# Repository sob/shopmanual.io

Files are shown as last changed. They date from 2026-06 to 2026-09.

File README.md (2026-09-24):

# Technical Documentation

This repository contains comprehensive technical documentation for various in-depth projects, built using [MkDocs](https://www.mkdocs.org/) with the [Material theme](https://squidfunk.github.io/mkdocs-material/).

## Projects

- **Jeep LJ Cummins R2.8 Build** - Complete electrical system documentation for engine swap with dual battery system
- **Nissan NV 3500 Van Build** - 12V accessory electrical system: dual AGM batteries, four switch panels, and Starlink on a DC-fed Advanced Power Supply
- **Jeep Wrangler JKU** - Early documentation: Genesis Offroad dual battery system and a SwitchPros SP-9100 switch panel

## Setup

### Prerequisites

- Python 3.9+
- pip

### Installation

```bash
# Install MkDocs and Material theme
pip3 install mkdocs mkdocs-material
```

### Local Development

```bash
# Serve the documentation locally with live reload
mkdocs serve

# Or use the full path if mkdocs is not in PATH
/Users/seobrien/Library/Python/3.9/bin/mkdocs serve
```

The documentation will be available at [http://127.0.0.1:8000](http://127.0.0.1:8000)

### Building

```bash
# Build static site to site/ directory
mkdocs build

# Or use the full path
/Users/seobrien/Library/Python/3.9/bin/mkdocs build
```

## Project Structure

```
.
├── mkdocs.yml              # MkDocs configuration
├── docs/                   # Documentation source files
│   ├── index.md           # Home page
│   └── jeep_lj/           # Jeep LJ project documentation
│       ├── index.md       # Project overview
│       ├── 01-power-generation.md
│       ├── 02-front-battery-distribution.md
│       ├── 03-rear-battery-distribution.md
│       ├── 04-engine-systems.md
│       ├── 05-auxiliary-systems.md
│       ├── 06-cabin-body-control.md
│       ├── 07-cabin-lighting-accessories.md
│       ├── 08-communication-audio.md
│       ├── 09-cargo-exterior.md
│       ├── 10-wire-routing.md
│       └── 11-project-management.md
└── site/                   # Generated static site (not in git)
```

## Adding New Projects

1. Create a new directory under `docs/` (e.g., `docs/new_project/`)
2. Add an `index.md` overview page
3. Create section files as needed
4. Update `mkdocs.yml` navigation to include the new project
5. Run `mkdocs serve` to preview

## Features

- **Material Design** - Clean, responsive design
- **Dark/Light Mode** - Automatic theme switching
- **Search** - Full-text search across all documentation
- **Navigation** - Hierarchical navigation with sections and tabs
- **Code Highlighting** - Syntax highlighting for code blocks
- **Tables** - Full markdown table support
- **Admonitions** - Info, warning, and note callout boxes

## Documentation Best Practices

- Use clear, descriptive headings (H1-H4)
- Include tables of contents for long pages
- Use admonitions for important notes:
  ```markdown
  !!! info "Title"
      Content here

  !!! warning "Title"
      Warning content
  ```
- Cross-reference between pages using relative links:
  ```markdown
  [Link text](../other-section/page.md)
  ```

## Contributing

When adding or updating documentation:

1. Edit the markdown files in `docs/`
2. Test locally with `mkdocs serve`
3. Verify all links work
4. Check formatting and readability
5. Commit changes to git

## License

Documentation for personal projects.

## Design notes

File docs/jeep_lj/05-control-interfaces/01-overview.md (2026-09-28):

---
hide:
  - toc
---

# Control Interfaces - Overview {#control-interfaces-overview}

This section documents all control interfaces in the Jeep LJ build - the switches, controllers, and input devices that allow the driver to control various vehicle systems.

## System Controllers

- **[SwitchPros SP-1200][switchpros-sp-1200-rcr-force-12]** - Main lighting and accessory controller
  - 12-button control panel with Bluetooth app
  - 17 total outputs (12 main + 5 low-side drivers)
  - 150A capacity, fed by Firewall CONSTANT Bus (via 150A CB)
  - Controls all auxiliary lighting and accessories

- **[Command Touch CT4][command-touch-ct4]** - Steering column turn signal and headlight controller
  - 4 programmable outputs for turn signals and headlights
  - GPS module for intelligent turn signal auto-cancel
  - Replaces factory multifunction stalk
  - Controls turn signals, headlights, and high beams

## Physical Switches

- **[Dashboard Controls][dashboard-physical-controls]** - Physical dash-mounted switches
  - Winch control switch
  - Other dash-mounted controls

- **[Keyless Ignition][keyless-ignition]** - RFID + push-button start/stop replacing the factory keyswitch
  - Digital Guard Dawg PBS-I self-contained module with RFID iTag fobs
  - Single dash push-button included with kit
  - Cold-start grid heater preheat: driver waits for the WAIT-to-Start lamp before cranking
  - Emergency Bypass Card with 4-digit PIN (no hidden toggle)

## System Integration

All control interfaces integrate with the dual-battery electrical system:

- **SwitchPros SP-1200:** Powered by Firewall CONSTANT Bus (sourced from AUX battery via 250A master CB + 2/0 AWG forward feed)
- **Command Touch CT4:** Powered by PMU OUT 13 (15A CONSTANT, sourced from START battery), integrates with PMU
- **Dashboard switches:** Various power sources depending on function

## Related Documentation

- **[Vehicle Lighting][vehicle-lighting-overview]** - Complete vehicle lighting circuits controlled by these interfaces
- **[Offroad Lighting][offroad-auxiliary-lighting]** - Auxiliary and offroad lighting controlled by SwitchPros
- **[Engine Systems][pmu-power-distribution]** - PMU power distribution and engine bay subsystems
- **[Horn][horn]** - CT4 kit horn on PMU Out 18 (engine bay component)
- **[Wipers][windshield-wiper-control-system]** - Ron Francis WS-51C wiper controller (engine bay component)

[switchpros-sp-1200-rcr-force-12]: 02-switchpros-sp1200.md
[command-touch-ct4]: 03-command-touch-ct4.md
[dashboard-physical-controls]: 05-dashboard-controls.md
[keyless-ignition]: 06-keyless-ignition.md
[vehicle-lighting-overview]: ../03-lighting-systems/01-lighting-overview.md
[offroad-auxiliary-lighting]: ../04-offroad-lighting/index.md
[pmu-power-distribution]: ../01-power-systems/04-pmu/index.md
[horn]: ../02-engine-systems/05-horn.md
[windshield-wiper-control-system]: ../02-engine-systems/04-wipers.md

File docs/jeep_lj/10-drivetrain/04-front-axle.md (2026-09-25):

---
tags:
  - product-details
  - drivetrain
  - axle
---

# 10.4 - Front Axle {#front-axle}

/// html | div.product-info

**Type:** Dana 60, high pinion (reverse rotation)

**Source:** 2005-2010 Ford F-350 Super Duty, SRW

**Locker:** ARB RD166 Air Locker

**Axle Shafts:** Factory Dana/Spicer 35 spline

///

## Specifications

| Specification | Value |
| :--- | :---- |
| Type | Dana 60, high pinion reverse rotation |
| Source | 2005-2010 Ford F-350 Super Duty (SRW)[^owner-notes] |
| Differential Drop | **Driver's side** (Ford convention)[^axle-drop] |
| Width (WMS) | 69.25"[^owner-notes] |
| Bolt Pattern | 8x170[^owner-notes] |
| Spline Count | 35 inner, 35 outer[^owner-notes] |
| Tube | 3.5" x 0.500" wall[^owner-notes] |
| Knuckles | Factory cast steel |
| Locker | ARB RD166[^rd166] |

## Ring & Pinion

| Specification | Value |
| :--- | :---- |
| Ratio | 5.13 |
| Manufacturer | Revolution Gear |
| Part | D60 reverse, **standard thickness** |
| Install Kit | D60 reverse master install kit |

!!! warning "Gear Thickness"
    ARB RD166 is the 4.56-and-up carrier. Gear must be standard thickness.
    Do **not** order D60-513RT (thick) or the REV-F350-513-K package.

## Differential

| Specification | Value |
| :--- | :---- |
| Locker | ARB RD166 Air Locker[^rd166] |
| Spline | 35 |
| Carrier Series | 4-series (4.56 & up)[^rd166] |
| Control | Front locker dash switch (fed from the rear switch) |

See [Air Lockers][air-lockers] for wiring, air line routing, and operation.

## Axle Shafts

| Specification | Value |
| :--- | :---- |
| Manufacturer | Dana/Spicer (factory) |
| Spline Count | 35 |
| U-Joint | Spicer SPL55-3X[^owner-notes] |
| Quantity | 4 (2 installed, 2 spare) |

Stock shafts retained. Chromoly and 1550-series joints deferred: the 8" ram
caps steering at 40 degrees, which is where factory 1480-series joints bind,
so larger joints buy no usable angle. Bolt-in upgrade if shafts prove
marginal.[^shafts]

## Hubs

| Specification | Value |
| :--- | :---- |
| Type | Yukon Hardcore manual locking |
| Part | YHC70011[^owner-notes] |
| Spline | 35 |
| Engagement | 1/3 turn |

Factory wheel end retained. Yukon hubs replace factory lockouts. No free-spin
conversion required.

## Ball Joints

| Specification | Value |
| :--- | :---- |
| Type | American Iron ball joint delete |
| Style | Press-fit, welded per AI instructions |
| Bushing Offset | {{ tbd(298) }} (0, 1.5, or 3 degree) |
| Hardware | AI-1900 trail hardware kit |

Upper and lower both required. Lower addresses shaft push-out on breakage.[^bje]

!!! info "Caster Adjustment"
    Bushing offset sets caster and camber together, summing to the bushing
    rating. Every 15 degrees of bushing rotation gives 0.5 degrees of change on
    a 3-degree set. Buying caster at the knuckle avoids rotating the inner Cs,
    which would also rotate the pinion.

## Inner Cs

Factory inner Cs retained, no gussets. Accepted deviation from the
weld-once-for-future-power principle. Revisit only with an engine change.[^bje]

## Housing Preparation

| Item | Part |
| :--- | :--- |
| Truss | Motobilt |
| Differential Cover | Motobilt |
| Pinion Yoke | 1350, 29 spline, strap style[^owner-notes] |
| Breather | Relocated; braided line routed high into the engine bay |

All welding completed before internals installed.

!!! info "ABS and Tone Ring"
    No ABS on this build; speed is GPS-sourced via the Dakota Digital
    [GPS-50-2][bim-gps]. Tone rings omitted. The wheel-end sensor openings take
    Riffraff Diesel **RDPABS** grease-able block-off fittings, **two required**
    — one per knuckle, sold individually.[^abs-plug] These open into the wheel
    end rather than the gear oil, so they keep water and grit out instead of
    sealing a leak path, and the zerk doubles as a grease port for the unit
    bearing. Each is held by the factory ABS sensor bolt, so keep both bolts
    from the donor. The rear housing is a different fitting entirely — see
    [Rear Axle][rear-axle] and {{ tbd(310) }}.

## Steering

| Specification | Value |
| :--- | :---- |
| High Steer Arms | Offroad Anonymous 05-16 SD60 full hydro weld-on[^ora] |
| Ram | PSC 8" double ended (see [Steering][steering]) |
| Ram Mount | Barnes 4WD universal DIY |
| Target Angle | 40 degrees[^ora] |

ORA published travel-to-angle: 8" travel gives 40 degrees, 9" gives 45, 10"
gives 50, measured at the innermost mounting hole. Multiple mounting holes
allow trading angle for mechanical advantage.[^ora]

!!! warning "Steering Stops"
    Stops must satisfy both the u-joint bind angle and ram stroke. Set with
    paint inside the joints, run stops in until paint rubs off, back out one
    turn. Leave 1/8" at each end of ram travel so the cylinder never bottoms
    internally. Verify under load, not by hand.

Ball joint delete clearance against the high steer arms: {{ tbd(299) }}.

## Brakes

Factory Super Duty calipers and rotors. See [Brakes][brakes].

## Outstanding Items

{{ tbds() }}

## Build Tasks

- [ ] Confirm factory hub type before ordering (auto vs manual lockout)
- [ ] Confirm the RDPABS bore matches the 05-10 knuckles in hand, and that both factory ABS sensor bolts came with the donor
- [ ] Set and verify steering stops under load
- [ ] Preheat knuckles before welding high steer arms
- [ ] Cite an OEM or vendor source for WMS width, tube size, and spline counts before bracket layout or wheel order
- [ ] Locate and plumb the axle breather before the truss is welded
- [ ] Confirm the Motobilt cover fill plug clears the truss, and whether it includes a drain plug
- [ ] Lay out link brackets and the ram mount before the truss is welded
- [ ] Verify beadlock clearance to the ram and links at full lock and full droop

## Related Documentation

- [Air Lockers][air-lockers] - Front locker control and air system
- [Driveshafts][driveshafts] - Front shaft yoke and CV
- [Steering][steering] - PSC full hydro system
- [Rear Axle][rear-axle]
- [Brakes][brakes]

[air-lockers]: ../08-exterior-systems/03-air-lockers.md
[driveshafts]: 03-driveshafts.md
[steering]: 07-steering.md
[rear-axle]: 05-rear-axle.md
[brakes]: 08-brakes.md
[bim-gps]: ../02-engine-systems/09-gauge-cluster/04-bim-gps.md
[transfer-case]: 02-transfer-case.md

[^owner-notes]: Owner build notes, 2026-09-16 — donor range, WMS width, bolt pattern, spline counts, tube size, u-joint series, hub part number, and pinion yoke spline. Not yet backed by an OEM or vendor citation; see Build Tasks.
[^axle-drop]: Ford front Dana 60 axles are **driver's-side differential drop** with reverse-cut (high pinion) gears: "Ford versions are driver's side differential drop, reverse-cut gears" (Wikipedia, Dana 60 — Dodge and GM front 60s are passenger-side drop); "All these Ford front axles were drivers side differential, reverse-cut (high pinion) gears, and kingpin knuckles to 1991.5 and balljoints thereafter" (Blue Oval Trucks, "Ford Super Duty Dana 50 vs Dana 60"). Both accessed 2026-09-18. This matches the NP241OR transfer case's driver's-side front output — see [Transfer Case][transfer-case].
[^rd166]: ARB **RD166** — Air Locker, Dana 60HD, 35 spline, 4.56 & up (4-series carrier); $1,399.95 list. [Revolution Gear listing](https://revolutiongear.com/arb-air-locker-rd166-for-dana-60hd-with-35-spline-axles-4-56-and-up/), accessed 2026-09-16. Supersedes the RD116 (30-spline Dana 44) previously specified for the front.
[^ora]: Offroad Anonymous **05-16 Super Duty Dana 60 Weld-On High Steer Kit** (full hydro option) — ORA publishes "8″ steering travel provides 40° steering angle" for the 05-10 knuckle version. [offroadanonymous.com](https://offroadanonymous.com/product/05-16-super-duty-dana-60-weld-on-high-steer-kit/), accessed 2026-09-16. The 9"/45° and 10"/50° figures are owner notes from the same listing.
[^shafts]: Owner decision, 2026-09-16 — factory Dana/Spicer 35-spline shafts retained; chromoly shafts and 1550-series joints deferred because the 40° steering cap set by the 8" ram is where the factory joints bind.
[^bje]: Owner decision, 2026-09-16 — American Iron ball joint delete (upper and lower, welded per AI instructions); factory inner Cs retained without gussets.
[^abs-plug]: Riffraff Diesel **RDPABS**, "Front ABS Grease-able Block Off Fitting 99-16" — "This ABS grease tool will allow you to maintenance your front wheel bearing on the 1999-2016 Dana 50/60 axles. It can be permanently installed for those with only rear ABS or can be used just for greasing then removed." 6061 billet, hard anodized, grease zerk and USA-made Viton o-ring included, "Sold Individually"; $24.82 on sale, $28.33 list. [riffraffdiesel.com](https://www.riffraffdiesel.com/front-abs-grease-able-block-off-fitting-99-16/), accessed 2026-09-21. Riffraff disclaims fit across Dana applications, so confirm the bore against the knuckles in hand. Grease spec per the vendor: lithium-based, non-moly, NLGI #2, GC-LB.

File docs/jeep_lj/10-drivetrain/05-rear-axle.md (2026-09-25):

---
tags:
  - product-details
  - drivetrain
  - axle
---

# 10.5 - Rear Axle {#rear-axle}

/// html | div.product-info

**Type:** Sterling 10.5, full float

**Source:** 2005-2010 Ford F-350 Super Duty, SRW

**Locker:** ARB RD140 Air Locker

**Axle Shafts:** Factory 35 spline

///

## Specifications

| Specification | Value |
| :--- | :---- |
| Type | Sterling 10.5, full float |
| Source | 2005-2010 Ford F-350 Super Duty (SRW)[^owner-notes] |
| Width (WMS) | 68.87"[^owner-notes] |
| Bolt Pattern | 8x170[^owner-notes] |
| Spline Count | 35 (shafts), 31 (pinion)[^owner-notes] |
| Locker | ARB RD140[^rd140] |

!!! info "Housing Identification"
    Corporate Sterling is identified by the absence of a filler hole in the OE
    inspection cover. Housing must be 2010 or earlier; 2011+ went to a
    different pinion spline and 5.13 gears do not exist for it. A 2008-2010
    housing also needs an extra pinion spacer with the gear install kit (see
    Ring & Pinion).

## Ring & Pinion

| Specification | Value |
| :--- | :---- |
| Ratio | 5.13 |
| Manufacturer | Revolution Gear |
| Part | F10.25-513L (long spline)[^gearset] — sourcing {{ tbd(297) }} |
| Install Kit | Revolution 35-2046[^install-kit] |
| 2008-2010 Housing | Add Revolution SK F10.5-Conv pinion spacer (sold separately)[^install-kit] |

!!! warning "Gear and Housing Mismatch"
    There is no 10.5-native 5.13. This is a 10.25" ring gear run in the 10.5
    housing. Revolution supports the combination: the F10.25 long-pinion set
    fits both housings, and 35-2046 is the kit for a 10.5 housing running it
    (not 35-2046A, which is for a factory 10.5 gear).[^gearset] Add
    approximately 0.120" to the pinion depth stack as a starting point, then
    adjust. A solid crush sleeve spacer works without modification despite not
    being listed for the 10.5.[^owner-notes] RD140 fitment with this gear:
    {{ tbd(300) }}.

## Differential

| Specification | Value |
| :--- | :---- |
| Locker | ARB RD140 Air Locker[^rd140] |
| Spline | 35 |
| Ratio Coverage | All ratios (no carrier break)[^rd140] |
| Solenoid Draw | ~2A |
| Control | Rear locker dash switch (BODY PDU CB44 via K27) |
| Air Source | [ARB Twin Compressor][air-compressor] via manifold |

Air locker selected over the Ford factory electric locker (BC3Z-4026-B). The
air system already exists for the front locker, so the marginal cost is one
solenoid and a 6 ft line. The e-locker has no published current draw, requires
a housing pass-through and bulkhead connector, and its 12V-engage / 5V-hold
profile is not reproducible on a SwitchPros output.[^locker-choice]

See [Air Lockers][air-lockers] for wiring, air line routing, and operation.

## Axle Shafts

| Specification | Value |
| :--- | :---- |
| Manufacturer | Factory |
| Type | Full float |
| Spline Count | 35 |

## Brakes

| Specification | Value |
| :--- | :---- |
| Type | Factory Super Duty disc |
| Pads and Rotors | PowerStop Z36 Truck & Tow |
| Park Brake | 8.1" drum-in-hat, mechanical[^owner-notes] |

Factory disc with integrated park brake. No conversion required. Master
cylinder sizing, flex hoses, proportioning, and bias are on the
[Brakes][brakes] page.

## Housing Preparation

| Item | Part |
| :--- | :--- |
| Truss | Motobilt |
| Differential Cover | Motobilt |
| Pinion Yoke | 1350, 31 spline, strap style |
| Brackets | TJ/LJ suspension brackets |
| Breather | Relocated; braided line routed high into the engine bay |

Pumpkin is offset to the passenger side with a longer driver-side tube. Lay
out ORI lower mounts and link brackets before the truss goes on. Pinion
pointed at the transfer case for the CV driveshaft (see
[Driveshafts][driveshafts]).

All welding completed before internals installed.

!!! info "ABS and Tone Ring"
    No ABS on this build; speed is GPS-sourced via the Dakota Digital
    [GPS-50-2][bim-gps]. Tone ring omitted and the sensor opening plugged; an
    unplugged housing opening leaks gear oil. Which opening exists depends on
    the donor year, the same 2008 boundary as the gear install kit[^abs-year]
    — a through-2007 housing has one window to plug, a 2008-2010 housing has
    wheel-end openings instead. Confirm the year on the housing in hand, then
    size the plug: {{ tbd(310) }}. The front wheel ends are settled separately
    (Riffraff RDPABS, see [Front Axle][front-axle]); that fitting does not
    serve the rear.

## Outstanding Items

{{ tbds() }}

## Build Tasks

- [ ] Verify no filler hole in OE inspection cover
- [ ] Confirm donor housing year; it decides both the Revolution SK F10.5-Conv spacer (2008-2010, in addition to kit 35-2046) and which ABS opening needs plugging
- [ ] Confirm park brake hardware complete
- [ ] Cite an OEM or vendor source for WMS width, 8x170 bolt pattern, and spline counts before bracket layout or wheel order
- [ ] Locate and plumb the axle breather before the truss is welded
- [ ] Confirm the Motobilt cover fill plug clears the truss, and whether it includes a drain plug
- [ ] Adjust and verify park brake shoes before the axle goes under the vehicle

## Related Documentation

- [Front Axle][front-axle]
- [Air Lockers][air-lockers] - Locker control, air lines, operation
- [Air Compressor][air-compressor] - ARB Twin Compressor and tank
- [Driveshafts][driveshafts] - Rear shaft yoke and CV
- [Brakes][brakes] - Master cylinder sizing, flex hoses, proportioning valve, park brake
- [Suspension][suspension] - ORI strut and link bracket layout
- [Purchase Tracker][purchase-tracker] - Axle swap parts

[front-axle]: 04-front-axle.md
[air-lockers]: ../08-exterior-systems/03-air-lockers.md
[air-compressor]: ../08-exterior-systems/02-air-compressor.md
[driveshafts]: 03-driveshafts.md
[brakes]: 08-brakes.md
[bim-gps]: ../02-engine-systems/09-gauge-cluster/04-bim-gps.md
[suspension]: 06-suspension.md
[purchase-tracker]: ../09-installation/03-purchase-tracker.md

[^abs-year]: Sterling 10.25/10.5 rear ABS: through 2007 the tone ring mounts to the differential carrier against the ring gear and the sensor reads it through a window in the axle housing; 2008 and later moved to a sensor at each hub with smaller rings. Vendor and service references via [Torque King](https://torqueking.com/products/560954-a560954-abs-tone-ring-for-1985-up-ford-sterling-10-25-or-10-5-rear-axles) and [DieselHub](https://www.dieselhub.com/maintenance/sterling-10.50-differential.html), accessed 2026-09-17. Confirm against the donor housing.
[^owner-notes]: Owner build notes, 2026-09-16 — donor range, housing identification, WMS width, bolt pattern, spline counts, park brake size, pinion depth offset, and the solid spacer note. Not yet backed by an OEM or vendor citation; see Build Tasks.
[^rd140]: ARB **RD140** — Air Locker, "Ford 10.25/10.5 Inch", 35 spline, all gear ratios; $1,399.95. [Revolution Gear listing](https://revolutiongear.com/arb-air-locker-rd140-for-ford-10-25-10-5-with-35-spline-axles-all-gear-ratios/), accessed 2026-09-16. Supersedes the RD116 (30-spline Dana 44) previously specified for the rear.
[^gearset]: Revolution Gear **F10.25-513L** — Ford 10.25" long-pinion 5.13 ring & pinion. Revolution: "Ford 10.25 Inch (Long Pinion) Gear sets can be used in 10.25 Inch and 10.5 Inch Ford Differentials. Master Overhaul Kit P/N 35-2046 is required to use gears in a 10.5 Inch Differential." Revolution Gear dealer listings, accessed 2026-09-16.
[^install-kit]: Revolution **35-2046** — "Fits 1993-99 Ford 10.25 Inch and 1999-2007 10.5 Inch housing with Revolution Gear F10.25 ring and pinion. 2008-10 10.5 Inch housings require spacer for install, sold separately, part number SK F10.5-Conv." [revolutiongear.com](https://revolutiongear.com/revolution-gear-ford-10-25-master-install-kit-use-in-10-5-w-aftmkt-10-25-gear/), accessed 2026-09-16. Do not order **35-2046A**, which is the kit for a factory 10.5" gear.
[^locker-choice]: Owner decision, 2026-09-16 — ARB RD140 over the Ford factory e-locker (BC3Z-4026-B): the air infrastructure already exists for the front locker, and the e-locker's 12V-engage / 5V-hold drive is not reproducible on a SwitchPros output.

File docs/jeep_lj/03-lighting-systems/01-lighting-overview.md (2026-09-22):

---
hide:
  - toc
---

# Vehicle Lighting Overview {#vehicle-lighting-overview}

This section covers all street-legal DOT-required lighting circuits controlled by the Command Touch CT4 and PMU.

## System Components

**Controller:** [Command Touch CT4][command-touch-ct4] - Steering column-mounted multifunction controller

- Turn signal control (left/right) with GPS auto-cancel
- Headlight control (low/high beam)
- Powered by PMU Out 13 (15A CONSTANT) + ignition signal (cabin bus bar Terminal 1)

**Power Distribution:** [PMU][pmu-power-distribution] - Programmable power management

- DRL (Out 23)
- Parking/tail markers (Out 12) — work with ignition off
- Brake lights (Out 21)
- Reverse lights (Out 22)

## Lighting Systems

### Headlights {#headlights-overview}

- **Type:** Baja Designs LP6 DOT LED (complete replacement)
- **Low Beam:** CT4 SW3 (3.6A total) - latching on/off
- **High Beam:** CT4 SW4 (5.6A total) - momentary or latching
- **DRL:** PMU Out 23 (0.8A total) - automatic with ignition, auto-off when headlights on (dedicated output; tail markers are on Out 12)
- **See:** [Headlights][headlights] for complete specifications

### Turn Signals {#turn-signals-overview}

- **Front:** Dedicated amber LED turn signals (CT4 SW1/SW2)
- **Rear:** Integrated into Maxbilt Round Trail Tail lights (YELLOW wire)
- **Features:** GPS auto-cancel, lane change mode, hazard function
- **See:** [Turn Signals][turn-signals] for complete specifications

### Tail, Brake & Reverse Lights {#tail-brake-reverse-overview}

- **Type:** Maxbilt Round Trail Tail LED (4-function)
- **Brake:** PMU Out 21 (3A) - trigger via brake pedal switch
- **Reverse:** PMU Out 22 (5A) - trigger via transmission switch, also activates WolfBox camera
- **Turn:** CT4 SW1/SW2 (internal diode isolation in Maxbilt)
- **Marker/Parking:** PMU Out 12 (parking circuit — follows the headlights, works with ignition off)
- **See:** [Tail, Brake & Reverse][tail-brake-reverse-lights] for complete specifications

### DRL & Parking Lights {#drl-parking-overview}

- **DRL circuit:** PMU Out 23 (7A capacity, 0.8A load) — LP6 DRL only; on with ignition, off when headlights on
- **Parking/tail circuit:** PMU Out 12 (15A capacity, ~2A load) — Maxbilt tail markers + RTL-S running; on whenever the headlights are on (low or high beam), **ignition-independent** — pull the headlights on while parked and the vehicle is lit, like a production car
- **No external relay, no extra switch** - both handled by PMU programming (CT4 SW3/SW4 status on PMU In 7 / In 5)
- **See:** [DRL & Parking Lights][drl-parking-lights] for complete specifications

## Power Sources

| Circuit | Power Source | Capacity | Load |
| :--- | :--- | :--- | :--- |
| CT4 Controller | PMU Out 13 (CONSTANT)  | 15A | ~9A |
| Headlights Low/High | CT4 SW3/SW4 | 10A each | 3.6/5.6A|
| DRL | PMU Out 23 | 7A | 0.8A |
| Parking/Tail Markers| PMU Out 12 | 15A | ~2A |
| Brake Lights | PMU Out 21 | 7A | ~3A |
| Reverse Lights | PMU Out 22 | 7A | ~5A |

## Related Documentation

- [Command Touch CT4][command-touch-ct4] - Controller specifications and programming
- [PMU Power Distribution][pmu-power-distribution] - Power management and programming
- [Offroad Lighting][offroad-auxiliary-lighting] - Auxiliary and offroad lighting circuits
- [Control Interfaces Overview][control-interfaces-overview] - All control interfaces

[command-touch-ct4]: ../05-control-interfaces/03-command-touch-ct4.md
[pmu-power-distribution]: ../01-power-systems/04-pmu/index.md
[headlights]: 02-headlights.md
[turn-signals]: 03-turn-signals.md
[tail-brake-reverse-lights]: 04-tail-brake-reverse.md
[drl-parking-lights]: 05-drl-parking.md
[offroad-auxiliary-lighting]: ../04-offroad-lighting/index.md
[control-interfaces-overview]: ../05-control-interfaces/index.md

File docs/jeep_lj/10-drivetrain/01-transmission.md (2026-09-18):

---
hide:
  - toc
tags:
  - product-details
  - drivetrain
  - transmission
  - 8hp70
---

# 10.1 Transmission - ZF 8HP70 (845RE) {#transmission}

/// html | div.product-info

**Type:** 8-speed automatic transmission

**Model:** ZF 8HP70 (Chrysler 845RE)

**Donor Vehicle:** 2015-2019 RAM 1500 EcoDiesel 4x4

**Torque Capacity:** 520 lb-ft (factory), 700+ lb-ft (built)

**Controller:** Turbolamik TCU 2.0 with basic wiring harness

**Adapter Kit:** Custom (in progress)

///

## Specifications

| Specification | Value |
| :--- | :--- |
| Manufacturer | ZF Friedrichshafen |
| Model | 8HP70 (Chrysler 845RE) |
| Donor | 2015-2019 RAM 1500 EcoDiesel 4x4 |
| Type | 8-speed automatic, 4WD |
| Torque Capacity  | 520 lb-ft (stock) |
| Weight | ~225 lbs (dry) |
| Length | ~27.5" |
| Fluid Capacity | ~9 quarts (pan drop service) |
| Fluid Type | ZF Lifeguard 8 (or equivalent) |

## Gear Ratios

| Gear | Ratio  |
| :--- | :----- |
| 1st | 4.714  |
| 2nd | 3.143  |
| 3rd | 2.106  |
| 4th | 1.667  |
| 5th | 1.285  |
| 6th | 1.000  |
| 7th | 0.839  |
| 8th | 0.667  |
| Reverse | 3.295  |

## Controller - Turbolamik TCU 2.0

/// html | div.product-info

**Model:** Turbolamik TCU 2.0

**Variant:** Basic Wiring Harness (CAN)

**Product Page:** [Turbolamik TCU 2.0][turbolamik]

**Manual:** [Turbolamik Manual][turbolamik-manual]

///

| Specification | Value |
| :--- | :--- |
| Supported Trans | 8HP45, 8HP50, 8HP55, 8HP70, 8HP75, 8HP90, 8HP95 (Gen1/Gen2/Gen3) |
| Shift Speed | 50-150ms |
| Drive Modes | 8 configurable (Street, Race, Offroad, etc.) |
| CAN Protocols | ECUMaster, Haltech, AEM, Motec, MaxxECU, etc. |
| Transbrake | Yes |
| Virtual Clutch | Yes |
| Price | ~€1,880 (~$2,000) with basic harness |

**Why Turbolamik over MaxxECU:**

- Supports all 8HP generations (MaxxECU is Gen1 only)
- Works standalone with Cummins ECM (no torque reduction dependency)
- Proven ECUMaster CAN integration (compatible with PMU24)
- 10+ years development, not beta

## Electrical Requirements

### Power

| Circuit | Wire Gauge | Source | Destination | Notes |
| :--- | :--- | :--- | :--- | :--- |
| TCU Power | 12 AWG | [START+ Forward Dist Bus][start-fwd-bus] (25A CB) | Turbolamik harness (1.8m) | 15A, CONSTANT (must stay on); relocated off PMU OUT16 |
| TCU Ignition | 18 AWG | Ignition bus | Turbolamik harness | Wake-up signal |
| TCU Ground | 14 AWG | Engine bay ground bus | Turbolamik harness | 700mm lead from harness |

**Note:** TCU power must remain active at all times - if power is cut before TCU goes to sleep, adaptations won't save.

### CAN Bus Integration

| Connection | Wire Gauge | Source | Destination | Notes |
| :--- | :--- | :--- | :--- | :--- |
| CAN H | 20 AWG | Turbolamik harness  | Cummins J1939 tap | Twisted pair with CAN L  |
| CAN L | 20 AWG | Turbolamik harness  | Cummins J1939 tap | Twisted pair with CAN H  |

The Turbolamik communicates with the Cummins R2.8 ECM via J1939 CAN for:

- Engine RPM
- Throttle position
- Vehicle speed

**CAN Tap Location:** Same tap point as PMU24 and Dakota Digital (Cummins body harness)

### Sensors & Inputs

| Sensor/Input | Type | Notes |
| :--- | :--- | :--- |
| Input Speed Sensor | Internal to trans | Hall effect |
| Output Speed Sensor | Internal to trans | Hall effect |
| Transmission Temp | Internal to trans | NTC thermistor |
| Range Sensor (BTSI) | Internal to trans | Gear position |
| Shifter Input | Electronic shifter | Kilduff (factory 8HP70 connector) |
| Brake Switch | Digital input | Unlock from Park |

### Aux Outputs (TCU → Vehicle)

| Output | Function | Destination | Notes |
| :--- | :--- | :--- | :--- |
| Aux Out (Reverse) | 12V when shifter in R | [PMU In 3][pmu-inputs] | Drives PMU OUT22 (Reverse Lights) |
| Aux Out (P/N) | 12V when shifter in P or N | **\[Reserve\]** | Not currently consumed; PBS-I handles brake interlock for cranking. Available for future P/N gating if needed. |
| J1939 broadcast | Gear position, trans temp, mode | [BIM-01-2 J1939][bim-j1939] → HDX GEAR | Shares Cummins J1939 bus |

### Shifter

/// html | div.product-info

**Model:** Kilduff 8HP70 / 8 Speed ZF Shifter for Swaps

**Finish:** Red with Skulls

**Product Page:** [Kilduff 8HP70 Shifter][kilduff-shifter]

///

| Specification | Value |
| :--- | :--- |
| Dimensions | 10" L × 4.5" W × 5" H |
| Handle Height | 11" (tallest) |
| Type | Electronic (no cables) |
| Positions | P-R-N-D, +/- manual |
| Connection | Factory 8HP70 connector |
| Mounting | Center console |

**Manual Mode (+/-):** Allows manual gear selection for rock crawling, engine braking on descents, and technical terrain.

**Wiring:** Electronic shifter connects directly to transmission controller. No shift cables required.

### Drive Mode Switch

| Specification | Value |
| :--- | :--- |
| Type | Rocker switch (SPDT or 3-position) |
| Location | Dash rocker switch panel |
| Connection | Transmission controller mode input |

| Position | Mode | Use Case |
| :--- | :--- | :--- |
| Up | Sport | Higher shift points, firmer shifts |
| Center | Normal | Daily driving, highway |
| Down | Tow/Haul | Engine braking, grades, towing |

**Wiring:** Low-current signal wires from rocker switch to transmission controller mode input pins. Exact pinout depends on controller selection (Compushift vs US Shift).

## Cooling

| Component | Notes |
| :--- | :--- |
| Trans Cooler | External cooler recommended |
| Cooler Lines | -6 AN or factory hard lines |
| Thermostat | 180°F bypass thermostat recommended |

## Adapter & Bellhousing

| Component | Source/Part Number | Notes |
| :--- | :--- | :--- |
| Adapter Kit | Custom | R2.8 to 8HP70 (in progress) |
| Flexplate | Adapted from AX15 kit | R2.8 to 8HP70 (custom adapter) |
| Pilot Bearing | {{ tbd(91) }} | If required |

## Outstanding Items

{{ tbds() }}

## Build Tasks

- [ ] Order Turbolamik TCU 2.0 with basic wiring harness
- [ ] Install Turbolamik TCU on 8HP70 mechatronic (soldering required)
- [ ] Route TCU power from START+ Forward Distribution Bus (12 AWG, 25A CB, CONSTANT)
- [ ] Connect TCU CAN to J1939 bus (same tap as PMU/Dakota Digital)
- [ ] Install Kilduff shifter in center console
- [ ] Wire drive mode rocker switch (dash panel) to TCU mode inputs
- [ ] Complete custom adapter kit for R2.8 to 8HP70
- [ ] Complete flexplate adaptation from AX15 kit
- [ ] Determine transmission cooler size and routing

## Related Documentation

- [Transfer Case][transfer-case] - NP241OR connection (adapter re-spec pending)
- [PMU Inputs][pmu-inputs] - J1939 CAN bus tap
- [Cummins R2.8][engine] - Engine CAN integration

[transfer-case]: 02-transfer-case.md
[start-fwd-bus]: ../01-power-systems/02-starter-battery-distribution/index.md#start-forward-bus
[pmu-inputs]: ../01-power-systems/04-pmu/02-pmu-inputs.md
[engine]: ../02-engine-systems/index.md
[starter]: ../02-engine-systems/01-starter.md
[bim-j1939]: ../02-engine-systems/09-gauge-cluster/03-bim-j1939.md
[kilduff-shifter]: https://www.kilduffmachine.com/store/p168/Kilduff_8PH70_%2F_8_speed_ZF_Shifter_for_swaps_%23KIL8HP70.html
[turbolamik]: https://www.turbolamik.us/tcu-2-0-turbolamik/
[turbolamik-manual]: https://manual.turbolamik.eu/

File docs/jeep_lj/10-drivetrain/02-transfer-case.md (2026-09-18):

---
tags:
  - product-details
  - drivetrain
  - transfer-case
---

# 10.2 - Transfer Case {#transfer-case}

/// html | div.product-info

**Model:** NP241OR (Rock-Trac)

**Source:** 2003-2006 Jeep Wrangler TJ/LJ Rubicon

**Type:** Part-time 4WD with 4.0:1 low range

///

## Specifications

| Specification | Value |
| :--- | :---- |
| Model | NP241OR "Rock-Trac"[^model] |
| Source | 2003-2006 TJ/LJ Rubicon (Jeep-only application) |
| Type | Part-time 4WD, two-speed |
| Low Range Ratio | 4.0:1[^lowrange] |
| High Range Ratio | 1.0:1 |
| Modes | 2H, 4H, N, 4L[^model] |
| Rear Output | Centerline, fixed yoke[^output] |
| Front Output | Driver's side[^output] |
| Input | 23-spline short, 1-1/8" stickout (most common variant)[^input] |
| Weight | ≈90 lb[^model] |

## Gear Ratios

| Mode | Ratio |
| :--- | :---- |
| 2WD High | 1.00:1 |
| 4WD High | 1.00:1 |
| Neutral | N/A |
| 4WD Low | 4.0:1 |

## Crawl Ratio

| Component | Ratio |
| :--- | :---- |
| 8HP70 1st gear | 4.714[^trans] |
| Transfer case low | 4.0 |
| Axle (Revolution) | 5.13 |
| **Crawl ratio** | **≈ 96.7:1** (geared) |

Behind an automatic the torque converter multiplies torque further at low speed, so effective crawl is deeper still than the geared figure suggests. That is the accepted tradeoff for the 4:1 — see Selection Notes.

## Selection Notes

The 4:1 Rock-Trac was chosen over the 2.72:1 JK Sport Command-Trac for the deeper low range (owner decision, 2026-09-18).

- **Ratio (primary reason):** 4:1 gives ≈96.7:1 geared versus ≈65.8:1 for the 2.72:1 case. The deeper range is the point — it trades the ability to hold momentum on fast terrain for genuine low-speed control on technical terrain.
- **Converter multiplication — accepted:** paired with the 8HP70 automatic, the converter multiplies torque below stall, pushing effective crawl deeper than 96.7:1. An automatic needs less geared reduction than a manual because the converter handles creep, so this setup will be very slow in 4L-1st. Accepted deliberately.
- **Native to the chassis:** the NP241OR is the factory TJ/LJ Rubicon case, so crossmember mounting and the floor shifter/linkage arrangement are the factory ones for this vehicle rather than adapted from a JK case. Note this does **not** extend to the driveshafts — both are custom Tom Woods units measured at the stretched 110.5" wheelbase regardless of which case is fitted (see [Driveshafts][driveshafts]).
- **Front output side matches the axle:** the NP241OR's front output is on the **driver's side**,[^output] and the Super Duty Dana 60 front axle is a **driver's-side differential drop**.[^axle-drop] The front driveshaft therefore runs down the driver's side without crossing the vehicle — no clearance conflict with the R2.8's oil pan to design around.
- **Strength:** the Rock-Trac's reinforced 4:1 planetary is the heavier-duty variant of the NP241 family. The R2.8's torque is well within either case.

## Adapter (8HP70 → NP241OR)

**An adapter is required — there is no native bolt-up.** The 8HP70 is not the case's factory transmission, so it mates through a transmission-to-transfer-case adapter.[^why-adapter]

**DomiWorks publishes both sides of this exact pairing:** the adapter's fitment list is "NP231, NP241, NP242, NP243, NP246, NP249" from an **8HP70/75 Dodge RAM EcoDiesel** — and the donor here is an 8HP70 EcoDiesel out of a RAM 1500.[^adapter] The NP241OR is an NP241; its 4:1 planetary is internal and does not change the input face the adapter bolts to, so fitment is expected. Confirm in one line with the vendor anyway, since the listing does not spell out the OR variant ({{ tbd(313) }}).

**Specifications:** 115 mm overall, anodized aluminum, case tilt adjustable in 5° increments through a full 360° rotation, with an integrated support bracket for the crossmember and cushions.[^adapter]

- **DomiWorks 24004001** — **$1,005.90** from DriftHQ (US stock), versus ≈8,495 SEK direct from DomiWorks plus import.[^adapter]
- **Alternative — Advance Adapters:** no off-the-shelf 8HP70 → stock NP241OR kit. Their 8HP70 tooling (output assembly 50-9905, housing 51-9905) is built to mate to an Atlas. Their previously noted NP241 input gears are **JK-specific and no longer relevant** to this case. Call to spec a 23-spline build, or go Atlas.

### Parts list (DomiWorks path)

| Part | Source | Notes |
| :--- | :----- | :---- |
| Adapter 24004001 | DriftHQ / DomiWorks | $1,005.90; adapter + integral crossmember bracket |
| 23-spline input gear (ZTNP22390 or equiv.) | Transmission parts supplier | **Required** — DomiWorks specifies a 23-spline input gear and names ZTNP22390. Whether the OR's factory 23-spline gear qualifies as "equivalent" is the open question ({{ tbd(313) }}) |
| NP241OR input bearing + front seal | Rebuild parts | Replace if the input gear is swapped |
| Grade-10.9 mounting hardware | — | Adapter-to-trans / adapter-to-case bolts; inclusion in the kit unconfirmed ({{ tbd(313) }}) |
| Spacer plate | DomiWorks | **Only if** output protrusion exceeds the standard 96 mm — see below |

!!! note "Input gear — the one item that can still force a teardown"
    Both sides being 23-spline is necessary but not sufficient: the gear also has to be dimensionally right for the adapter's 115 mm length and the 8HP70's output. The OR's factory gear was cut for the 42RLE/NSG370, not this adapter. Budget for the ZTNP22390 unless DomiWorks confirms the factory gear works — and note that swapping it means opening the case, which is also when the input bearing and front seal get replaced.

**On the 8HP70 (transmission) side**, the only DomiWorks part is the conditional spacer plate. The 8HP70's factory output shaft is used as-is — it is already a 4WD/transfer-case output (this is a 4x4 Ram donor); no coupler or output adapter is needed from DomiWorks.

**Critical measurement:** DomiWorks' standard fit is **96 mm** from the rear plane to the axle tip. The longer outputs that need the spacer plate are called out as *some Jeep Grand Cherokee EcoDiesel* units, so a RAM 1500 donor is expected to be standard — measure before ordering rather than assume.[^adapter]

## Fluid Specifications

| Specification | Value |
| :--- | :---- |
| Fluid Type | ATF+4 ({{ tbd(313) }} — confirm against the TJ FSM for the OR case) |
| Capacity | {{ tbd(313) }} — fill to the fill-plug overflow |

## 4WD Position Sensing {#position-sensing}

The dash 4WD and 4LO indicators are driven from the case's OEM position switch, translated by the PMU. The NP241OR is cable/lever-shifted and has no discrete position contact, so nothing on the case can ground the HDX 4x4 input directly.

**Sensor:** 5-position transfer case switch, OE **5083138AA** (Omix-Ada 18676.52) — a two-wire resistive plunger switch mounted **on top of the case**, riding the internal shift rail; each detent presents a different resistance.[^tc-switch] This switch is a **listed application for the 03-06 TJ NV241OR**, so the sensor should already be on the case — confirm on the actual unit and record its per-detent resistances ({{ tbd(145) }}).

### Signal chain

| Stage | Path | Active when |
| :---- | :--- | :--- |
| Sense | Position switch → 18 AWG pair → [PMU An 1][pmu-inputs] (divider to 0-5V) | always |
| 4x4 indicator | [PMU OUT19][pmu-outputs] → [firewall pin 19][firewall-ingress] → relay coil (cabin) → contacts ground [HDX 4x4 terminal][hdx-control] | 4H **or** 4L |
| 4LO indicator | [PMU OUT24][pmu-outputs] → [firewall pin 20][firewall-ingress] → [HDX EXTRA(+)][hdx-control], label "4LO" | 4L only |

The HDX 4x4 terminal is ground-activated and EXTRA(+) is 12V-activated, so the 4LO leg drives the HDX directly from a PMU high-side output while the 4x4 leg needs a relay to sink it — the PMU switches high-side only.[^hdx-inputs]

!!! warning "Why the resistive sensor is not wired straight to the HDX"
    2H is the **highest**-resistance detent, not an open circuit, so whether the HDX's fixed input threshold falls between 2H and 4H is unknown — a bare-wire connection could light "4x4" in two-wheel drive. The analog path applies measured thresholds instead, and is also what makes a separate 4LO indication possible. See {{ tbd(145) }}.

**If the switch is missing from the donor case,** it is an available service part (≈$50), or fall back to two discrete ground-closing switches on the shift linkage — 4H+4L → HDX 4x4 terminal, 4L only → HDX EXTRA(−) — which removes the PMU, relay, and both firewall pins from the design.

!!! note "The other connector on the case"
    2003-2006 NP241OR units also carry a **3-wire digital square-wave VSS** on the short tailhousing.[^model] It is unused in this build — the speedometer is driven by the [GPS-50-2 BIM module][bim-gps], not a transfer-case sensor. Cap and label it; do not confuse it with the position switch on top of the case.

## Outstanding Items

{{ tbds() }}

## Build Tasks

- [x] Acquire the NP241OR — **in hand**; the JK NV241 is also on hand and is kept as a spare/fallback[^both-cases]
- [ ] Verify the unit is an OR (4:1) and not a Command-Trac — red and silver tag on the rear identifies it[^model]
- [ ] Re-confirm the adapter path for the OR case with DomiWorks before ordering ({{ tbd(313) }})
- [ ] Measure 8HP70 output-shaft protrusion (≤~96 mm, else order DomiWorks spacer plate or shorten)
- [ ] Confirm the donor case's input spline and stickout against the DomiWorks requirement
- [ ] Confirm the 5-position switch is fitted; record its connector/pinout ({{ tbd(145) }})
- [ ] Measure switch resistance at each detent (2H / 4H / N / 4L) and record the table ({{ tbd(145) }}) — the switch is external, on top of the case, so this is done at its connector while moving the lever through the detents. **Not blocked:** the case is on hand, no teardown and no parts needed[^both-cases]
- [ ] Size the An 1 divider from the measured resistances; set PMU thresholds; verify 2H reads "no 4x4"
- [ ] Cap and label the unused tailhousing VSS connector

## Vendor Inquiry — DomiWorks (draft)

Draft email to confirm fitment and parts before ordering:

Your listing already answers fitment, price, tilt, the crossmember bracket, and the 96 mm protrusion standard. These are the four questions it does not:

```text
Subject: NP241OR (Rubicon 4:1) fitment — Ram 1500 EcoDiesel 8HP70 adapter

Hi DomiWorks,

I'm mating a Ram 1500 EcoDiesel 8HP70 (4x4) to a Jeep TJ Rubicon
NP241OR "Rock-Trac" transfer case (4.0:1 low range, 2003-2006). Your
adapter lists NP241 fitment from the 8HP70/75 EcoDiesel, which is
exactly my pairing, but I want to confirm four things before ordering.

1. The listing says NP241 — does that cover the Rubicon NP241OR
   specifically? I understand the 4:1 planetary is internal and the
   input face is common to the family, but I'd like that confirmed.

2. Input gear: you specify a 23-spline gear, ZTNP22390 or equivalent.
   The NP241OR's factory input is already 23-spline short (1-1/8"
   stickout). Does the factory gear work as-is, or does it have to be
   replaced with the ZTNP22390? This decides whether I need to open the
   case at all.

3. Bearing / seal / hardware: are the input bearing, front seal, and
   adapter mounting bolts included, or separate?

4. Clearance: does the adapter clear the OR case's 5-position position
   switch on top of the case, and the short tailhousing VSS boss?

Donor details:
- Transmission: ZF 8HP70 (Chrysler 845RE), Ram 1500 EcoDiesel, 4x4
- Transfer case: Jeep TJ Rubicon NP241OR Rock-Trac (4:1 low range)

Thanks,
[name]
```

## Related Documentation

- [Transmission][transmission]
- [Driveshafts][driveshafts]
- [HDX Control Module][hdx-control] - 4x4 and EXTRA(+) indicator inputs
- [PMU Inputs][pmu-inputs] - An 1 position sensing
- [PMU Outputs][pmu-outputs] - OUT19 (4x4 relay) and OUT24 (4LO)

[transmission]: 01-transmission.md
[driveshafts]: 03-driveshafts.md
[hdx-control]: ../02-engine-systems/09-gauge-cluster/01-hdx-control.md
[front-axle]: 04-front-axle.md
[bim-gps]: ../02-engine-systems/09-gauge-cluster/04-bim-gps.md
[pmu-inputs]: ../01-power-systems/04-pmu/02-pmu-inputs.md
[pmu-outputs]: ../01-power-systems/04-pmu/03-pmu-outputs.md
[firewall-ingress]: ../01-power-systems/07-wire-routing/02-firewall-ingress.md
[pmu-overview]: ../01-power-systems/04-pmu/01-pmu-overview.md

[^model]: NP241OR "Rock-Trac" — introduced 2003 in the TJ Wrangler Rubicon package, a Jeep-only application. Three shift modes plus low range (2H, 4H, N, 4L), ≈90 lb, identified by a red and silver tag on the rear. 2003-2006 units carry a three-wire digital square-wave VSS on the short tailhousing; 2007+ (JK) dropped it when speed sensing moved to the ABS module. Novak Conversions, "The Novak Guide to the New Process / NVG 241OR RockTrac Transfer Case," accessed 2026-09-18.
[^lowrange]: Low range **4.0:1** — the Rubicon-only Rock-Trac ratio (the non-Rubicon Command-Trac is 2.72:1). Novak Conversions NP241OR guide, accessed 2026-09-18.
[^output]: NP241OR: driver's-side front output, centerline rear output, fixed yoke output assembly. Novak Conversions NP241OR guide, accessed 2026-09-18. Confirm on the actual unit.
[^input]: NP241OR input shaft: most common variant is **23-spline, short (1-1/8" stickout)**; rarer variants are 23-spline flush, 21-spline short, and 26-spline male. The 8HP70 (Ram) output is 23-spline. Novak Conversions NP241OR guide, accessed 2026-09-18. **Confirm the actual donor unit's variant** — the adapter's input-gear requirement depends on it ({{ tbd(313) }}).
[^trans]: ZF 8HP70 (Chrysler 845RE) 1st-gear ratio 4.714 — see [Transmission][transmission].
[^adapter]: DomiWorks Engineering NP231/241/242/243/246/249 → Dodge 8HP70/75 EcoDiesel adapter. Published fitment: "NP231, NP241, NP242, NP243, NP246, NP249" from 8HP70/75 Dodge RAM EcoDiesel, RAM 1500, Jeep Grand Cherokee EcoDiesel, and JGC Hemi 5.7/6.0. Specs: 115 mm overall, anodized aluminum, tilt adjustable "in 5 degrees increment, 360 full rotation," "integrated support bracket for easy integration of crossmember and cushions." Requires a 23-spline transfer case input gear, "ZTNP22390 or equivalent." Standard output protrusion 96 mm from rear plane to axle tip; longer units (some Jeep Grand Cherokee EcoDiesel) need the spacer plate. **$1,005.90 USD** — [DriftHQ listing](https://drifthq.com/products/domiworks-engineering-np231-241-242-243-246-249-transfer-case-adapter-to-dodge-8hp70-75-ecodiesel-ram-1500), accessed 2026-09-18; ≈8,495 SEK direct from DomiWorks, accessed 2026-05-31. Prices subject to change. The listing does not name the NP241**OR** variant specifically — see {{ tbd(313) }}. Advance Adapters 8HP70 tooling (output assembly 50-9905 $642.51, housing 51-9905 $371.11), accessed 2026-05-31.
[^both-cases]: Owner confirmation, 2026-09-18 — both the NP241OR and the previously spec'd JK NV241 GenII are on hand. No transfer case needs sourcing, and the position-switch measurement for {{ tbd(145) }} can be done on the bench now.
[^axle-drop]: Ford front Dana 60 axles are **driver's-side differential drop** with reverse-cut (high pinion) gears: "Ford versions are driver's side differential drop, reverse-cut gears" (Wikipedia, Dana 60); "All these Ford front axles were drivers side differential, reverse-cut (high pinion) gears, and kingpin knuckles to 1991.5 and balljoints thereafter" (Blue Oval Trucks, "Ford Super Duty Dana 50 vs Dana 60"). Both accessed 2026-09-18. Matches the NP241OR's driver's-side front output — see [Front Axle][front-axle].
[^tc-switch]: 5-position transfer case switch, OE **5083138AA** (Omix-Ada 18676.52, Crown 5083138AA), mounted on top of the case. Listed applications include **2003-2006 Wrangler TJ with the NV241OR**, 2007-2018 JK, WJ Grand Cherokee with NV242/NV247, and KJ Liberty with NV231/NV242. Omix-Ada / Quadratec / Crown Automotive product listings, accessed 2026-09-18. **Per-detent resistance values are not published for this application — measure at teardown** ({{ tbd(145) }}). Values circulating on forums (2WD ≈1.1-1.2 kΩ … 4L ≈60 Ω) are for a Liberty/Selec-Trac application and are NOT applicable here.
[^hdx-inputs]: Dakota Digital HDX manual MAN 650542H, p.13: "**4x4 (−)** — The 4x4 input is activated by a ground signal from a switch on the transfer case… Whenever the 4x4 input is grounded a green 4x4 indicator will be shown on the Home Screen"; "**EXTRA (+)** — This is an extra indicator input that is activated by +12V. When activated, a custom label is displayed on the TFT" (8 characters max, p.31). PMU high-side-only switching per [PMU Overview][pmu-overview].
[^why-adapter]: The 8HP70 is not the NP241OR's factory transmission (the TJ Rubicon paired it with the 42RLE automatic or NV3550/NSG370 manual), so an adapter is required. The 8HP *family* does pair with an NV241 from the factory — the JL Wrangler automatic bolts an 850RE/8HP75 to one — but the Ram EcoDiesel 8HP70's bolt pattern only *resembles* the Jeep 850RE and is not interchangeable, and no direct Ram-8HP70-to-Jeep-case kit is on the market. The transmission is fixed (Turbolamik TCU + Kilduff shifter are spec'd to the 8HP70). jlwranglerforums.com 8-speed swap PSA / Advance Adapters 5054 (JL 850RE / Dodge 8HP70 → Atlas), accessed 2026-05-31.

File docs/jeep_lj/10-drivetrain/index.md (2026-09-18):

---
hide:
  - toc
---

# Section 10: Drivetrain {#drivetrain}

Complete drivetrain system documentation for the Jeep LJ build.

## Contents

| Section | Component | Description |
| :--- | :--- | :--- |
| [10.1][transmission] | Transmission | ZF 8HP70 (845RE), 8-speed automatic |
| [10.2][transfer-case] | Transfer Case | NP241OR Rock-Trac (TJ/LJ Rubicon), 4.0:1 low range |
| [10.3][driveshafts] | Driveshafts | Front and rear driveshafts |
| [10.4][front-axle] | Front Axle | Super Duty Dana 60 high pinion (2005-2010 F-350 SRW), 5.13 Revolution, ARB RD166 locker, factory 35-spline shafts |
| [10.5][rear-axle] | Rear Axle | Sterling 10.5 (2005-2010 F-350 SRW), 5.13 Revolution, ARB RD140 locker |
| [10.6][suspension] | Suspension | ORI struts - 14" front, 16" rear |
| [10.7][steering] | Steering | PSC full hydraulic steering |
| [10.8][brakes] | Brakes | Super Duty discs at four corners, PowerStop Z36, Wilwood 1-1/8" master |

## System Overview

**Axles:**

- Front: Ford Super Duty Dana 60 high pinion (2005-2010 F-350 SRW) with ARB RD166 air locker, factory 35-spline shafts, Yukon manual hubs
- Rear: Ford Sterling 10.5 (2005-2010 F-350 Super Duty SRW) with ARB RD140 air locker, factory 35-spline full-float shafts
- Gear ratio 5.13 both ends (Revolution Gear); bolt pattern 8x170

**Drivetrain:**

- Transmission: ZF 8HP70 (845RE) - 8-speed automatic from 2015-2019 RAM 1500 EcoDiesel 4x4
- Transfer Case: NP241OR Rock-Trac (2003-2006 TJ/LJ Rubicon) - 4.0:1 low range (≈96.7:1 geared crawl)
- Front Driveshaft: Custom (Tom Woods) - measure at final ride height
- Rear Driveshaft: Custom (Tom Woods) - measure at final ride height

**Suspension:**

- Wheelbase: 110.5" (stretched ~7" from stock 103.4")
- Front: ORI 14" bypass struts
- Rear: ORI 16" bypass struts

**Steering:**

- PSC Motorsports full hydraulic steering

**Brakes:**

- Factory Super Duty discs at four corners, Bosch iBooster, Wilwood 1-1/8" master; see [Brakes][brakes]

## Outstanding Items

{{ tbds() }}

## Build Tasks

- [ ] Document driveshaft specifications

## Related Documentation

- [Air Lockers][air-lockers] - ARB locker control and air system

[transmission]: 01-transmission.md
[transfer-case]: 02-transfer-case.md
[driveshafts]: 03-driveshafts.md
[front-axle]: 04-front-axle.md
[rear-axle]: 05-rear-axle.md
[suspension]: 06-suspension.md
[steering]: 07-steering.md
[brakes]: 08-brakes.md
[air-lockers]: ../08-exterior-systems/03-air-lockers.md

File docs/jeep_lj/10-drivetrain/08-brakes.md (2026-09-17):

---
tags:
  - product-details
  - drivetrain
  - brake-system
---

# 10.8 - Brakes {#brakes}

/// html | div.product-info

**Type:** Four-wheel disc, electro-hydraulic boost

**Calipers and Rotors:** Factory Ford Super Duty, four corners

**Pads and Rotors:** PowerStop Z36 Truck & Tow, front and rear

**Booster:** Bosch Gen 2 iBooster (see [Brake Booster][brake-booster])

**Master Cylinder:** Wilwood Tandem Compact, 1-1/8" bore

**Park Brake:** Factory drum-in-hat, mechanical lever

**ABS:** None. Tone rings and wheel speed sensors omitted at both axles.

///

Axle-side brake hardware and system sizing for the Super Duty axles. The
booster, master cylinder mounting, adapter, harness, firewall plate, and
plumbing are documented on the [Brake Booster][brake-booster] page.

## Calipers and Rotors

| Corner | Hardware |
| :----- | :--- |
| Front | Factory Super Duty caliper and rotor ([Front Axle][front-axle], Dana 60) |
| Rear | Factory Super Duty caliper and rotor with drum-in-hat park brake ([Rear Axle][rear-axle], Sterling 10.5) |
| Pads and Rotors | PowerStop Z36 Truck & Tow kit, front and rear, 2005-2007 F-250/F-350 SRW application[^owner-notes] |

!!! warning "Kit Year Range"
    The Z36 kit application is listed as 2005-2007. The donor axles can be
    2005-2010. Match the kit to the donor axle years before ordering.

## Booster and Master Cylinder

| Specification | Value |
| :--- | :---- |
| Booster | Bosch Gen 2 iBooster, direct mechanical pushrod, M8x1.25[^owner-notes] |
| Pedal Ratio | Approximately 4:1; verification {{ tbd(301) }} |
| Master Cylinder | Wilwood Tandem Compact, 1-1/8" bore[^mc-bore] |
| MC Adapter | Back Bay Customs (see [Brake Booster][brake-booster]) |
| Harness | {{ tbd(105) }} — Tulay's Gen 2 or EVcreate kit (see [Brake Booster][brake-booster]) |
| Firewall Plate | 60x80mm pattern (see [Brake Booster][brake-booster]) |

!!! info "Master Cylinder Sizing"
    The 1-1/8" bore is sized for knockback margin with the Super Duty calipers,
    not steady-state caliper volume. It supersedes the 1.00" bore chosen for the
    TJ Rubicon calipers.[^mc-bore]

## Park Brake

Factory drum-in-hat in the rear rotors, mechanical lever. Cables built at full
droop.[^owner-notes]

## Lines and Proportioning

- Braided flex hoses at each axle, measured at full droop ({{ tbd(86) }}); plumbing on the [Brake Booster][brake-booster] page
- Adjustable proportioning valve on the rear circuit ({{ tbd(60) }}). With no ABS this valve is the only rear lockup control, so set it on a low-grip surface rather than by the bias figure alone
- Front/rear bias starting point approximately 62/38[^owner-notes]

## Outstanding Items

{{ tbds() }}

## Build Tasks

- [ ] Confirm the Back Bay Customs adapter fits the 1-1/8" Tandem Compact (vendor confirmed it against the 1.00" 260-15542)
- [ ] Match the Z36 kit application to the donor axle years
- [ ] Measure flex hose and park brake cable lengths at full droop
- [ ] Cite OEM or vendor sources for the Z36 kit application, pushrod thread, and pedal ratio

## Related Documentation

- [Brake Booster][brake-booster] - iBooster, master cylinder, adapter, harness, firewall plate, plumbing
- [Front Axle][front-axle]
- [Rear Axle][rear-axle]
- [Suspension][suspension] - Droop for hose and cable lengths

[brake-booster]: ../02-engine-systems/02-brake-booster.md
[front-axle]: 04-front-axle.md
[rear-axle]: 05-rear-axle.md
[suspension]: 06-suspension.md

[^owner-notes]: Owner build notes, 2026-09-16 — Z36 kit application, pushrod thread, park brake cable and hose lengths at full droop, 62/38 bias starting point. Not yet backed by an OEM or vendor citation; see Build Tasks.
[^mc-bore]: Owner decision, 2026-09-16 — Wilwood Tandem Compact 1-1/8" bore, sized for knockback margin with the Super Duty calipers. Supersedes the 1.00" 260-15542 selected 2026-05-30 for the TJ Rubicon calipers. Wilwood lists the 1-1/8" Tandem Compact as 260-15541 (noted on the Brake Booster page, checked 2026-05-30); confirm the part number and the Back Bay adapter fitment before ordering.

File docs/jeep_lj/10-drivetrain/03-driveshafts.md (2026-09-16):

# 10.3 - Driveshafts

Both driveshafts are custom units built to measured length by Tom Woods Custom Drive Shafts after the drivetrain and suspension are mocked up at final ride height.[^driveshaft-vendor]

## Front Driveshaft

| Specification | Value |
| :--- | :---- |
| Type | Custom (Tom Woods Custom Drive Shafts) |
| Length | {{ tbd(93) }} — measure at final ride height |
| U-Joint | {{ tbd(93) }} — per Tom Woods build spec |
| Series | 1350 CV[^series] |
| Axle End | 1350 strap-style pinion yoke, 29 spline — see [Front Axle][front-axle] |

## Rear Driveshaft

| Specification | Value |
| :--- | :---- |
| Type | Custom (Tom Woods Custom Drive Shafts) |
| Length | {{ tbd(94) }} — measure at final ride height |
| U-Joint | {{ tbd(94) }} — per Tom Woods build spec |
| Series | 1350 CV[^series] |
| Axle End | 1350 strap-style pinion yoke, 31 spline — see [Rear Axle][rear-axle] |
| Transfer Case End | CV; rear pinion aimed at the transfer case output |

## Outstanding Items

{{ tbds() }}

## Build Tasks

- [ ] Measure front driveshaft length at final ride height and order from Tom Woods
- [ ] Measure rear driveshaft length at final ride height and order from Tom Woods

[^series]: Owner build notes, 2026-09-16 — both shafts 1350-series CV from Tom Woods, matched to the 1350 strap-style pinion yokes on the Super Duty axles.
[^driveshaft-vendor]: Owner decision, 2026-05-30 — custom shafts sourced from Tom Woods Custom Drive Shafts; length and U-joint series are determined by Tom Woods from the measured working length at final ride height.

## Related Documentation

- [Transfer Case][transfer-case]
- [Front Axle][front-axle]
- [Rear Axle][rear-axle]

[transfer-case]: 02-transfer-case.md
[front-axle]: 04-front-axle.md
[rear-axle]: 05-rear-axle.md

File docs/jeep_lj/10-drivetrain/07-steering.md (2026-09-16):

---
tags:
  - product-details
  - drivetrain
  - steering
---

# 10.7 - Steering {#steering}

/// html | div.product-info

**Type:** Full hydraulic steering

**Manufacturer:** PSC Motorsports

///

Full hydraulic steering with no mechanical linkage: a PSC pump feeds a PSC orbital steering control valve, which drives a double-ended ram. Ram stroke is limited by steering stops set to the u-joint bind angle and ram travel, and the ram mounts on a Barnes 4WD universal DIY ram mount to Offroad Anonymous weld-on high steer arms on the Super Duty Dana 60 (see [Front Axle][front-axle]). A Mishimoto fluid cooler with fan (gated by a 180 °F inline thermostat) cools the circuit.[^steering-config]

Component part numbers below come from the PSC **FHK400TJ** kit — the 1997-2006 TJ/LJ Extreme Series full hydraulic kit with a 2.75" double-ended cylinder (PSC's 40"+ tire kit).[^psc-kit] The orbital valve and cylinder carry over directly; the kit **pump is the exception** — its PK40JP2-FH bracket is Jeep 4.0L-specific and does not fit this build's Cummins R2.8.

## Specifications

| Component | Specification |
| :--- | :--- |
| Type | Full hydraulic (no mechanical linkage) |
| Kit | PSC FHK400TJ (TJ/LJ Extreme Series, 2.75" double-ended) |
| Steering Control Valve | PSC 160cc orbital (in FHA160-S accessory kit) |
| Ram | PSC SC2227K1 (2.75" × 8.0" double-ended) |
| Pump | Cummins-specific PSC pump — {{ tbd(99) }} (kit PK40JP2-FH is 4.0L-only) |
| Reservoir | Remote (included with pump kit) — model {{ tbd(103) }} |
| Cooler | Mishimoto fluid cooler + fan (180 °F inline thermostat) |
| Fluid | PSC 715 (SWEPCO 715) |

## System Components

### Hydraulic Pump

> **Pump is engine-specific — the kit pump does not fit.** The FHK400TJ kit ships a **PK40JP2-FH** pump kit built for the Jeep **4.0L** accessory drive. This build runs a **Cummins R2.8**, so the kit pump/bracket does not bolt up — a Cummins-compatible PSC pump must be sourced. The kit's orbital valve and cylinder are engine-agnostic and carry over unchanged.

| Specification | Value |
| :--- | :---- |
| Manufacturer | PSC Motorsports |
| Model | {{ tbd(99) }} — Cummins R2.8 pump + bracket (NOT the kit's PK40JP2-FH) |
| Flow Rate | {{ tbd(99) }} |
| Pressure | {{ tbd(99) }} |
| Drive | {{ tbd(99) }} (belt vs. Cummins gear-drive) |

### Steering Control Valve

| Specification | Value |
| :--- | :---- |
| Type | Orbital (PSC) |
| Model | 160cc — supplied in PSC FHA160-S accessory kit |

### Steering Ram

| Specification | Value |
| :--- | :---- |
| Type | Double-ended (PSC) |
| Model | SC2227K1 |
| Bore | 2.75" |
| Stroke | 8.0" native; effective stroke set by steering stops (40 degree target, see [Front Axle][front-axle]) |
| Mount | Barnes 4WD universal DIY ram mount; ORA 05-16 SD60 full hydro high steer arms (see [Front Axle][front-axle]) |

### Reservoir

| Specification | Value |
| :--- | :---- |
| Type | Remote (included with PSC pump kit) |
| Capacity | {{ tbd(103) }} |
| Location | {{ tbd(103) }} |

### Cooler

| Specification | Value |
| :--- | :---- |
| Unit | Mishimoto fluid cooler |
| Fan | Mishimoto (matched to cooler) |
| Control | 180 °F inline thermostat |
| Fan Current Draw | {{ tbd(101) }} (confirm fits PMU Out 8 ~15A budget) |
| Fan Power Source | PMU Out 8 (~15A, thermostat-switched) — see [PMU Outputs][pmu-outputs] |

## Fluid Specifications

| Specification | Value |
| :--- | :---- |
| Fluid Type | PSC 715 (SWEPCO 715) |
| Capacity | {{ tbd(103) }} (kit ships ~4 qt; confirm system fill) |

## Outstanding Items

{{ tbds() }}

## Build Tasks

- [ ] Source a Cummins R2.8-compatible PSC pump + bracket (kit PK40JP2-FH is 4.0L-only)
- [ ] Confirm pump drive type (belt vs Cummins gear-drive), flow rate, and pressure
- [ ] Confirm remote reservoir model and mounting location
- [ ] Confirm fluid system fill quantity
- [ ] Confirm Mishimoto cooler fan current draw fits the PMU Out 8 (~15A) budget
- [ ] Document hydraulic line routing

[^steering-config]: Owner decision, 2026-05-30 — full-hydro kit is PSC pump + PSC orbital valve + PSC double-ended ram; Busted Knuckle Off-Road steering stops limit ram stroke to Dana 44 spec; Artec Industries Dana 60 ram mount cut down to the Dana 44; Mishimoto fluid cooler + fan on a 180 °F inline thermostat. Model numbers, bore/stroke values, flow/pressure, and fluid specs remain pending. Updated 2026-09-16 with the Dana 60 front: the Busted Knuckle stops and the cut-down Artec mount are superseded by the Barnes 4WD universal mount and ORA high steer arms (see Front Axle).
[^psc-kit]: PSC Motorsports **FHK400TJ** — 1997-2006 Jeep TJ/LJ Extreme Series full hydraulic kit, 2.75" double-ended cylinder (PSC Motorsports / pscsteering.com, accessed 2026-05-31). Kit boxes: **FHA160-S** (160cc full-hydraulic accessory kit w/ orbital valve), **PK40JP2-FH** (high-flow pump kit — **Jeep 4.0L bracket**, not used here), **SC2227K1** (2.75" × 8.0" double-ended cylinder); fluid PSC/SWEPCO 715. Smaller-tire variant is **FHK100TJ** (2.5" bore / 125cc valve, 35-42"). Pump bracket is 4.0L-specific, so it does not fit this build's Cummins R2.8 — valve and cylinder carry over.

## Related Documentation

- [Front Axle][front-axle]
- [Suspension][suspension]

[front-axle]: 04-front-axle.md
[suspension]: 06-suspension.md
[pmu-outputs]: ../01-power-systems/04-pmu/03-pmu-outputs.md

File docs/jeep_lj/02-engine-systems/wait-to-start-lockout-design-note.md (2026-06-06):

---
hide:
  - toc
tags:
  - design-note
  - engine-systems
  - starter
  - keyless
search:
  exclude: false
---

# WAIT-to-Start Crank Lockout — Design Note (Deferred)

!!! warning "Status: NOT IMPLEMENTED — deferred by design"
    The build does **not** automatically lock out cranking during grid-heater
    preheat. The current design is **watch the lamp**: on a cold start the driver
    waits for the Cummins WAIT-to-Start lamp to extinguish before cranking — Digital
    Guard Dawg's own documented diesel start procedure. See [Starter System][starter]
    and [Keyless Ignition][keyless-ignition].

    This page preserves the full analysis so that, if an automatic lockout is ever
    revived, the design and the dead ends are already mapped out. It is intentionally
    **only linked from the [Starter System][starter] page** and is not in the main nav.

## Why it was deferred

An automatic lockout was evaluated in depth and set aside as **not worth the complexity** for this build:

- **Skipping the wait is harmless.** On a common-rail R2.8 the grid heater is an ECM-managed cold-start *aid*; cranking during preheat doesn't damage anything — worst case is a marginally harder fire. The WAIT lamp is advisory, not a protection interlock.
- **It's a 3–5 second wait, once per cold start** (per [Grid Heater][grid-heater]), and watching the lamp is the **manufacturer's documented diesel procedure**.
- **Every automatic option adds disproportionate cost** — parts, wiring, and/or coupling the start path to another module — to automate something a glance handles.
- **Direction of travel.** Critical systems (TCU, iBooster) are being moved *off* the PMU; adding the crank lockout *onto* the PMU runs against that.

## The requirement (if revived)

Block the crank signal while the WAIT lamp is on, ANDed with the PBS-I crank command, **without loading ECM Pin 35**:

- **WAIT signal:** ECM **Pin 35** (yellow), sink-circuit lamp topology — **active LOW** (~0 V when WAIT on, ~13 V off).[^wait-polarity]
- **Constraint:** the Pin 35 lamp-driver **sink-current rating is not published** in any public Cummins crate document, so a design must not lean on it. A relay coil on Pin 35 (~160 mA) was the original concern tracked as issue #117.[^pin35-rating]
- **AND logic:** crank only when the PBS-I is commanding START *and* WAIT is off.
- **Fail-safe:** any fault must default to **crank-enabled** (engine still starts).

## Options evaluated

| Approach | Auto? | Loads Pin 35? | Verdict |
| :--- | :---- | :--- | :--- |
| Original Bosch changeover relay, coil on Pin 35 | ✅ | ❌ ~160 mA | Rejected — this is #117 |
| Confirm the Cummins sink rating on paper | — | — | Dead end — not in public docs |
| Bench-measure lamp + coil draw | — | — | Measures draw, not the limit — insufficient |
| Opto / SSR high-impedance buffer | ✅ | ✅ ~µA | Works, but it's loose electronics (rejected: error-prone, hard to troubleshoot) |
| Low-coil-current **plug-in** relay (~30 mA) | ✅ | ⚠️ ~30 mA | **Does not exist off-the-shelf** — plug-in automotive relays are all ~150 mA; low-power coils are PCB-mount only |
| Enclosed automotive SSR (MRS 1.069) | ✅ | ✅ | Doesn't fit — high-side output fights the series AND; "don't energize I/O unpowered" caution; 6.3 mm body |
| ISO 280 **micro** SSR (to fit BODY PDU sockets) | ✅ | ✅ | Doesn't exist — micro footprint is electromechanical-only |
| PBS-I built-in crank delay (~7 s) | ⏱️ timer | ✅ none | Blind timer, not lamp-sensed; covers typical preheat only |
| iKey Premier sensed wait (Pink wire, 18 s) | ✅ | ✅ | **Remote-start only** — not active for driver-present push-button start |
| **PMU-sensed gate relay** (see below) | ✅ | ✅ ~µA | The clean implementation if revived |
| **Watch the lamp** | ❌ manual | ✅ none | **Chosen** — zero parts, mfr procedure |

## Recommended implementation, if revived

A relay-based gate where the **PMU is only the sensor**, never in the crank path. This was fully worked out and is the design to resurrect:

```text
PMU In 4  ← ECM Pin 35 (WAIT lamp)        high-Z digital input → ~µA on Pin 35
PMU Out 24 → gate-relay coil+             (from +12, NOT Pin 35); coil− to cabin ground
relay NC   in series:  PBS-I PURPLE START → relay COM → NC → firewall Pin 15 → Cole Hersee coil+
```

- **PMU logic:** `IF In4_WaitToStart == LOW THEN Out24 = ON (block) ELSE OFF (pass)`.
- **Behavior:** WAIT on → PMU energizes relay → NC opens → crank blocked. WAIT off → relay drops → NC closed → start passes.
- **Zero Pin 35 load:** the PMU senses with a high-impedance input; the relay coil is driven from the PMU output, so the coil current never touches Pin 35 — a standard ~150 mA relay is fine.
- **Block-only:** the PMU drives the *relay coil*, not the starter solenoid, so it can only interrupt an already-authorized PBS-I crank, never command one.
- **Fail-safe, no bypass needed:** dead/unpowered PMU, failed Out 24, or open coil → relay de-energized → NC closed → PBS-I cranks. A dead PMU also stops the cooling fan, so the start path is never the limiting failure.

**Proposed I/O (both currently spare):** PMU **In 4** (WAIT sense) and **Out 24** (gate-relay coil, ~0.16 A). See [PMU Inputs][pmu-inputs] / [PMU Outputs][pmu-outputs].

**Parts:**

- Gate relay: any standard 12 V SPDT (changeover) automotive relay wired SPST-NC; NC contact carries only the ~0.69 A Cole Hersee coil. Mount cabin, adjacent to the PBS-I.
- (Optional limp-home, not required) a manual bypass across the relay's COM↔NC — a latching illuminated push-button such as the **Blue Sea 4160** (build standard) glowing when engaged, or simply a spare relay / a COM-NC jumpered "bypass plug" in the glovebox. The NC topology already self-enables on the common faults, so this is belt-and-suspenders.

## Why not the simpler-looking alternatives

- **No off-the-shelf "WAIT-gate" module exists.** Plug-in SSRs don't come in a form that does a fail-safe series AND of two 12 V signals, and low-coil-current relays only exist as PCB parts. Anything that gets Pin 35 to ~zero load while staying a finished, plug-in product ends up being the PMU (sensor) + relay (gate) above.
- **It can't live in the BODY PDU.** The Bussmann LR-2 uses ISO 280 micro relays (~150 mA coils → re-creates #117), and it's a high-side power panel, not a series-signal-gate host.

## Sources

[^wait-polarity]: **Active-low confirmed.** Cummins Repower R2.8 CM2220 R101B Installation Guide, Bulletin 5504137 (Jan 2018), §2 *Wiring Harness* / *Engine Indicator Lamps*: "Lamp, Wait To Start — Yellow — ECM pin 35"; lamps are fed +12 V from the keyswitch with the ECM "providing a path to ground via a sink circuit." Full schematic = Wiring Diagram Bulletin 5467560 (QuickServe Online). Also documented on [HDX Control][hdx-control].

[^pin35-rating]: The CM2220 lamp-driver sink-current rating is **not published** in the public crate documents (Installation Guide 5504137, spec flyer 5410825, Wiring Diagram 5467560, Lamp ID card 4971518) — same gap the grid-heater current carries. It would require Cummins QuickServe / Care to obtain. This is why a design that *senses* Pin 35 (high-Z) is preferred over one that *loads* it.

## Related Documentation

- [Starter System][starter] - The crank circuit this would gate (sole inbound link to this note)
- [Keyless Ignition][keyless-ignition] - PBS-I architecture and the current watch-the-lamp cold-start sequence
- [Grid Heater System][grid-heater] - R2.8 preheat duty cycle (3–5 s typical)
- [HDX Control][hdx-control] - ECM Pin 35 WAIT signal and its active-low sourcing

[starter]: 01-starter.md
[keyless-ignition]: ../05-control-interfaces/06-keyless-ignition.md
[grid-heater]: 07-grid-heater.md
[hdx-control]: 09-gauge-cluster/01-hdx-control.md
[pmu-inputs]: ../01-power-systems/04-pmu/02-pmu-inputs.md
[pmu-outputs]: ../01-power-systems/04-pmu/03-pmu-outputs.md

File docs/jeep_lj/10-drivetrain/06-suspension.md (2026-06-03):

---
tags:
  - product-details
  - drivetrain
  - suspension
---

# 10.6 - Suspension {#suspension}

/// html | div.product-info

**Type:** Coilover bypass

**Front:** ORI Struts 14"

**Rear:** ORI Struts 16"

///

## Specifications

| Specification | Value |
| :--- | :---- |
| Wheelbase | 110.5" (stretched from 103.4" stock) |
| Approach Angle | 87.1° |
| Departure Angle | {{ tbd(102) }} |
| Breakover Angle | {{ tbd(102) }} |
| Type | Coilover bypass struts |
| Front Travel | 14" |
| Rear Travel | 16" |
| Manufacturer | ORI (Off Road International) |

## Front Suspension

| Component | Specification |
| :--- | :--- |
| Struts | ORI 14" |
| Coil Rate | {{ tbd(97) }} |
| Bypass Valving | {{ tbd(97) }} |
| Control Arms | {{ tbd(97) }} |
| Track Bar | {{ tbd(97) }} |
| Sway Bar | {{ tbd(97) }} |

## Rear Suspension

| Component | Specification |
| :--- | :--- |
| Struts | ORI 16" |
| Coil Rate | {{ tbd(98) }} |
| Bypass Valving | {{ tbd(98) }} |
| Control Arms | {{ tbd(98) }} |
| Track Bar | {{ tbd(98) }} |
| Sway Bar | {{ tbd(98) }} |

## Outstanding Items

{{ tbds() }}

## Build Tasks

- [ ] Document ORI strut part numbers
- [ ] Document coil rates
- [ ] Document bypass valving configuration
- [ ] Document control arm specifications
- [ ] Document track bar specifications

## Related Documentation

- [Front Axle][front-axle]
- [Rear Axle][rear-axle]
- [Steering][steering]

[front-axle]: 04-front-axle.md
[rear-axle]: 05-rear-axle.md
[steering]: 07-steering.md

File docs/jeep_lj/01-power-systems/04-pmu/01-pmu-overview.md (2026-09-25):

---
hide:
  - toc
tags:
  - product-details
  - power-distribution
  - pmu
  - controller
---

# 1.4.1 PMU Overview {#pmu-overview}

/// html | div.product-info
ECUMaster PMU24 DL

**Type:** Programmable Power Management Unit with Data Logging

**Model:** ECUMaster PMU24 DL

**Manufacturer:** ECUMaster

**Product Page:** [ECUMaster PMU24 DL][ecumaster-pmu24]

**Installation Manual:** [PMU User Manual v101.1.5 (PDF)][pmu-manual]

**Pinout Diagram:** [PMU-24 Pinout v1.1 (PDF)][pmu-pinout]

**Wiring Diagram:** See Installation Manual (pinout diagrams for PMU24)

///

## Specifications

**Outputs:**

- 24 programmable high-side outputs (10×25A, 6×15A, 8×7A)
- **Total capacity:** 170A continuous (power supply limited, not sum of outputs)
- **Constraint:** Only same-rated outputs can be combined (e.g., 25A + 25A ✓, 25A + 15A ✗)
- **Out 17-24:** Dual-purpose - configurable as 7A outputs OR 0-20V analog inputs

**Key Features:**

- Dedicated 12V switched input (Pin 7), up to 16 analog inputs, 9 digital inputs
- 256MB data logger (500 Hz), real-time clock, IMU, inertia switch
- 2× CAN 2.0 A/B (J1939 compatible), 24× tricolor LED indicators
- PC config via USB ([USB to CAN adapter][usb-to-can] required)

**Physical:** 131×112×33mm, 385g, -40°C to +125°C operating range

**Grounding Note:** PMU is **high-side switching only** - it switches the positive wire to loads. Each load must have its own ground path back to the battery/chassis. The PMU's ground connection (14 AWG) is only for internal electronics reference, not load current return. This is why PMU doesn't require a heavy ground wire matching the 2/0 AWG power feed.

**Configuration Software:** [PMU Setup v101.2.1][pmu-setup] | **Full Specs:** [PMU Manual][pmu-manual]

## Capacity Analysis

| Outputs |  Rating  | Total  |  Used  | Available |
| :--- | :---: | :----: | :----: | :---: |
| 1-10 | 25A each | 10 | 5 | 5 |
| 11-16 | 15A each | 6 | 4 | 2 |
| 17-24 | 7A each  | 8 | 8 | 0 |
| **Total** | - | **24** | **17** |  **7** |

**Utilization:** 17 of 24 outputs used (71%) — 7 freed by relocating the radiator fan, iBooster, and TCU; OUT15 freed when the winch trigger was reallocated to BODY PDU CB43 (2026-05-30); OUT19 and OUT24 taken by the 4x4/4LO indicators (2026-09-18); OUT12 taken by the parking/tail markers when they were split off the DRL circuit (2026-09-22); OUT14 taken by the Garmin GPS when it moved off the SwitchPros (2026-09-24). The 7A bank (OUT17-24) is full — future low-current loads go on the 15A bank.

**Primary loads:** HVAC (OUT5: ~20A load), GMRS radio (OUT6: ~15A load), aux cooling fans (OUT7+8: 2×15A), Dakota Digital (OUT9: ~25A), wipers (OUT11: 15A), parking/tail markers (OUT12: ~2A), CT4 (OUT13: ~9A), A/C clutch (OUT17: 7A), horn (OUT18: 7A), intercom (OUT20: 7A), brake lights (OUT21: 7A), reverse lights (OUT22: 7A), DRL/parking (OUT23: 7A), 4x4 indicator relay (OUT19: <0.2A), 4LO indicator (OUT24: <0.1A), Garmin GPS (OUT14: ~2A). _Radiator fan (was OUT2+3+4), iBooster main + enable (was OUT1+10, OUT19), and Turbolamik TCU (was OUT16) relocated to the [START+ Forward Distribution Bus][start-fwd-bus]; the winch contactor trigger (was OUT15) reallocated to BODY PDU CB43 — OUT1–4, 10, 15, 16 now free (OUT14 went to the GPS)._

**Load:** With the radiator fan, iBooster, and TCU relocated to the START+ Forward Bus, PMU peak drops to ~147A theoretical (all radios transmitting), ~87-117A typical continuous — comfortably within the 170A continuous PMU capacity. **7 outputs were freed by the fan/iBooster/TCU relocation** and OUT15 by the winch-trigger reallocation; after the 4x4/4LO indicators took OUT19 and OUT24 and the GPS took OUT14, **7 of 24 outputs are unassigned**. The two indicator outputs are signal-level (<0.3A combined) and do not move the load figures.

**Mounting:** Engine bay, accessible for LED diagnostics and USB configuration

## Related Documentation

- [PMU Inputs][pmu-inputs] - Input configuration and CAN bus integration
- [PMU Outputs][pmu-outputs] - 24-output configuration and load details
- [PMU Programming][pmu-programming] - Logic examples and configuration
- [START battery Distribution][starter-battery-distribution] - PMU power source (2/0 AWG, 7 ft) and circuit breaker (250A)
- [Wire Distance Reference][wire-distance] - PMU to battery routing distance

[pmu-inputs]: 02-pmu-inputs.md
[pmu-outputs]: 03-pmu-outputs.md
[pmu-programming]: 04-pmu-programming.md
[starter-battery-distribution]: ../02-starter-battery-distribution/index.md
[start-fwd-bus]: ../02-starter-battery-distribution/index.md#start-forward-bus
[wire-distance]: ../01-power-generation/05-wire-distance-reference.md
[ecumaster-pmu24]: https://www.ecumaster.com/products/pmu24/
[pmu-manual]: https://www.ecumaster.com/files/PMU/PMU_Manual.pdf
[pmu-pinout]: https://www.ecumaster.com/files/PMU/PMU-24_Pinout_v1.1.pdf
[usb-to-can]: https://www.ecumaster.com/products/usb-to-can/
[pmu-setup]: https://www.ecumaster.com/files/PMU/PMUSetup_101_2_1.exe

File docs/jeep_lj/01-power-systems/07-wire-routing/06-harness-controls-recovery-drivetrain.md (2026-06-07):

---
hide:
  - toc
tags:
  - wire-routing
  - harness
---

# 1.7.6 Controls, Recovery & Drivetrain {#harness-controls-recovery-drivetrain}

Workbench specs for the recovery and drivetrain harnesses: **H6** ARB Compressor, **H7** Winch Trigger, **H8** Kilduff Shifter → TCU, and **H9** TCU → Engine Bay.

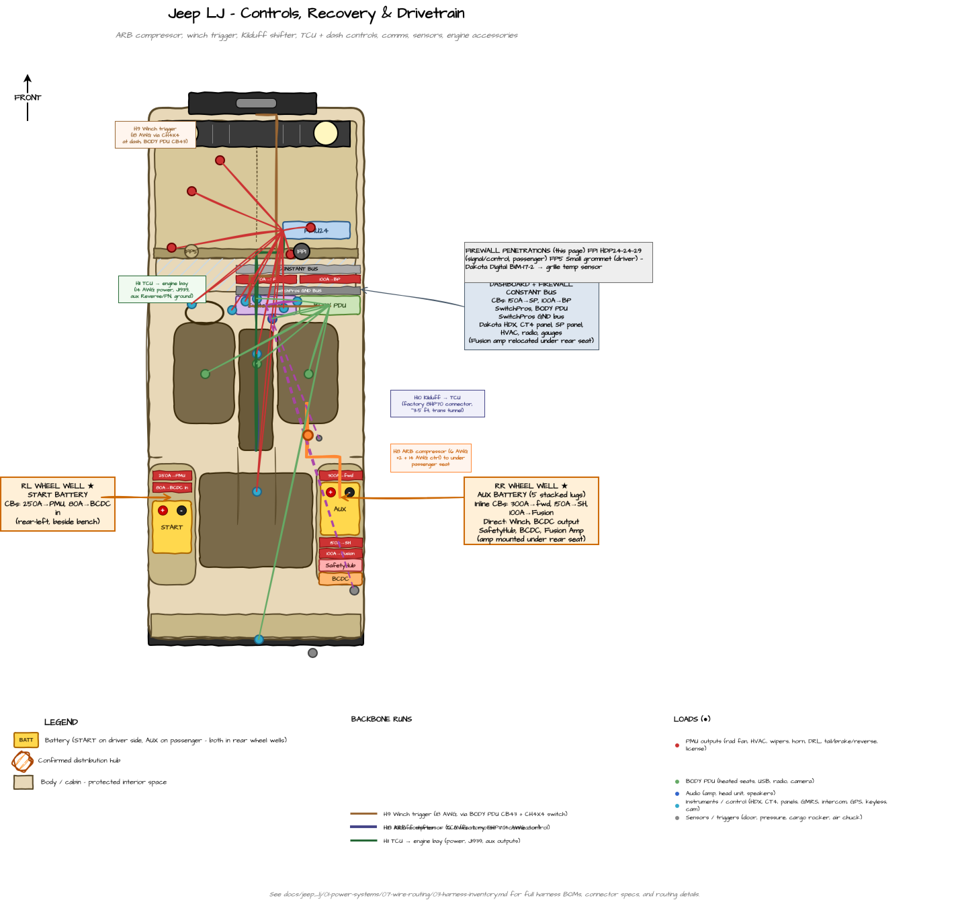
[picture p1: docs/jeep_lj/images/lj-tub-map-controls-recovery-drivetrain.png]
LJ Tub Map — Controls, Recovery & Drivetrain routing (top-down): ARB compressor, winch contactor trigger, shifter, and TCU runs (H6–H9)


*Top-down tub map of the controls/recovery/drivetrain harnesses. Diagram source: `Jeep LJ Tub Map.drawio` (page "Controls, Recovery & Drivetrain"); the image is regenerated from the draw.io file on each export.*

**Reading this sheet:** Power = red, ground = black; CAN runs as a twisted pair; vendor-supplied harnesses (ARB, CH4X4, Kilduff/ZF) keep their shipped colors. See the [Wire Color Convention][color-convention]. The H6 compressor motor pair is a power run and takes a black braided sleeve (blue tracer); the small-wire signal harnesses (H7, H9) use split loom — see [Protective Sleeve & Tracers][sleeve-convention]. Other protection standards by location are in [Wire Protection Standards][wire-routing]; system-wide context is in the [Harness Inventory][harness-inventory] overview.

---

## H6 — ARB Compressor Bundle {#h6}

*Previously numbered H8. Renumbered 2026-05-31.*

**Build:** 4 conductors (2× 6 AWG motor + 2 signal) · ~10 ft · lug at SafetyHub, ring/spade at compressor · motor pair in black braided sleeve (blue tracer) · the two signal wires originate at SwitchPros, not SafetyHub.

**Route:** SafetyHub (passenger rear wheel well) → under cargo / under rear bench → under passenger seat (compressor mount)

**Length:** ~10 ft

**Contains:**

| Wire | Gauge | Color | Function | Termination at SafetyHub | Termination at compressor |
|:-----|:-----:|:-----:|:---|:---|:---|
| Motor 1 power | 6 AWG | Red (per ARB) | SafetyHub MIDI-1 (60A) → compressor motor 1 | Lug to MIDI-1 output | Compressor motor terminal |
| Motor 2 power | 6 AWG | Red (per ARB) | SafetyHub MIDI-2 (60A) → compressor motor 2 | Lug to MIDI-2 output | Compressor motor terminal |
| Control signal | 14 AWG | Per SP pigtail | SwitchPros OUT-11 → compressor control terminal | (Comes from SwitchPros at firewall, not SafetyHub — runs separately or joins this bundle along common path) | Compressor control terminal |
| Pressure switch | 18 AWG | Per SP pigtail | ARB pressure switch (on manifold under passenger seat) → SwitchPros TRIGGER-3 | (At firewall, not SafetyHub) | Pressure switch normally-open contact |

**Connectors:** Lug at SafetyHub side, ring/spade at compressor. ARB compressor manifold typically has a pigtail with its own connector.

**Protection:** Black braided expandable sleeve (blue tracer) over the 2× 6 AWG motor pair along the under-floor / under-seat run. Split loom for the control + pressure signal wires. P-clamps every 12–18".

**Notes:**

- Motor 1 + motor 2 are 6 AWG (high current, brief peaks) — bundle as a pair
- Control + pressure switch wires originate at SwitchPros at firewall, NOT SafetyHub — they run from firewall through cabin to under passenger seat
- Could be merged into H6 if they share routing, or kept separate as "H6b ARB signal"

**Optimization opportunity:** Run the SwitchPros control + pressure switch wires through the cabin trunk to under passenger seat as part of [H5 SwitchPros rear bundle][lighting-build] (they're SP wires anyway), and split off at the compressor. Saves a separate harness — the only ARB-specific harness is the 2x 6 AWG motor cables from SafetyHub.

---

## H7 — Winch Trigger Control (small wire) {#h7}

*Previously numbered H9. Renumbered 2026-05-31.*

**Build:** 5 conductors (all 18 AWG) · ~3 ft (BODY PDU → dash) + ~13 ft (dash → contactor) · CH4X4 switch ships its own pigtail + cable kit · HDP24 at firewall.

**Route:** BODY PDU (firewall, cabin side) → dash switch ([CH4X4 dual-momentary push][ch4x4-winch]) → HDP24 firewall pins 16/17 → winch contactor at front bumper

**Length:** ~3 ft (BODY PDU → dash) + ~13 ft (dash → contactor via engine bay)

**Contains:**

| Wire | Gauge | Color | Function | Termination |
|:-----|:-----:|:-----:|:---|:---|
| Switch +12V supply | 18 AWG | Red | BODY PDU CB43 (10A) → CH4X4 switch common | Spade at BODY PDU, included pigtail at switch |
| IN trigger | 18 AWG | Per CH4X4 pigtail | CH4X4 IN button → HDP24 pin 16 → contactor IN trigger | Included pigtail at switch, HDP24 socket, ring/spade at contactor |
| OUT trigger | 18 AWG | Per CH4X4 pigtail | CH4X4 OUT button → HDP24 pin 17 → contactor OUT trigger | Included pigtail at switch, HDP24 socket, ring/spade at contactor |
| Illumination supply | 18 AWG | Per CH4X4 pigtail | Dash illumination circuit | Included pigtail at switch |
| Switch ground | 18 AWG | Black | Switch common ground | Chassis ground at dash |

**Connectors:** CH4X4 includes its own connector + cable kit. HDP24-24-29 at firewall penetration. Ring/spade terminals at contactor.

**Notes:**

- BODY PDU CB43 (10A, ~3 ft to dash) replaces the previously-planned SafetyHub ATC-1 (15A, ~13 ft from rear wheel well). The 18 AWG wire is properly sized for the ~3A trigger current; the prior 14 AWG / 15A spec was over-built and routed wastefully.
- Switch is dual-momentary push (not a polarity-reversing rocker) — the WARN ZEON 10-S contactor handles polarity internally
- Warn handheld remote wires in parallel at the contactor trigger terminals
- SafetyHub ATC-1 slot freed for future use (recovery accessories etc.)

---

## H8 — Kilduff Shifter to TCU {#h8}

*Previously numbered H10. Renumbered 2026-05-31.*

**Build:** 1 multi-conductor proprietary harness (supplied with the Kilduff shifter kit) · ~3–5 ft · factory 8HP70 connectors · no fabrication required.

**Route:** Kilduff shifter in **center console** → straight down through trans tunnel → Turbolamik TCU **mounted on 8HP70 mechatronic** (transmission valve body)

**Length:** ~3–5 ft

**Contains:**

| Wire | Gauge | Color | Function | Termination at shifter | Termination at TCU |
|:-----|:-----:|:-----:|:---|:---|:---|
| Shifter harness | Proprietary multi-conductor (factory 8HP70 connector) | Factory (Kilduff/ZF) | All shifter signals (P/R/N/D, manual +/−, button states, illumination) | Kilduff-supplied connector at shifter base | Factory 8HP70 connector at TCU |

**Connectors:**

- Kilduff supplies the shifter end of the harness with their shifter kit
- TCU end uses the factory 8HP70 mechatronic connector (Turbolamik TCU 2.0 mates to this)

**Protection:** Split loom through trans tunnel. The trans tunnel keeps the cable away from cabin contents and provides a clean straight run.

**Notes:**

- TCU is **mounted on the 8HP70 mechatronic** (the trans valve body), not in cabin or engine bay — so this is a very short pull
- No firewall penetration
- No other H-series harnesses share this path — it's a single-purpose, self-contained run
- Kilduff includes the wiring harness with the shifter kit — no separate fabrication required

See [Transmission][transmission] for shifter and TCU specs.

---

## H9 — TCU to Engine Bay {#h9}

*Previously numbered H11. Renumbered 2026-05-31.*

**Build:** 6 conductors (incl. one twisted CAN pair) · 3–4 ft · TCU connector at one end, individual terminations in engine bay · split loom + heat sleeve at engine-bay entry.

**Route:** Turbolamik TCU on 8HP70 mechatronic → up through trans tunnel forward → engine bay (PMU + J1939 tap + starter P/N relay)

**Length:** 3–4 ft

**Contains:**

| Wire | Gauge | Color | Function | Source | Destination |
|:-----|:-----:|:-----:|:---|:---|:---|
| TCU power feed | 12 AWG | Red | START+ Forward Dist Bus (25A CB, CONSTANT, 15A) → TCU power input | START+ Forward Dist Bus (engine bay) | TCU power terminal |
| J1939 CAN High | Twisted pair | Twisted pair (CAN) | Shared J1939 bus tap (same tap as PMU, Dakota Digital BIM-01-2) | CAN bus tap point | TCU CAN-H |
| J1939 CAN Low | Twisted pair (paired with CAN High) | Twisted pair (CAN) | Shared J1939 bus tap | CAN bus tap point | TCU CAN-L |
| Aux out (Reverse) | 18 AWG | Builder's choice | TCU aux output: 12V when shifter in R → PMU In 3 (drives PMU OUT22 reverse lights) | TCU aux Reverse pin | PMU In 3 |
| Aux out (P/N) | 18 AWG | Builder's choice | TCU aux output: 12V when shifter in P or N → starter P/N interlock relay coil | TCU aux P/N pin | Starter P/N interlock relay coil+ |
| Brake input | 18 AWG | Builder's choice | Dedicated brake-pedal signal for unlock-from-Park (separate from PMU In 2 tap) — crosses firewall via HDP24 | Cabin brake pedal switch | TCU brake input pin |
| TCU ground | 14 AWG | Black | TCU ground return | TCU ground terminal | Engine bay ground bus |

**Connectors:**

- TCU end: Turbolamik TCU's connector (depends on TCU model — 2.0 typically uses a small Deutsch DT or similar)
- Engine bay ends: Each wire terminates at its destination (PMU spade/screw terminal, J1939 splice, relay coil terminal, ground bus stud)

**Protection:** Split loom from TCU through trans tunnel up to engine bay. Heat sleeve where it enters engine bay zone (>12" from exhaust).

**Notes:**

- Engine-bay endpoints need no firewall penetration; the one exception is the brake-switch input below, which originates at the cabin brake pedal switch
- J1939 CAN tap is shared with PMU and Dakota Digital BIM-01-2 — the TCU is a third node on the same bus (just adds a splice at the existing tap point)
- **Brake switch input to TCU (for unlock-from-Park): dedicated wire** (decided 2026-06-03). A separate 18 AWG conductor runs from the cabin brake pedal switch through the firewall (HDP24, dedicated pin) to the TCU brake input — **not** a shared tap off the PMU In 2 feed. A dedicated wire keeps the TCU and PMU brake-sense paths electrically independent (a fault or load on one cannot disturb the other) at the cost of one added HDP24 contact
- TCU is one of three controllers tightly coupled to the engine bay: PMU24 (mounted on firewall), Dakota Digital BIM modules (on HDPE panel cabin side), and TCU (mounted on transmission). All share the J1939 CAN bus.

See [Transmission][transmission] and [PMU Outputs][pmu-outputs] for related details.

---

## Related Documentation

- [Harness Inventory][harness-inventory] - Overview, harness map, and bundle interference assessment
- [Power Distribution Build Sheet][power-build] - H1, H2, H3
- [Lighting & SwitchPros Build Sheet][lighting-build] - H4, H5
- [Wire Routing][wire-routing] - Zone-based routing and protection standards
- [Firewall Ingress][firewall-ingress] - HDP24 pinout (H7 trigger pins 16/17)
- [SafetyHub 150][safetyhub] - H6 source
- [SwitchPros SP-1200][switchpros] - H6 control source
- [Transmission][transmission] - H8 shifter and H9 TCU specs
- [PMU24 Outputs][pmu-outputs] - H9 source
- [Air Compressor][air-compressor] - H6 destination

[harness-inventory]: 03-harness-inventory.md
[color-convention]: 03-harness-inventory.md#wire-color-convention
[sleeve-convention]: 03-harness-inventory.md#sleeve-convention
[power-build]: 04-harness-power-distribution.md
[lighting-build]: 05-harness-lighting-switchpros.md
[wire-routing]: index.md
[firewall-ingress]: 02-firewall-ingress.md
[safetyhub]: ../03-aux-battery-distribution/04-safetyhub.md
[switchpros]: ../../05-control-interfaces/02-switchpros-sp1200.md
[transmission]: ../../10-drivetrain/01-transmission.md
[pmu-outputs]: ../04-pmu/03-pmu-outputs.md
[air-compressor]: ../../08-exterior-systems/02-air-compressor.md
[ch4x4-winch]: https://ch4x4.com/product/ch4x4-momentary-dual-push-switch-for-toyota-winch-in-out-symbol/

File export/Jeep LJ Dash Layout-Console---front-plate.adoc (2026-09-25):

= Jeep LJ Dash Layout Console - front plate

image::Jeep LJ Dash Layout-Console---front-plate.png[Console - front plate]

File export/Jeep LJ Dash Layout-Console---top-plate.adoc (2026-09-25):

= Jeep LJ Dash Layout Console - top plate

image::Jeep LJ Dash Layout-Console---top-plate.png[Console - top plate]

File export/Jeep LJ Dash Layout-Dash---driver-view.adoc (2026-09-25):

= Jeep LJ Dash Layout Dash - driver view

image::Jeep LJ Dash Layout-Dash---driver-view.png[Dash - driver view]

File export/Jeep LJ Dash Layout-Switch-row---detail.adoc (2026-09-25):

= Jeep LJ Dash Layout Switch row - detail

image::Jeep LJ Dash Layout-Switch-row---detail.png[Switch row - detail]

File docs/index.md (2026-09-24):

---
hide:
  - navigation
  - toc
---

<section class="sm-hero">
  <div class="sm-hero__inner">
    <p class="sm-hero__eyebrow">Project vehicle build manuals</p>
    <h1 class="sm-hero__title">Every wire and every part, written down.</h1>
    <p class="sm-hero__lede">shopmanual.io is a living build manual for my project vehicles — wiring diagrams, part numbers, and the reasoning behind every decision, kept in one searchable place.</p>
    <p class="sm-hero__actions">
      <a class="sm-btn sm-btn--primary" href="jeep_lj/">Explore the Jeep LJ build</a>
      <a class="sm-btn sm-btn--ghost" href="#projects">See all projects</a>
    </p>
  </div>
</section>

<section class="sm-mission">
  <p class="sm-mission__text">Build knowledge has a way of vanishing — buried in forum threads, scribbled on receipts, or living only in your head until the moment you need it. This site is the fix: document it properly, once, and keep it current.</p>
</section>

<section class="sm-section" id="projects">
  <h2 class="sm-section__title">In the garage</h2>
  <p class="sm-section__sub">Pick a build to dive in.</p>
  <div class="sm-cards sm-cards--projects">
    <a class="sm-card" href="jeep_lj/">
      <span class="sm-card__icon">🚙</span>
      <span class="sm-card__title">Jeep Wrangler LJ</span>
      <span class="sm-card__desc">A 2006 LJ with a Cummins R2.8 turbo-diesel swap and a ground-up electrical rebuild: dual isolated batteries, programmable power management, keyless start, and a full lighting, audio, and recovery package.</span>
      <span class="sm-card__cta">Explore the build →</span>
    </a>
    <a class="sm-card sm-card--soon" href="nissan_nv/">
      <span class="sm-card__icon">🚐</span>
      <span class="sm-card__title">Nissan NV 3500 <span class="sm-card__badge">Coming soon</span></span>
      <span class="sm-card__desc">A van platform build. Just getting started — check back as the documentation comes together.</span>
      <span class="sm-card__cta">Project home →</span>
    </a>
    <a class="sm-card sm-card--soon" href="jeep_jku/">
      <span class="sm-card__icon">🚙</span>
      <span class="sm-card__title">Jeep Wrangler JKU <span class="sm-card__badge">Coming soon</span></span>
      <span class="sm-card__desc">A JK Unlimited. Documentation is starting with the power system: a Genesis Offroad dual battery kit and a SwitchPros SP-9100 switch panel.</span>
      <span class="sm-card__cta">Project home →</span>
    </a>
  </div>
</section>

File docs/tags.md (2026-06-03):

# Product Tags

This page lists all products documented in this technical documentation.

<!-- material/tags -->

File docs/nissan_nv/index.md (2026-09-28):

---
hide:
  - toc
---

# Nissan NV 3500 - Van Build {#nissan-nv-3500-van-build}

## Project Overview

A 2018 Nissan NV 3500 (5.6 L V8, lifted, on 285/65R18 Mickey Thompson Baja
Boss tires) with an accessory electrical system built on top of the factory
wiring. The van runs a **12 V** system: an Odyssey AGM Group 34 START battery
and a second Odyssey AGM Group 34 as the AUX house battery, in a Genesis
Offroad dual battery tray with a Redarc BCDC Alpha 50 DC-DC charger between
them. The AUX battery feeds two switch panels, Rear Powerswitch (A) and (B),
through a 200 A SGP32 relay, and can run with the key off. An Engine Bay
Powerswitch for the KC exterior lighting is planned. A Viper alarm with
SmartStart remote start is tapped into the factory wiring through T-harnesses
behind the driver-side dash.

Documentation for this build started as draw.io drawings rather than written
pages. The *As Built* page of `Van Electrical.drawio` and the pages below are
now the reference for what is in the van; the older drawings are kept on the
[Diagrams](02-diagrams/index.md) page as design history.

<div class="mobile-nav-only" markdown="1">

## Sections

- **[Power Systems](01-power-systems/index.md)** - Batteries, distribution, and the switch panels
- **[Starlink Power](01-power-systems/01-starlink-power.md)** - Starlink Advanced Power Supply, 12 V DC direct
- **[Batteries & Charging](01-power-systems/02-batteries-charging.md)** - Genesis dual battery tray, BCDC Alpha 50, SGP32 rear feed
- **[Switch Panels](01-power-systems/03-switch-panels.md)** - Circuit assignments for Rear Powerswitch (A) and (B)
- **[Diagrams](02-diagrams/index.md)** - The full set of van drawings, rendered from `Van Electrical.drawio`
- **[Vehicle](03-vehicle/index.md)** - Base vehicle, tires, factory-side aftermarket equipment, and service parts

</div>

---

## Current Focus

| Area | State |
| :--- | :---- |
| **Starlink power** | Resolved - High Performance dish on a [Starlink Advanced Power Supply](01-power-systems/01-starlink-power.md), 12 V DC direct, replacing the 1000 W inverter ([#4][issue-4]) |
| **House battery** | Two Odyssey AGM Group 34 (START + AUX) in a Genesis Offroad dual tray, BCDC Alpha 50; [600 A AUX isolator planned](01-power-systems/02-batteries-charging.md#planned) |
| **Entertainment** | 3x Alpine PKG-RES3HDMI headrest screens on Rear Powerswitch (A) 1-3; power for the 3x Nvidia Shields is TBD now the inverter is out |
| **Network** | UniFi UXG Lite gateway in the rear driver's door below the Starlink supply, powered from a 12 V USB-C outlet on Rear Powerswitch (A) circuit 6; WAN from the supply's LAN port |
| **Lighting** | KC light bar, bumper, rock, reverse, and fog lights on a [planned Engine Bay Powerswitch](01-power-systems/03-switch-panels.md#engine-bay) |
| **GMRS radio** | [Midland MXT575][mxt575], 50 W, moving over from the Jeep LJ (owner, 2026-09-25). Where it mounts and what powers it are not decided; Rear Powerswitch (B) has five spare circuits |

[issue-4]: https://github.com/sob/shopmanual.io/issues/4
[mxt575]: https://midlandusa.com/products/mxt575-micromobile-gmrs-two-way-radio

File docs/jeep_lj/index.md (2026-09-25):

---
hide:
  - toc
---

# Jeep LJ Cummins R2.8 Build - Electrical Documentation {#jeep-lj-cummins-r28-build-electrical-documentation}

## Project Overview

This documentation covers the complete electrical system design for a 2006 Jeep LJ (Wrangler Unlimited) with a Cummins R2.8 Turbo Diesel engine swap. The factory wiring and TIPM are replaced with a modular architecture: dual isolated batteries, programmable power management (PMU24), a safety controller (SafetyHub), and split control surfaces for street lighting (Command Touch CT4) and offroad lighting (SwitchPros SP-1200). Brakes are converted to electro-hydraulic (Bosch iBooster + Wilwood master cylinder), and ignition is keyless via PBS-I.

<div class="mobile-nav-only" markdown="1">

## System Architecture

The electrical system is organized into zones for logical distribution and maintenance:

### Power Systems

- **[Power Generation][power-generation]** - Batteries, alternator, BCDC, solar, grounding
- **[START battery Distribution][start-battery]** - Driver rear wheel well primary power distribution
- **[AUX battery Distribution][aux-battery]** - Passenger rear wheel well accessory power distribution
- **[Power Management Unit][pmu]** - PMU24 programmable power management
- **[BODY PDU][body-pdu]** - Body relay/fuse panel
- **[SafetyHub][safetyhub]** - Safety control system

### Critical Systems

- **[Starter System][starter]** - Engine starting system
- **[Brake Booster][brake-booster]** - Bosch iBooster Gen 2 + Wilwood master cylinder
- **[HVAC System][hvac]** - Heating, ventilation, and air conditioning
- **[Wiper System][wipers]** - Windshield wipers
- **[Horn System][horn]** - Vehicle horn
- **[Radiator Fan][radiator-fan]** - Engine cooling fan
- **[Grid Heater][grid-heater]** - Diesel grid heater
- **[Fuel System][fuel-system]** - Fuel pump and delivery
- **[Gauge Cluster][gauge-cluster]** - Dakota Digital HDX cluster + BIMs
- **[Runaway Protection][runaway-protection]** - Diesel runaway shutoff

### Lighting Systems

- **[Lighting Overview][lighting-overview]** - Complete lighting system overview
- **[Headlights][headlights]** - Main headlights
- **[Turn Signals][turn-signals]** - Turn signal system
- **[Tail, Brake & Reverse][tail-brake-reverse]** - Rear lighting
- **[DRL & Parking Lights][drl-parking]** - Daytime running and parking lights
- **[Offroad & Aux Lighting][offroad-lighting]** - Auxiliary and offroad lighting

### Control Interfaces

- **[Overview][control-overview]** - Control systems overview
- **[SwitchPros SP-1200][switchpros]** - SwitchPros lighting controller
- **[Command Touch CT4][ct4]** - Command Touch control panel
- **[Dashboard Switches][dashboard-controls]** - Physical dashboard controls
- **[Keyless Ignition][keyless-ignition]** - PBS-I keyless start

### Stereo Systems

- **[Audio Systems][audio]** - Fusion head unit, JL Audio MV800/8i 8-channel amp, JL Audio speakers and subwoofers

### Communications

- **[Communication Systems][communications]** - GMRS radio, intercom, dash camera

### Auxiliary Systems

- **[Winch][winch]** - Warn Zeon 10-S winch (10,000 lb)
- **[Air Compressor][air-compressor]** - ARB Twin Compressor and tank
- **[Air Lockers][air-lockers]** - ARB RD166 front / RD140 rear lockers
- **[Rear Air Chuck][rear-air-chuck]** - External air access

### Drivetrain

- **[Drivetrain Overview][drivetrain]** - Transmission, transfer case, axles, suspension, steering

### Installation

- **[Installation Overview][installation]** - Build sequence, checklists, purchase tracker
- **[Wire Routing & Layout][wire-routing]** - Physical wire routing, grommets, grounds

</div>

## Key Features

### Dual Battery System

- **START battery:** Driver rear wheel well - powers critical engine systems via PMU and SafetyHub
- **AUX battery:** Passenger rear wheel well - powers accessories via inline CBs + Firewall CONSTANT bus (cabin distribution cluster)
- **Battery Isolation:** RedArc BCDC Alpha 50 DC-DC charger with automatic jump-start assist

See [Power Generation][power-generation] for complete battery and charging system details.

### Modular Power Distribution

The factory TIPM is replaced with discrete, serviceable modules:

- **[PMU24][pmu]:** Programmable 24-channel power management unit
- **[BODY PDU][body-pdu]:** Body relay/fuse panel for cabin accessories
- **[SafetyHub][safetyhub]:** 12-channel advanced safety controller
- **[Ron Francis WS-51C][wipers]:** Wiper control module

### Brake & Ignition

- **[Bosch iBooster Gen 2 + Wilwood MC][brake-booster]:** Electro-hydraulic brake booster (Honda Accord Hybrid Gen 2 iBooster, Wilwood Tandem Compact master cylinder, Back Bay Customs adapter)
- **[PBS-I Keyless Ignition][keyless-ignition]:** Pushbutton start, self-contained RFID immobilizer (no PMU dependency)

### Major Systems

- **[Lighting Control][switchpros]:** SwitchPros SP-1200 for offroad and auxiliary lighting
- **[Command Touch CT4][ct4]:** Street-legal lighting and turn signal control
- **[Audio System][audio]:** JL Audio MV800/8i 8-channel amp w/ DSP, JL Audio marine speakers and 2× 8" subs with RGB LED
- **[Communication][communications]:** Rugged Radio G1 GMRS (overhead on the roll cage), STX Remote Head intercom (knob on the dash), WolfBox dash camera
- **[Recovery & Air][recovery-air]:** Warn 10,000 lb winch, ARB air lockers, ARB Twin Air Compressor

**[TBD Tracker][tbd-tracker]** — Open items and unresolved specs.
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

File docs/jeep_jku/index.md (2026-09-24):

---
hide:
  - toc
---

# Jeep Wrangler JKU {#jeep-wrangler-jku}

## Project Overview

A 2012 Jeep Wrangler JK Unlimited (not a Rubicon) with the 3.6L. Its front and rear axles came from a donor Rubicon, bringing Rubicon electric lockers with them, which run from the SP-9100 because there is no factory locker switch. Documentation starts with
the power system:

- A **Genesis Offroad dual battery system**, an older-generation kit with Genesis's own smart isolator, holding two Odyssey AGM Group 34 batteries. There is no DC-DC charger.
- A **SwitchPros SP-9100** 8-switch panel for the accessories, wired directly to the AUX battery.

<div class="mobile-nav-only" markdown="1">
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

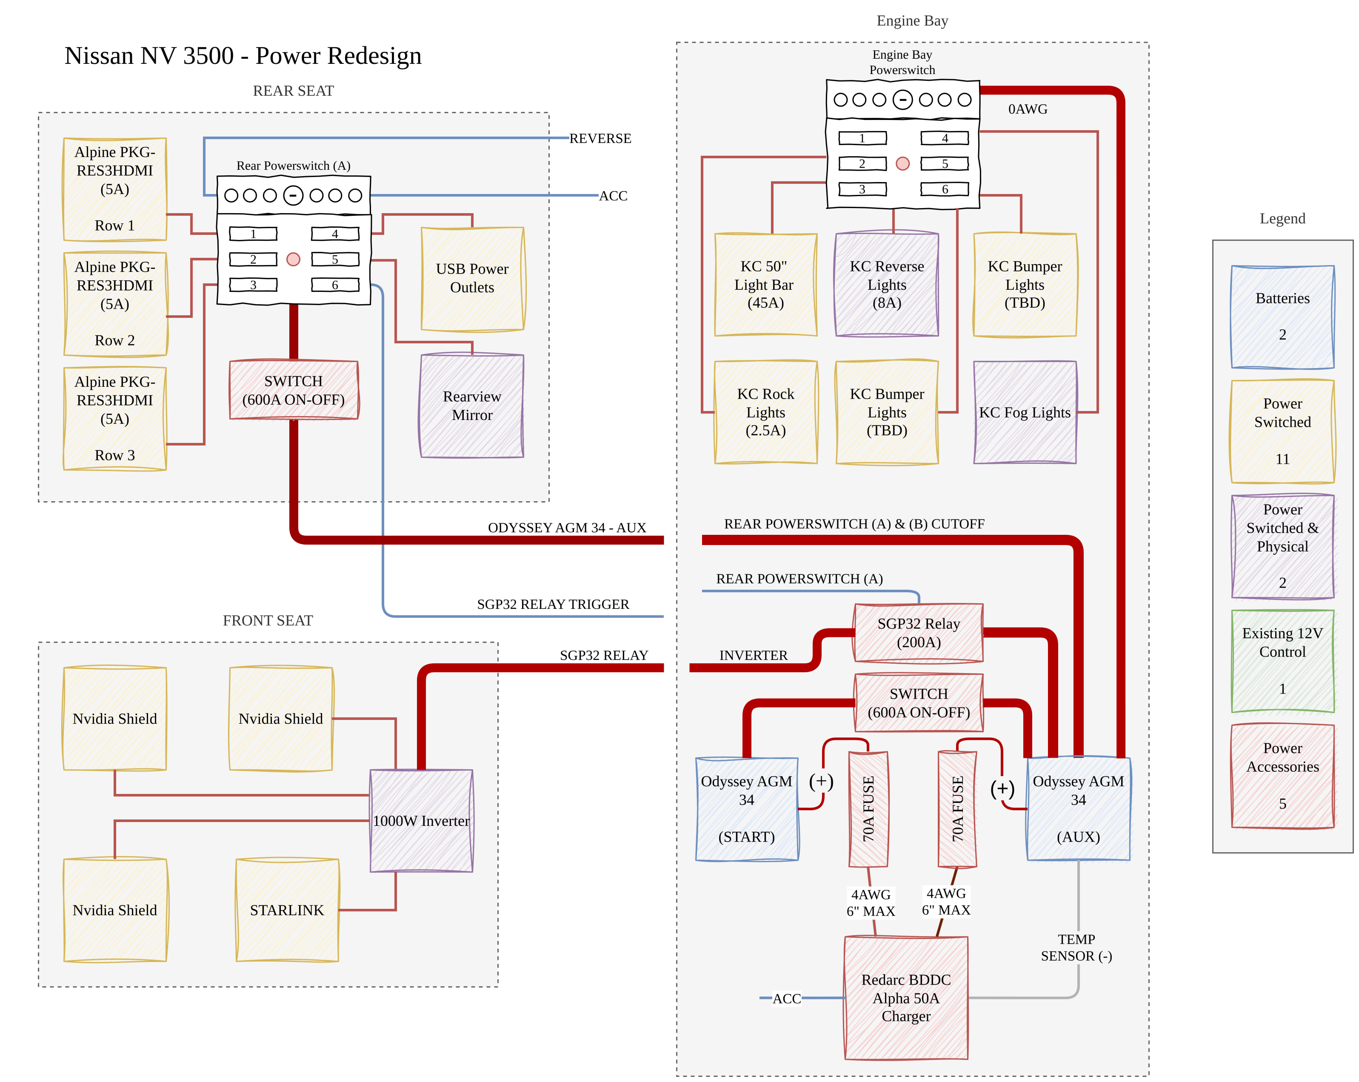
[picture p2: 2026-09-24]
docs/nissan_nv/images/van-current-state.png

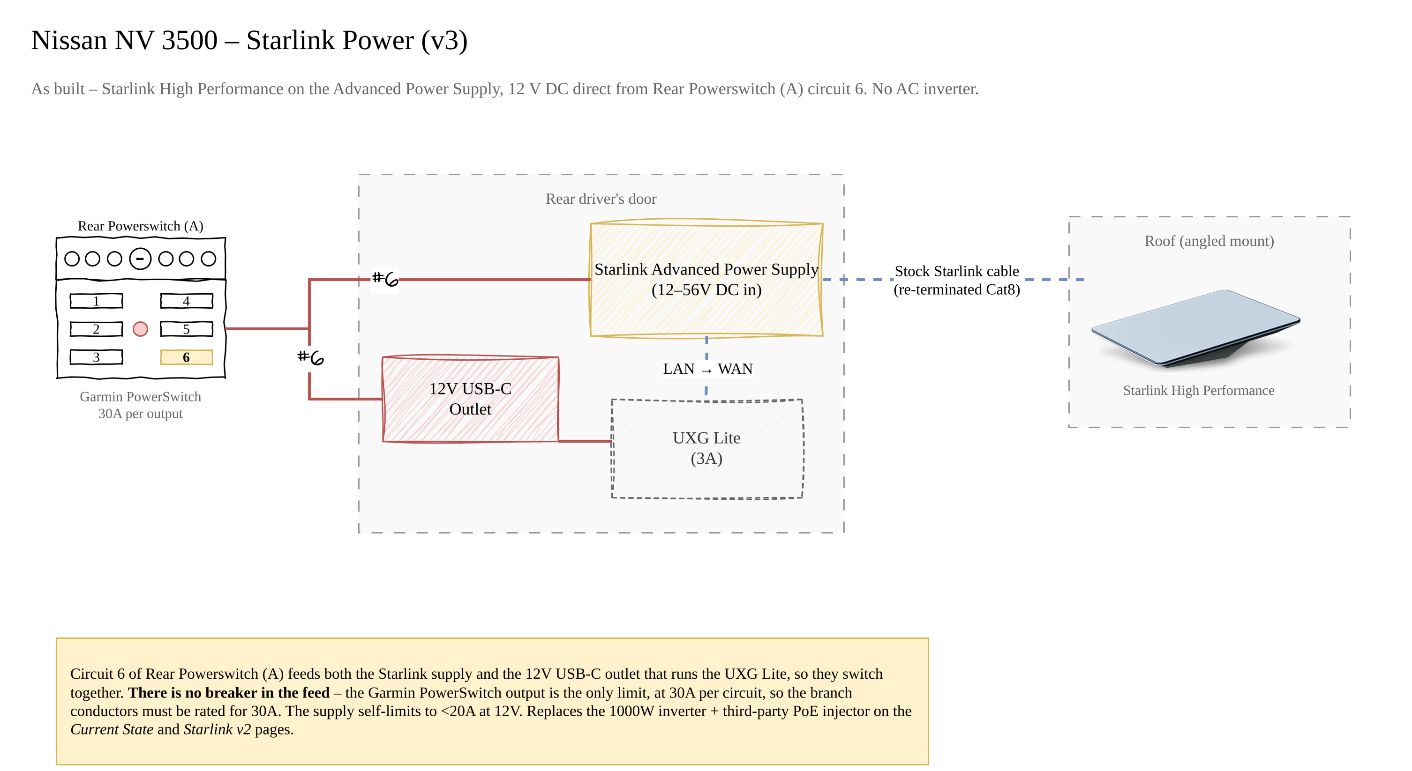
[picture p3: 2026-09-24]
docs/nissan_nv/images/van-starlink-power.png

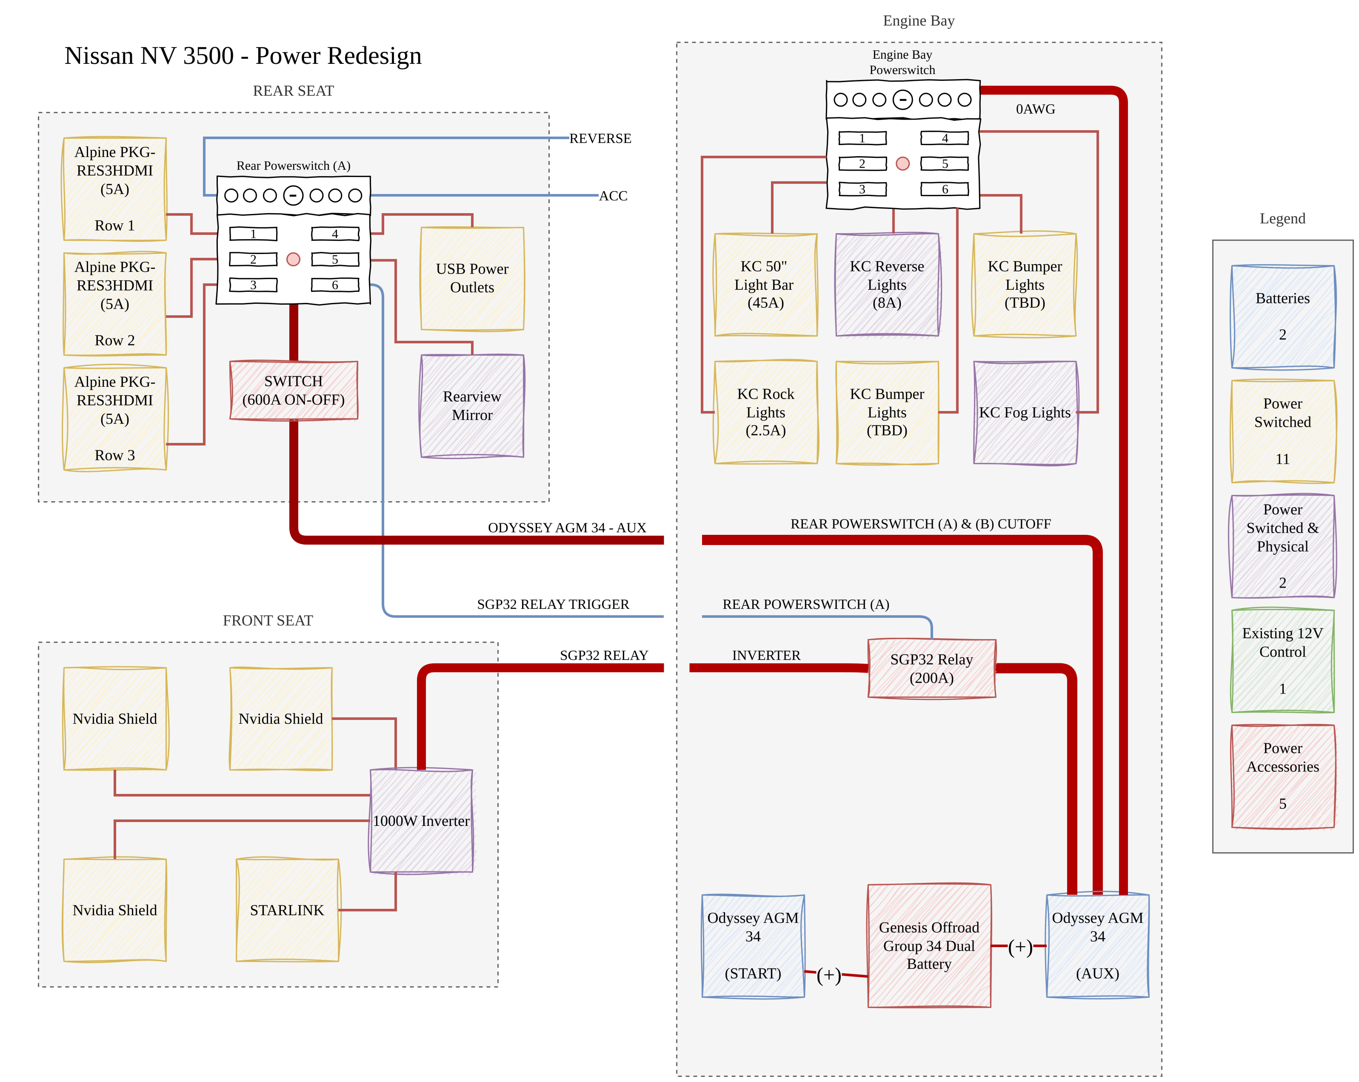
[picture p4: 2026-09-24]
docs/nissan_nv/images/van-genesis.png

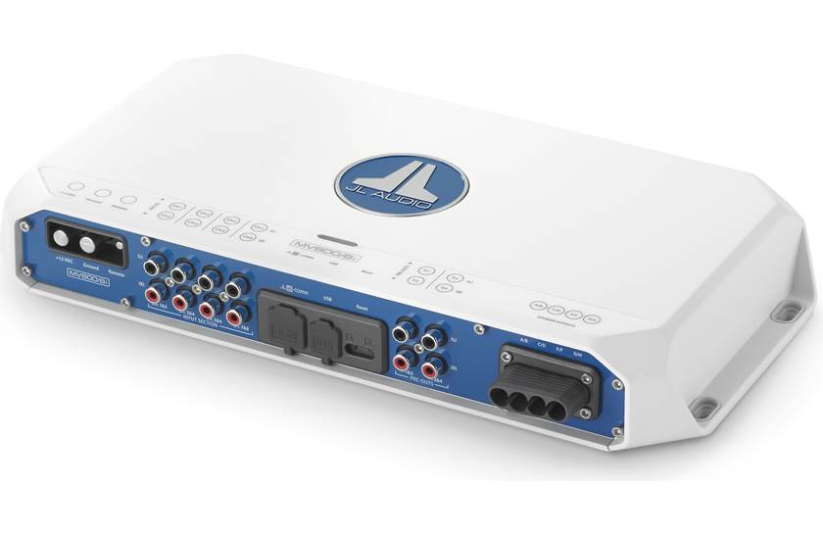
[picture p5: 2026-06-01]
docs/jeep_lj/images/jl-audio-mv800-8i.jpg

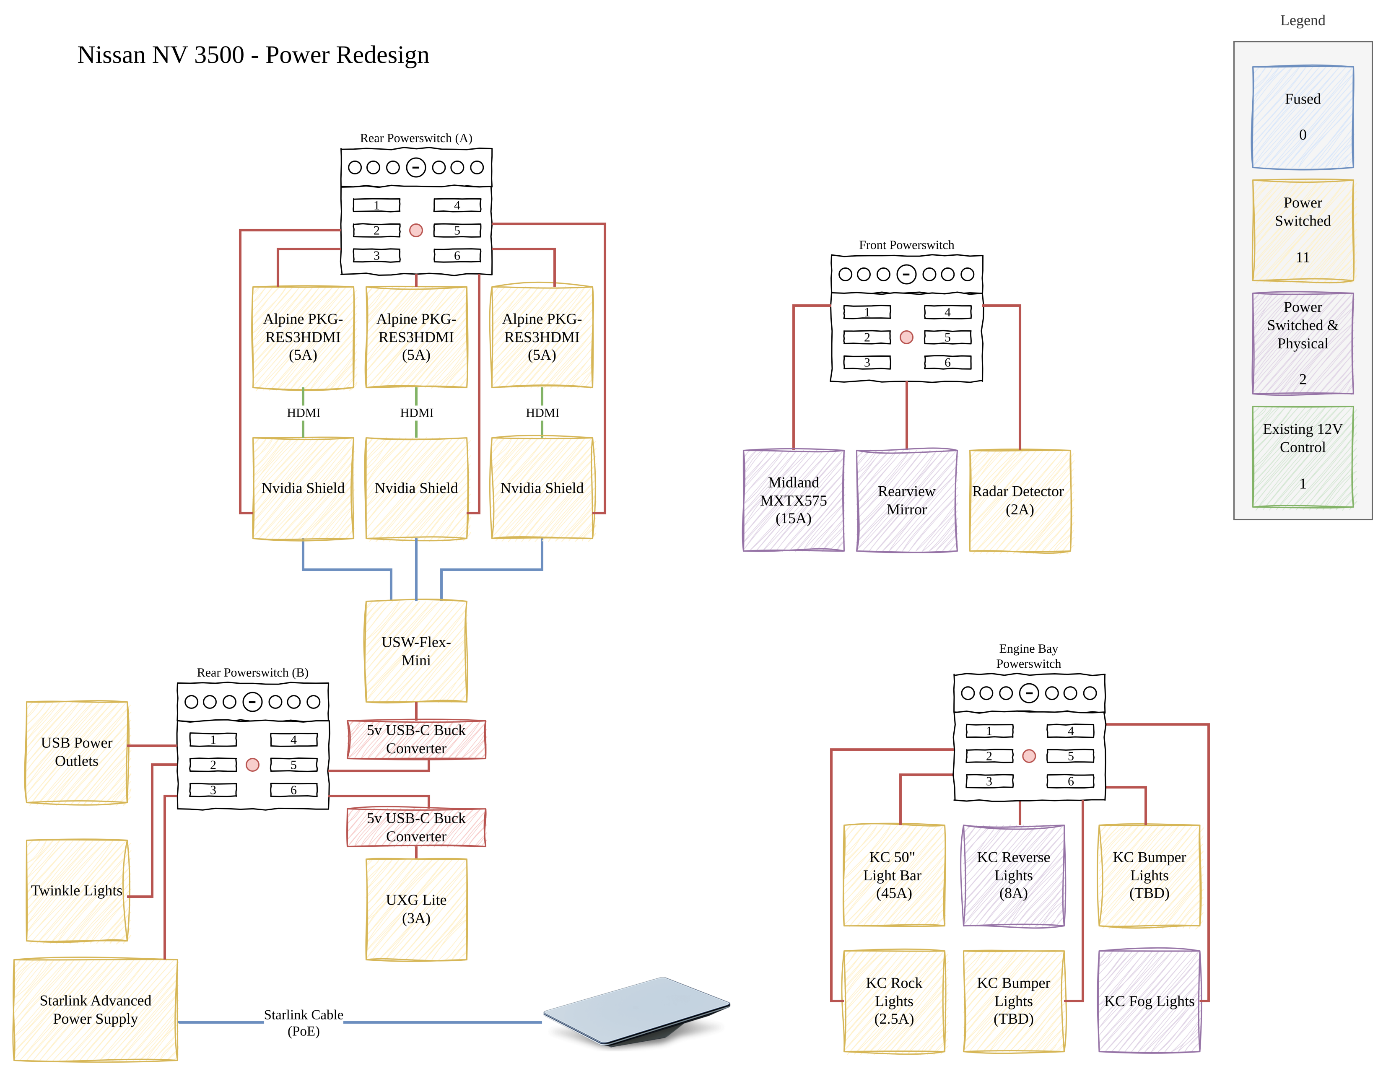
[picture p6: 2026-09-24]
docs/nissan_nv/images/van-devices.png

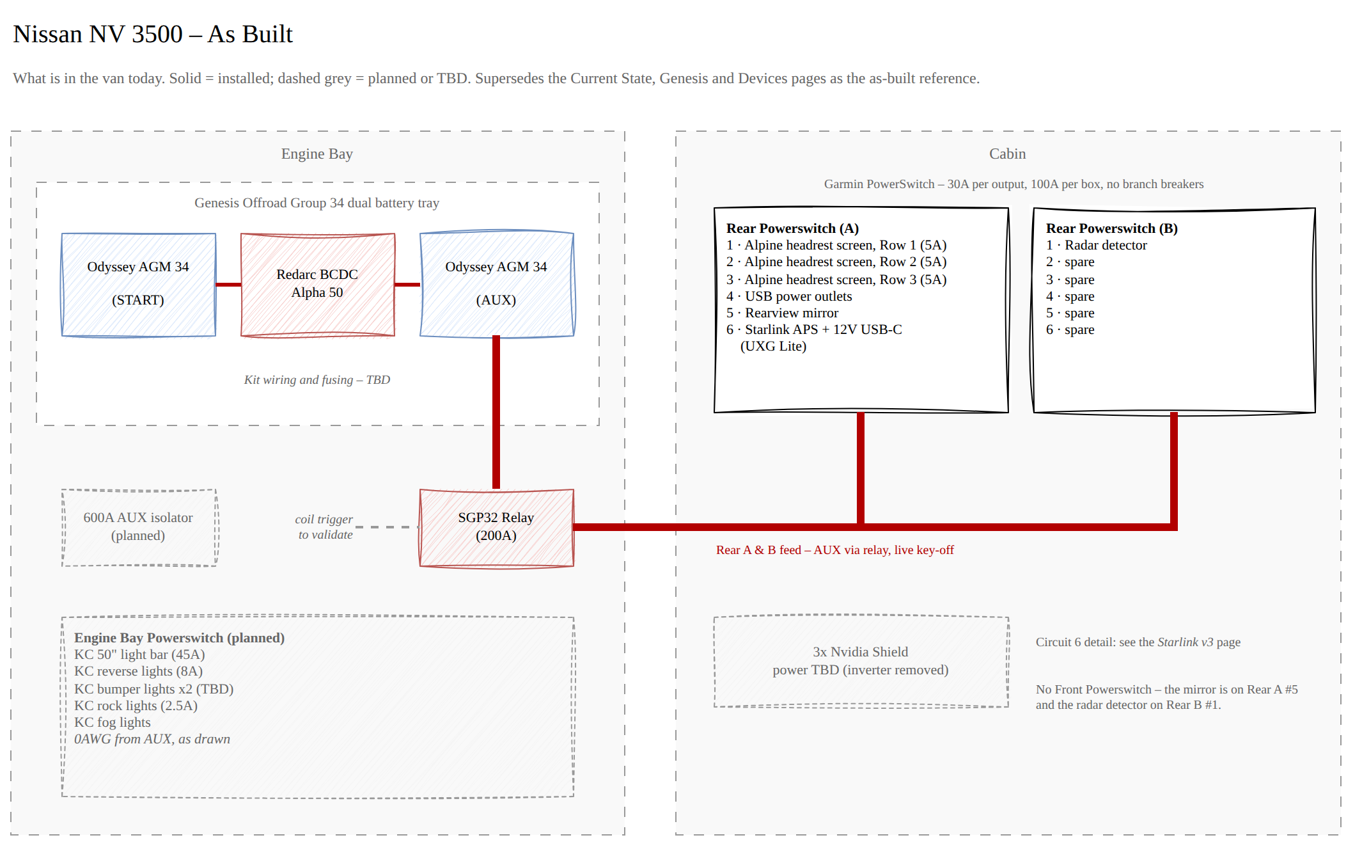
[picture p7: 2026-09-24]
docs/nissan_nv/images/van-as-built.png

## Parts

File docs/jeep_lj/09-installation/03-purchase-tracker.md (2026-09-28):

# 9.3 Purchase Tracker {#purchase-tracker}

Components organized by estimated cost for purchase planning (Black Friday, sales, etc.).

**Last Updated:** 2026-09-27

---

## Purchase Summary

| Status | Count | Est. Total |
|:---|---:|---:|
| Purchased | 30+ | ~$12,700+ |
| To Purchase | 40+ | ~$8,100–8,600 |

---

## Purchased Items

| Item | Manufacturer | Est. Price | Notes |
|:-----|:---|:---|:---|
| Dakota Lithium DL+ 135Ah Battery | Dakota Lithium | ~$999 | AUX battery |
| Odyssey PC1500 Battery | Odyssey | ~$350 | START battery |
| SwitchPros SP-1200 RCR-Force 12 | SwitchPros | ~$800 | |
| RedArc BCDC Alpha 50 | RedArc Electronics | ~$600 | |
| Warn Zeon 10-S Winch | Warn | ~$1,200 | |
| Fusion MS-RA670 Head Unit | Fusion (Garmin) | ~$400 | |
| Rugged Radios G1-GMRS (40W) | Rugged Radios | ~$350 | |
| Cascadia 4x4 80W Solar Panel | Cascadia 4x4 | ~$350 | |
| GM 84100128 Radiator Fan | General Motors | ~$200 | |
| Dakota Digital HDX-96J-TJ Gauge Cluster | Dakota Digital | ~$900 | |
| Dakota Digital HDX Control Module | Dakota Digital | ~$200 | |
| Dakota Digital BIM-01-2-J1939 | Dakota Digital | ~$100 | Engine data |
| Dakota Digital GPS-50-2 | Dakota Digital | ~$100 | GPS/Speed |
| Dakota Digital BIM-22-3 | Dakota Digital | ~$150 | TPMS |
| Dakota Digital BIM-17-2 | Dakota Digital | ~$100 | Compass/Temp |
| KC HiLiTES Cyclone V2 (Rock Lights) | KC HiLiTES | ~$360 | 6 units |
| Maxbilt Round Trail Tail Light | Maxbilt | ~$200 | |
| JL Audio M6-650VEX-Mb-S-GmTi-i (Rear) | JL Audio | ~$600 | Pair |
| Blue Sea / Electrical Distribution | Blue Sea Systems | ~$500 | Bus bars, CBs, etc. |
| Garmin Tread 2 - Overland Edition | Garmin | ~$899 | Amex points; [Navigation][navigation] |
| ECUMaster PMU24 DL | ECUMaster | ~$1,200 | [PMU Overview][pmu] |
| ARB CKBLTA12 Brushless Twin Compressor | ARB | ~$900 | [Air Compressor][air-compressor] |
| ARB Pressure Switch (180901) | ARB | ~$50 | [Air Compressor][air-compressor] |
| 4-6 Port Air Manifold | Generic | ~$30 | [Air Compressor][air-compressor] |
| Restomod Air Custom HVAC Kit | Restomod Air | — (confirm) | Ordered 2026-06; replaces factory TJ HVAC — model/config {{ tbd(146) }} - [HVAC][hvac] |
| Ford Super Duty Dana 60 front housing (2005-2010 F-350 SRW) | Ford | — | [Front Axle][front-axle] |
| Ford Sterling 10.5 rear housing (2005-2010 F-350 SRW) | Ford | — | [Rear Axle][rear-axle] |
| ARB RD166 Air Locker (Front) | ARB | — | 35 spline, 4.56 & up - [Front Axle][front-axle] |
| American Iron ball joint delete kit | American Iron | — | [Front Axle][front-axle] |
| Offroad Anonymous 05-16 SD60 full hydro high steer arms | Offroad Anonymous | — | Quantity per arm vs per pair {{ tbd(302) }} - [Front Axle][front-axle] |
| Raceline RT233 Monster beadlocks | Raceline | — | 17x9.5, 8x170, -32 offset |
| PSC 8" double-ended ram | PSC | — | Carried over from the Dana 44 build - [Steering][steering] |
| Barnes 4WD universal DIY ram mount | Barnes 4WD | — | Carried over - [Front Axle][front-axle] |
| Command Touch CT4 Turn Signal & Accessory Kit (GPS) | SwitchPros | ~$500 | Purchased 2026-09; kit includes horn, front/rear turn LEDs, lit plate frame, harnesses, mounts. Plus Axia Alloys 1.125" column clamp - [CT4][ct4] |
| Cummins R2.8 factory starter | Cummins | — | Shipped mounted on the crate engine; keeping it (2026-09-22) - [Starter][starter] |
| Bosch iBooster Gen 2 (with MC pull) | Bosch / Honda | $195 | Purchased 2026-05-30; Honda Accord Hybrid donor (listing #397546491129); OEM 46680-T3Z-A00 + 01469-TWA-A58 confirmed - [iBooster][ibooster] |

---

## High Value ($500+)

Major components - watch for sales, consider financing options.

| Item | Manufacturer | Est. Price | Priority | Notes |
| :--- | :--- | :--- | :--- | :--- |
| Premier Power Welder HO-C28 Alternator (270A) | Premier Power Welder | $899.95 | High | [Product Page][alternator] |
| Rugged Radios STX Remote Head intercom (STX-RS) | Rugged Radios | ~$744 ($875 list, 2026-09-25) | Medium | Knob on the dash; replaces the ~$400 standard STX - [Intercom][intercom] |

---

## Medium Value ($200-$499)

| Item | Manufacturer | Est. Price | Priority | Notes |
|:-----|:---|:---|:---|:---|
| 03-06 TJ/LJ Auto Brake Pedal Assembly | Mopar | ~$30-80 | **Ordered** | Auto-trans pedal w/ wider pad + stop-lamp switch - [iBooster][ibooster] |
| Back Bay Customs Wilwood MC Adapter | Back Bay Customs | ~$165 | High | Replaces factory MC w/ Wilwood - [iBooster][ibooster] |
| Wilwood Tandem Compact MC (1-1/8" bore; 260-15541, confirm) | Wilwood | ~$180-230 | High | Re-sized 2026-09-16 for Super Duty calipers - [Brakes][brakes] |
| Wilwood 260-16392 Remote Reservoir (×2) | Wilwood | ~$260-320 | High | 4oz anodized, -3 AN port - [iBooster][ibooster] |
| Wilwood 250-16393 Dual Reservoir Bracket | Wilwood | ~$45-65 | High | Anodized billet - [iBooster][ibooster] |
| Wilwood 220-12993 -3 AN Flexline (×2) | Wilwood | ~$50-70 | High | 8" w/ 11/16-20 adapter - [iBooster][ibooster] |
| iBooster Wiring Harness | Tulay's or EVcreate | ~$60-150 | High | {{ tbd(105) }}: Gen 2 universal vs EVcreate kit - [Harness][tulays] |
| Firewall backing plate (cabin side) | SendCutSend | ~$15-30 | High | Flat 3/16" steel sandwich plate, donor bracket pattern + 62mm center - [iBooster][ibooster] |
| JL Audio MV800/8i Amplifier (010-03339-00) | JL Audio (Garmin) | ~$900 | Medium | 8-ch w/ DSP, replaces Fusion AP61800 plan - [Amplifier][amplifier] |
| JL Audio M6-8IB-S-GmTi-i-4 Subwoofer (×2) | JL Audio | ~$700 (pair) | Low | Replaces single M7-12IB plan - [Subwoofer][subwoofer] |
| JL Audio VXi-BTC JLid Bluetooth Communicator (010-13543-00) | JL Audio (Garmin) | ~$100 | Low | Wireless TüN tuning of MV800/8i from phone/tablet - [Bluetooth Tuning][bt-tuning] |
| JL Audio MLC-RW LED Controller | JL Audio | ~$250 | Low | [LED Controller][led-controller] |
| Digital Guard Dawg PBS-I Keyless Ignition Kit | Digital Guard Dawg | ~$200 (est., confirm w/ vendor) | High | ICM + 2 iTag fobs + Start Button + Programming Button + Bypass Card - [Keyless Ignition][keyless] |
| ARB Aluminum Air Tank (171507, 1-gal 4-port) | ARB | ~$200 | Medium | [Air Compressor][air-compressor] |
| WolfBox G900 TriPro Dash Camera | WolfBox | ~$200 | Low | [Dash Camera][dash-camera] |
| AMOT 4261M02A027-AA Air Shutoff Valve | AMOT | ~$400-500 | High | 2.8" manual/pneumatic, NPT - [Runaway Protection][runaway-protection] |
| DomiWorks 24004001 Transfer Case Adapter | DomiWorks (DriftHQ, US stock) | $1,005.90 | High | 8HP70 EcoDiesel → NP241 family; OR-variant + input-gear confirm pending {{ tbd(313) }} - [Transfer Case][transfer-case] |
| 23-spline input gear (ZTNP22390 or equiv.) | Transmission parts supplier | — | High | Required by the adapter; may be satisfied by the OR's factory gear {{ tbd(313) }} - [Transfer Case][transfer-case] |

---

## Drivetrain - 1-Ton Axle Swap

Parts for the Super Duty Dana 60 front and Sterling 10.5 rear. Prices unconfirmed except where noted; see [Front Axle][front-axle] and [Rear Axle][rear-axle].

| Item | Manufacturer | Est. Price | Priority | Notes |
| :--- | :--- | :--- | :--- | :---- |
| ARB RD140 Air Locker (Rear) | ARB | ~$1,400 (vendor list) | High | 35 spline, all ratios - [Rear Axle][rear-axle] |
| Revolution D60 reverse 5.13 ring & pinion, standard thickness | Revolution Gear | — | High | Not D60-513RT (thick) or REV-F350-513-K - [Front Axle][front-axle] |
| Revolution D60 reverse master install kit | Revolution Gear | — | High | [Front Axle][front-axle] |
| Revolution F10.25-513L 5.13 ring & pinion (long pinion) | Revolution Gear | — | High | Sourcing {{ tbd(297) }}; 10.25" gear run in the 10.5 housing - [Rear Axle][rear-axle] |
| Revolution 35-2046 master install kit | Revolution Gear | — | High | 10.5 housing with F10.25 gear (not 35-2046A) - [Rear Axle][rear-axle] |
| Revolution SK F10.5-Conv pinion spacer | Revolution Gear | — | High | Only if the rear donor housing is 2008-2010 - [Rear Axle][rear-axle] |
| Yukon Hardcore YHC70011 locking hubs | Yukon | — | Medium | 35 spline - [Front Axle][front-axle] |
| Spicer SPL55-3X u-joints (x4) | Spicer | — | Medium | 2 installed, 2 spare - [Front Axle][front-axle] |
| American Iron AI-1900 trail hardware kit | American Iron | — | Medium | [Front Axle][front-axle] |
| Riffraff RDPABS ABS block-off fitting (x2) | Riffraff Diesel | ~$50 (~$24.82 ea) | Medium | Front wheel ends, one per knuckle; sold individually - [Front Axle][front-axle] |
| Rear ABS opening plug | — | — | Medium | Size depends on donor housing year {{ tbd(310) }} - [Rear Axle][rear-axle] |
| Motobilt truss, front and rear | Motobilt | — | Medium | Weld before internals - [Front Axle][front-axle], [Rear Axle][rear-axle] |
| Motobilt differential cover, front and rear | Motobilt | — | Medium | [Front Axle][front-axle], [Rear Axle][rear-axle] |
| PowerStop Z36 Truck & Tow kit, front and rear | PowerStop | — | Medium | Match to donor axle years - [Brakes][brakes] |
| 1350 pinion yokes, strap style (29 spline front, 31 spline rear) | — | — | Medium | Set the driveshaft axle-end series - [Front Axle][front-axle], [Rear Axle][rear-axle] |
| Tom Woods driveshafts, pair, 1350 CV | Tom Woods | — | Low | Measure at final ride height - [Driveshafts][driveshafts] |

---

## Lighting - Baja Designs ($100-$500+ each)

| Item | Quantity | Est. Unit Price | Est. Total | Priority | Notes |
|:-----|:---:|:---|:---|:---|:---|
| LP6 Pro DOT Headlights | 2 | ~$600 | ~$1,200 | High | Pair - [Headlights][headlights] |
| LP4 Pro Driving/Combo (Ditch) | 2 | ~$400 | ~$800 | Medium | [Ditch Lights][ditch-lights] |
| S8 10" Wide Cornering Amber (Fog) | 1 | ~$500 | ~$500 | Medium | [Fog Lights][fog-lights] |
| XL Sport Linkable (Roof) | 8 | ~$150 | ~$1,200 | Medium | [Roof Lights][roof-lights] |
| Squadron Sport Wide Cornering (Reverse) | 2 | ~$200 | ~$400 | Medium | [Reverse Lights][reverse-lights] |
| S1 Black LED (Rear Work) | 2 | ~$100 | ~$200 | Low | [Rear Work Lights][rear-lights] |
| S2 Sport Black Flush Mount (Cargo) | 2 | ~$150 | ~$300 | Low | [Cargo Lights][cargo-lights] |
| RTL-S 30" (Chase) | 1 | ~$400 | ~$400 | Low | [Chase Light][chase-light] |

**Baja Designs Total:** ~$5,000

---

## Lighting - Other

| Item | Quantity | Est. Unit Price | Est. Total | Priority | Notes |
|:-----|:---:|:---|:---|:---|:---|
| LED4Life RGBW Pods (Footwell) | 4 | ~$15 | ~$60 | Low | [Footwell Lights][footwell-lights] |
| KC HiLiTES Dual Cyclone Dome Light Mount #6337 | 1 | — | — | Medium | ADC12 aluminum, roll cage mount; required by [Dome Lights][dome-lights] |

---

## Audio - JL Audio Speakers

| Item | Quantity | Est. Unit Price | Est. Total | Priority | Notes |
|:-----|:---:|:---|:---|:---|:---|
| M6-650X-S-GmTi-i (Front) | 2 | ~$250 | ~$500 | Medium | [Speakers][speakers] |

---

## Distribution & Grounding

_(Most electrical distribution components already purchased - see Purchased Items)_

| Item | Quantity | Est. Price | Priority | Notes |
|:-----|:---:|:---|:---|:---|
| Bussmann LR-2 Body PDU | 1 | ~$50-100 | Medium | eBay surplus - [BODY PDU][body-pdu] |
| START+ Forward Distribution Busbar (Blue Sea 2105) | 1 | ~$40 | High | Engine-bay START+ fan-out for relocated fan/iBooster/TCU — {{ tbd(135) }} - [START Distribution][start-fwd-bus] |
| Circuit breakers — 100A master + 60A / 50A / 25A (Mechanical Products S17) | 4 | ~$120 | High | Forward-bus master (downsized from 150A, 2026-09-22) + fan/iBooster/TCU load CBs — {{ tbd(135) }} - [Circuit Breakers][start-cbs] |
| AUX forward-feed CB 250A (MP 174-S2-250-2) + amp CB 80A (Blue Sea 187-series) | 2 | ~$90 | High | Replace the 300A / 100A units in the plan (downsized 2026-09-22); skip if not yet bought - [AUX Circuit Breakers][aux-cbs] |
| Lingenfelter VSFM-002 fan controller + coolant temp sensor | 1 | ~$190 | High | PWM brushless controller w/ own sensor; sensor P/N + fail-to-full-speed confirm — {{ tbd(134) }} - [Radiator Fan][radiator-fan] |
| Fan power relay (continuous-duty) | 1 | ~$20 | High | Switches fan power at the forward bus - [Radiator Fan][radiator-fan] |

---

## Low Value (<$100)

| Item | Manufacturer | Est. Price | Priority | Notes |
|:-----|:---|:---|:---|:---|
| Barnes 4WD Battery Box (Group 24) | Barnes 4WD | ~$67 | High | Backorder - [Batteries][batteries] |
| Ron Francis WS-51C Wiper Controller | Ron Francis | ~$80 | Medium | [Wipers][wipers] |
| Overvoltage Protection Relay | Generic | ~$15-25 | Low | Solar protection - [Solar][solar] |
| Deutsch HDP24-24-29 Connector Kit | Deutsch | ~$80 | High | [Firewall Ingress][firewall-ingress] |
| SwitchPros 2-pin Delphi connector hardware (~12 harnesses: bodies, terminals, seals) | SwitchPros | — | High | P/N {{ tbd(156) }}; plug-and-play output harnesses - [SwitchPros][switchpros-sp1200] |
| ARB Air Line Installation Kit | ARB | ~$50 | Medium | [Air Lockers][air-lockers] |
| 0-200 PSI Pressure Gauge | Generic | ~$20 | Medium | [Air Compressor][air-compressor] |
| Air Chuck Plate and Fittings | Generic | ~$30 | Low | [Rear Air Chuck][rear-air-chuck] |
| Center-Off Momentary Rocker Switch | Generic | ~$15 | Medium | Winch control - [Dashboard][dashboard] |
| 4x4 indicator relay (SPST micro, 12V coil) | Generic | ~$10 | Medium | Sinks the HDX 4x4 input (PMU is high-side); mounts at the HDX - [Transfer Case][transfer-case] |
| Transfer case 5-position switch (5083138AA / Omix 18676.52) | Mopar / Omix-Ada | ~$50 | Low | **Only if** the donor NP241OR arrives without one ({{ tbd(145) }}) - [Transfer Case][transfer-case] |
| Mishimoto MMOCC-CBT Compact Baffled Catch Can | Mishimoto | ~$150 | High | 13 oz, petcock drain - [Runaway Protection][runaway-protection] |
| Mishimoto MMOCC-UB Universal Mounting Bracket | Mishimoto | ~$40 | High | [Runaway Protection][runaway-protection] |
| Midwest Control 30-144-TTL-BH-3 Push-Pull Cable | Midwest Control | ~$60-80 | High | 144" turn-to-lock T-handle, 3" travel - [Runaway Protection][runaway-protection] |
| 5/8" Oil-Resistant Hose (2 ft) + Worm Clamps | Generic | ~$15 | High | Catch can plumbing - [Runaway Protection][runaway-protection] |
| NPT-to-Hose Adapter Fittings (AMOT to intake) | Generic | ~$25 | High | Size per measured turbo inlet - [Runaway Protection][runaway-protection] |
| 3/16" Copper-Nickel Brake Hardline + Fittings + Armor | Generic / AGS | ~$60-90 | High | Caliper-side hybrid: armored hardline routed inside frame rail + 1/2-20 IF inverted-flare fittings at MC; axle-side flex length separate ({{ tbd(86) }}) - [iBooster][ibooster] |
| Heated Seat Switches (2× Toyota-style ON/OFF) | Generic | ~$20-30 | Medium | 1.54"×0.83" cutout; wire to BODY PDU CB45/CB42 via K21/K22 relays - [Dashboard][dashboard] |
| Air Locker Switches (2× Toyota-style latching ON/OFF, front + rear) | Generic | ~$20-30 | Medium | 1.54"×0.83" cutout (not ARB's 21×36.5 mm); BODY PDU CB44 via K27, front fed from rear per ARB - [Dashboard][dashboard] |
| Driver-side Firewall Grommet (heavy power) | Steele Rubber or equiv | ~$10-20 | High | ~1.5" OD bundle (3× 2/0 AWG H2 cables); new driver-side penetration - [Firewall Ingress][firewall-ingress] |
| Passenger-side Firewall Grommet (H1) | Steele Rubber or equiv | ~$15-25 | High | Sealed 2-piece, ~1.5" OD H1 bundle (~1.75" hole), continuous run - [Firewall Ingress][firewall-ingress] |
| Axle breather relocation kit + braided line (both axles) | Generic | — | High | Route high into the engine bay; locate before the truss weld - [Front Axle][front-axle], [Rear Axle][rear-axle] |

---

## Remaining Major Purchases Summary

| Category | Est. Total | Priority Items |
|:---|:---|:---|
| Alternator | ~$900 | Critical |
| Wilwood MC + adapter + plumbing (iBooster purchased) | ~$900-1,400 | Critical for brakes |
| ARB 1-Gallon Tank + Pressure Gauge | ~$220 | Medium |
| Baja Designs Lighting | ~$5,000 | Medium-Low |
| Audio (Amp, Sub, Front Speakers) | ~$1,350 | Low |
| Misc Small Parts | ~$450 | Various |
| 1-Ton Axle Swap (Dana 60 front, Sterling 10.5 rear) | — (unpriced) | High |
| **TOTAL REMAINING** | **~$8,050-8,550** (excl. axle swap) | |

---

## Vendor Notes

**Best Times to Buy:**

- **Black Friday/Cyber Monday:** Baja Designs, ARB, audio equipment
- **Amazon Prime Day:** Generic components, Blue Sea, wire/connectors
- **4WP/Quadratec Sales:** ARB, Warn, recovery equipment
- **Direct from Manufacturer:** SwitchPros, ECUMaster (less frequent sales)

**Vendors to Watch:**

| Vendor | Products | Notes |
|:---|:---|:---|
| [Baja Designs][bd-site] | All BD lighting | Occasional 15-20% sales |
| [4 Wheel Parts][4wp-site] | ARB, Warn, general | Member pricing, frequent sales |
| [Quadratec][quad-site] | Jeep-specific | Points program, bundle deals |
| [Crutchfield][crutch-site] | Fusion, JL Audio | Often includes install kits |
| [Amazon][amazon] | Blue Sea, generic | Prime deals, price tracking |
| [Premier Power Welder][ppw-site] | Alternator | Direct only |
| [ECUMaster][ecum-site] | PMU24 | Direct only |
| [SwitchPros][sp-site] | SP-1200, CT4 | Direct only |
| [Dakota Digital][dd-site] | Gauge cluster, BIMs | Dealer network |

---

## Related Documentation

- [Power Systems Checklist][power-checklist] - Installation sequence
- [Engine Systems Checklist][engine-checklist] - Installation sequence
- [TBD Tracker][tbd-tracker] - Outstanding decisions

[alternator]: ../01-power-systems/01-power-generation/02-alternator.md
[pmu]: ../01-power-systems/04-pmu/01-pmu-overview.md
[ct4]: ../05-control-interfaces/03-command-touch-ct4.md
[navigation]: ../07-communication-systems/05-navigation.md
[bcdc]: ../01-power-systems/01-power-generation/03-bcdc.md
[winch]: ../08-exterior-systems/01-winch.md
[air-compressor]: ../08-exterior-systems/02-air-compressor.md
[ibooster]: ../02-engine-systems/02-brake-booster.md
[hvac]: ../02-engine-systems/03-hvac.md
[tulays]: https://tulayswirewerks.com/product/bosch-ibooster-gen-2-universal-wire-harness/
[batteries]: ../01-power-systems/01-power-generation/01-batteries.md
[amplifier]: ../06-audio-systems/02-amplifier.md
[subwoofer]: ../06-audio-systems/04-subwoofer.md
[led-controller]: ../06-audio-systems/05-led-controller.md
[bt-tuning]: ../06-audio-systems/06-bluetooth-tuning.md
[intercom]: ../07-communication-systems/02-intercom.md
[keyless]: ../05-control-interfaces/06-keyless-ignition.md
[air-lockers]: ../08-exterior-systems/03-air-lockers.md
[rear-axle]: ../10-drivetrain/05-rear-axle.md
[front-axle]: ../10-drivetrain/04-front-axle.md
[steering]: ../10-drivetrain/07-steering.md
[driveshafts]: ../10-drivetrain/03-driveshafts.md
[brakes]: ../10-drivetrain/08-brakes.md
[solar]: ../01-power-systems/01-power-generation/04-solar.md
[dash-camera]: ../07-communication-systems/04-dash-camera.md
[starter]: ../02-engine-systems/01-starter.md
[headlights]: ../03-lighting-systems/02-headlights.md
[ditch-lights]: ../04-offroad-lighting/01-ditch-lights.md
[fog-lights]: ../04-offroad-lighting/02-fog-lights.md
[roof-lights]: ../04-offroad-lighting/03-roof-lights.md
[reverse-lights]: ../04-offroad-lighting/10-reverse-lights.md
[rear-lights]: ../04-offroad-lighting/08-rear-lights.md
[cargo-lights]: ../04-offroad-lighting/07-cargo-lights.md
[dome-lights]: ../03-lighting-systems/06-dome-lights.md
[switchpros-sp1200]: ../05-control-interfaces/02-switchpros-sp1200.md
[chase-light]: ../04-offroad-lighting/04-chase-lights.md
[footwell-lights]: ../04-offroad-lighting/09-footwell-lights.md
[speakers]: ../06-audio-systems/03-speakers.md
[body-pdu]: ../01-power-systems/03-aux-battery-distribution/03-body-pdu.md
[wipers]: ../02-engine-systems/04-wipers.md
[firewall-ingress]: ../01-power-systems/07-wire-routing/02-firewall-ingress.md
[rear-air-chuck]: ../08-exterior-systems/04-rear-air-chuck.md
[dashboard]: ../05-control-interfaces/05-dashboard-controls.md
[transfer-case]: ../10-drivetrain/02-transfer-case.md#position-sensing
[power-checklist]: 01-power-systems-checklist.md
[engine-checklist]: 02-engine-systems-checklist.md
[start-fwd-bus]: ../01-power-systems/02-starter-battery-distribution/index.md#start-forward-bus
[start-cbs]: ../01-power-systems/02-starter-battery-distribution/01-circuit-breakers.md
[aux-cbs]: ../01-power-systems/03-aux-battery-distribution/01-circuit-breakers.md
[radiator-fan]: ../02-engine-systems/06-radiator-fan.md
[runaway-protection]: ../02-engine-systems/11-runaway-protection.md
[tbd-tracker]: ../tbd-tracker.md
[bd-site]: https://www.bajadesigns.com/
[4wp-site]: https://www.4wheelparts.com/
[quad-site]: https://www.quadratec.com/
[crutch-site]: https://www.crutchfield.com/
[amazon]: https://www.amazon.com/
[ppw-site]: https://premierpowerwelder.com/
[ecum-site]: https://www.ecumaster.com/
[sp-site]: https://www.switchpros.com/
[dd-site]: https://www.dakotadigital.com/

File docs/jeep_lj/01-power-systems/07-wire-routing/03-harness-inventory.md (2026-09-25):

---
hide:
  - toc
tags:
  - wire-routing
  - harness
---

# 1.7.3 Harness Inventory {#harness-inventory}

## Purpose

Catalogs each fabricatable wire harness in the build. A "harness" here = a discrete bundle of wires with a defined start connector, end connector(s), routing path, and BOM — something you'd lay out on a workbench and tape together as a unit.

This page is the **index and system-wide view**. The detailed, build-it-from-this specs (conductor tables, gauges, colors, lengths, protection, connectors) live on the three **build sheets** below — each pairs the harnesses with the [LJ Tub Map][lj-tub-map] diagram that shows their physical routing.

**Use these docs to:**

- Order connectors and lugs in correct quantities
- Plan fabrication order (build harnesses bench-side, install in vehicle)
- Identify reuse / consolidation opportunities
- Define service-replaceable units (one harness fails → replace just that segment)

**Bundling philosophy:** Each harness terminates at a connector at every transition point (firewall, body penetration, distribution box). This makes harnesses individually serviceable and lets you lay them out flat for fabrication. The cost is more connectors; the benefit is much easier R&R.

**Numbering note:** Two prior bundles (the old H1+H4 power trunk and the old H6+H7 rear cabin bundle) were merged in May 2026. The catalog was renumbered to a single sequence H1–H9 — there are no compound names (no "H1/4", no "H6/7"). See the [interference assessment](#bundle-interference-assessment) for why the merged bundles are safe.

---

## Harness Build Sheets

Each build sheet embeds the matching tub-map diagram and the workbench specs for the harnesses it shows.

| Build sheet | Tub-map page | Harnesses |
|:---|:---|:---|
| [Power Distribution][power-build] | Power Distribution | **H1** Passenger Rear Power Trunk · **H2** START Engine Bay Trunk · **H3** BCDC Cross-Cab |
| [Lighting & SwitchPros][lighting-build] | Lighting & SwitchPros | **H4** SwitchPros Front Bundle · **H5** Rear Cabin Trunk Bundle |
| [Controls, Recovery & Drivetrain][controls-build] | Controls, Recovery & Drivetrain | **H6** ARB Compressor · **H7** Winch Trigger · **H8** Kilduff Shifter · **H9** TCU to Engine Bay |

## Harness Summary

| # | Harness | Build sheet | Conductors | Largest gauge | Length |
|:--|:---|:---|:---:|:---:|:---|
| H1 | Passenger Rear Power Trunk (AUX fwd + winch) | [Power][power-build] | 3 | 2/0 AWG | ~13 ft (+13 ft winch to bumper) |
| H2 | START Engine Bay Trunk (alt + starter + PMU feed + START+ fwd-bus feed) | [Power][power-build] | 4 | 2/0 AWG | 6–8 ft |
| H3 | BCDC Cross-Cab | [Power][power-build] | 2 | 1/0 AWG | ~5–6 ft |
| H4 | SwitchPros Front Bundle | [Lighting][lighting-build] | 3 outputs | 14 AWG | 4–8 ft |
| H5 | Rear Cabin Trunk Bundle (SP rear + PMU rear) | [Lighting][lighting-build] | ~10 | 14 AWG | 8–14 ft |
| H6 | ARB Compressor | [Controls][controls-build] | 4 | 6 AWG | ~10 ft |
| H7 | Winch Trigger | [Controls][controls-build] | 5 | 18 AWG | ~3 ft + ~13 ft |
| H8 | Kilduff Shifter → TCU | [Controls][controls-build] | 1 (multi) | Proprietary | ~3–5 ft |
| H9 | TCU → Engine Bay | [Controls][controls-build] | 6 | 14 AWG | 3–4 ft |

!!! note "Engine-bay distribution nodes (not cabin harnesses)"
    Two busbars fan power out to local loads and so are **not** catalogued as fabricatable cabin harnesses — like the Firewall CONSTANT bus, they are distribution points, and their short local feeds are built in place:

    - **START+ Forward Distribution Bus** (Blue Sea 2105 MaxiBus, engine bay) — fed by H2's 2 AWG forward-bus master feed; fans out on short engine-bay local feeds to the radiator fan (4 AWG), iBooster main (8 AWG), and TCU (12 AWG). The TCU's leg is carried by [H9][controls-build]; the fan and iBooster legs are short engine-bay runs. See [START+ Forward Distribution Bus][start-fwd-bus].
    - **Firewall CONSTANT bus** (cabin side) — fed by H1's 2/0 AWG forward feed; fans out to SwitchPros, BODY PDU, and Fusion. See [AUX Battery Distribution][aux-battery].

## Wire Color Convention {#wire-color-convention}

Colors on the build sheets follow this convention. Power and ground colors are universal automotive practice; signal colors are the builder's choice — pick a consistent scheme and keep it the same across every harness.

| Wire role | Color | Notes |
|:---|:---|:---|
| Power / positive feed (+) | **Red** | All constant/switched +12V distribution, feeds, and high-current power |
| Ground / negative (−) | **Black** | All returns and battery negatives |
| CAN bus | **Twisted pair** | Keep the pair twisted; do not split. Color per controller (e.g., J1939) |
| Vendor-supplied harness | **Per vendor pigtail** | SwitchPros (Delphi), ARB, CH4X4, Kilduff/ZF ship their own colors — match the supplied pigtail |
| Signal / trigger / output (non-vendor) | **Builder's choice** | Choose a consistent scheme and record it |

For protective wrap/loom, heat sleeve, abrasion sleeve, and P-clamp standards by location, see [Wire Protection Standards][wire-routing]. This build wraps power runs in braided sleeve with per-harness tracers — see [Protective Sleeve & Tracers](#sleeve-convention).

## Protective Sleeve & Tracers {#sleeve-convention}

Wrap preference for this build:

- **Default is black braided expandable sleeve** (PET, e.g. Techflex Flexo PET) over the full length of power runs, sized to the bundle OD. Black is the base color; a contrasting **tracer stripe** woven into the sleeve identifies each power trunk where several run together (e.g. in the cabin trunk). Braided sleeve is abrasion-resistant, flexes around the sill / trans-tunnel path, and lets you fan branches out without cutting the wrap.

| Harness | Sleeve | Carries |
|:---|:---|:---|
| **H1** Passenger Rear Power Trunk | Black braided, red tracer | AUX forward feed + winch power/ground |
| **H2** START Engine Bay Trunk | Black braided, yellow tracer | Alternator, starter, PMU feed, START+ forward-bus feed |
| **H3** BCDC Cross-Cab | Black braided, green tracer | BCDC input + cross-ground reference |
| **H6** ARB Compressor (motor pair) | Black braided, blue tracer | 2× 6 AWG compressor motor cables |

- **Heat sleeve still applies** where any run enters the engine bay within ~12" of exhaust — over the braided sleeve as needed.
- **Split loom** remains fine for the small-wire signal/lighting bundles (H4, H5, H7, H9) and for short, branchy, or frequently-accessed runs where braided sleeve is awkward; use a braided sleeve with a tracer instead if you prefer to color-code those too. H8 ships as a factory harness (no added wrap needed beyond loom through the tunnel).

---

## Harness Map

```text
                  ┌──────────────────────────────────────────────────┐
                  │                  ENGINE BAY                       │
                  │                                                   │
  H2 START trunk ─►──┐                                                │
                     │ alt, starter, PMU feed, START+ fwd-bus feed    │
                     │                                                │
                     ▼                                                │
                  ┌─────┐                                             │
                  │ PMU │◄────── H4 SP front ◄──┐                     │
                  └──┬──┘                       │                     │
                     │                          │                     │
  ═════════════════════════════════ FIREWALL ═════════════════════════│
                     │                          │                     │
                     ▼ HDP24                    │                     │
                  ┌──────────────────────────────────┐                │
                  │  FIREWALL CLUSTER (cabin side):  │                │
                  │  SwitchPros + GND bus + BODY PDU │                │
                  │  + Firewall CONSTANT bus + CBs   │                │
                  │  (audio amp on direct AUX feed)  │                │
                  └────┬──────────────┬──────────────┘                │
                       │              │                               │
                       │      H5 Rear Cabin Trunk Bundle              │
                       │      (SwitchPros rear + PMU rear, ~10 cond)  │
                       │              │                               │
                       ▼              ▼                               │
                  ┌─────────────────────────────────────────┐         │
                  │  CABIN TRUNK                            │         │
                  │  Forward (passenger side): H1           │         │
                  │  Forward (driver side): H2              │         │
                  │  Rearward: H5 + CT4 turn + H6 signal    │         │
                  │  Cross-cab: H3 (under rear bench)       │         │
                  └────┬──────────────────────────┬─────────┘         │
                       │                          │                   │
                       ▼                          ▼                   │
       ┌─────────────────────┐         ┌────────────────────┐         │
       │ DRIVER REAR WELL    │         │ PASSENGER REAR WELL│         │
       │ • START battery     │◄────────│ • AUX battery      │         │
       │ • 250A + 80A CBs    │  H3     │ • 250A + 150A CBs  │         │
       │                     │ BCDC    │ • SafetyHub        │         │
       │                     │ cross   │ • BCDC             │         │
       │  H2 ↑ (4 cables)    │ (under  │  H1 ↑ (3 cables)   │         │
       │  driver floor/wall  │  rear   │  passenger         │         │
       │  to engine bay      │  bench) │  floor/wall to     │         │
       │                     │         │  sealed grommet    │         │
       └─────────────────────┘         │  at firewall;      │         │
                                       │  winch portion     │         │
                                       │  continues to      │         │
                                       │  front bumper      │         │
                                       │  H6 ARB compressor │         │
                                       │  → under pass seat │         │
                                       └──────┬─────────────┘         │
                                              │                       │
                                              ▼                       │
       ┌─────────────────────────────────────────────────────────────┐
       │  FRONT BUMPER (H1 winch portion terminates)                 │
       │  REAR CARGO BULKHEAD (H5 multi-pin breakout)                │
       └─────────────────────────────────────────────────────────────┘
```

---

## Bundle Interference Assessment {#bundle-interference-assessment}

Two harnesses (H1 and H5) bundle multiple originally-separate runs into a single sleeve. EMI/crosstalk evaluation:

**H1 (Passenger Rear Power Trunk) — 1× 2/0 AWG forward feed + 2× 1/0 AWG winch power/ground:**

- All three conductors carry power only — no sense lines, no signal returns, no CAN/audio/analog.
- Inductive coupling between adjacent power conductors is irrelevant for distribution (the coupled noise has no signal path to corrupt; loads see CB-protected DC).
- Winch peak current (~409A, seconds) raises a strong transient B-field but does not couple to the parallel forward-feed cable in any way that matters at the firewall CONSTANT bus.
- **Verdict: no interference risk. Safe to bundle.**

**H5 (Rear Cabin Trunk Bundle) — SP lighting outputs + PMU OUT-21/22/23 + 1 SP trigger return:**

- SP OUT-6/7/10/12/13 are switched DC for lighting loads (14 AWG), not PWM.
- PMU OUT-21/22/23 are switched DC for brake / reverse / parking tail signals (16 AWG), not PWM in this build (no dimming required; tail circuits run at full output when commanded).
- TRIGGER-2 (18 AWG) is a switch return from the rear cargo rocker. SP triggers require sustained 12V to register; brief inductive transients from adjacent switched outputs are filtered by the SP input.
- No CAN bus, no audio signal, no analog sensor wiring shares this bundle. (CT4 rear turn signals were considered for inclusion — they would also be switched DC and remain safe to add later.)
- **Verdict: no interference risk under current load profile. Safe to bundle.** If a future change introduces PWM dimming on any PMU rear output, re-evaluate — twisted pair or shielding may be warranted for the TRIGGER-2 line in that case.

**Other bundles (H2, H3, H4, H6, H7, H8, H9):** Each is single-purpose with homogeneous content (H2 = power only; H3 = power + ground reference; H4 = SP outputs; H6 = ARB power + signal already noted as physically separable; H7 = trigger logic only; H8 = factory shifter harness; H9 = TCU connections, includes twisted CAN pair). No new bundling concerns.

---

## Cabin Trunk Bundle Summary

The **cabin trunk** (trans tunnel / sill, firewall ↔ rear wheel wells) carries multiple harnesses in parallel. Total bundle inventory:

| Direction | Harness | Cable count | Largest gauge | Path side |
|:---|:---|:---:|:---:|:---:|
| Forward (rear → firewall) | **H1** Passenger Rear Power Trunk (AUX fwd + winch power+gnd) | 3 | 2/0 AWG | Passenger sill/floor |
| Cross-cab | H3 (BCDC inter-battery + cross-gnd) | 2 | 1/0 AWG | Under rear bench |
| Forward (driver rear → engine bay) | H2 (alt, starter, PMU feed, START+ fwd-bus feed) | 4 | 2/0 AWG | Driver sill/floor |
| Rearward (firewall → rear) | **H5** Rear Cabin Trunk Bundle (SP rear outputs + PMU rear lighting) | ~10 | 14 AWG | Trans tunnel |
| Rearward (firewall → rear) | CT4 rear turn signals | 2 | 14 AWG | Trans tunnel (could merge into H5) |
| Rearward (firewall → under pass seat) | SwitchPros control + pressure (ARB) | 2 | 14–18 AWG | Trans tunnel (per H6 optimization) |

**Passenger sill/floor (H1):** ~3 cables, ~1.5" OD bundle, continuous through a sealed 2-piece grommet at the firewall (no bulkhead studs — see optimization note below)

**Driver sill/floor (H2):** ~4 cables (3× 2/0 AWG + 1× 2 AWG), ~1.6" OD bundle, terminates at heavy power grommet at firewall

**Trans tunnel rearward (H5 + CT4 + ARB signal):** ~14 conductors of small wire (14–18 AWG)

**Suggested trunk wrap:** 1.5"–2" braided expandable sleeve (preferred for the power runs) or split loom per side, tracer-coded per harness so the bundles stay identifiable — see [Protective Sleeve & Tracers](#sleeve-convention). P-clamp every 12–18".

---

## Bundle Optimization Opportunities (Summary)

These were noted inline on the build sheets; consolidated here for review:

1. ~~Old H4 + old H1 share rear-well → firewall path~~ **Resolved (2026-05-30):** Merged into single **H1 Passenger Rear Power Trunk**. Firewall transition uses a **single sealed 2-piece rubber grommet** (e.g., Steele Rubber) — cables run continuously, no service break. Bulkhead studs (Blue Sea 2203/2204) max at 250A and were underrated for the winch peaks (409A); Anderson SB175 was also undersized. Continuous-cable + grommet is WARN's documented standard for high-current firewall pass-through.
2. ~~Old H6 + old H7 + CT4 rear turn + old H8 SP signal wires share cabin trunk → rear~~ **Partially resolved (2026-05-30):** Old H6 + old H7 merged into **H5 Rear Cabin Trunk Bundle** with single multi-pin breakout (Deutsch DT15 or AMP CPC ~15-pin) at rear cargo bulkhead. CT4 rear turn signals and ARB control wires *could* still join — pending decision.
3. **H5 sub-harness (firewall → rear breakout) is a single straight pull;** R&R of any individual rear light becomes a pigtail swap.
4. **H6 motor cables only.** Move control/pressure wires into H5 since they originate at SwitchPros.
5. **Rock lights + fog in one bundle** through SwitchPros firewall bulkhead to engine bay → grille area. Splice/breakout at front for fan-out. (The front locker wire left this bundle on 2026-09-24; the lockers now run from dash switches in the cabin.)
6. ~~HDP20 firewall connector pin budget~~ **Resolved (2026-05-30):** Split into two dedicated bulkheads — HDP24-24-29 for non-SP traffic (18/29 used, 11 spare) + HDP24-18-14 for SwitchPros forward outputs (6/14 used, 8 spare). SP harness stays Delphi-native end-to-end. See [Pin Budget Audit][firewall-ingress].

---

## Outstanding Items

{{ tbds() }}

## Build Tasks

- [ ] Decide front bumper breakout connector style (Deutsch DT, AMP CPC, etc.)
- [ ] Decide rear cargo bulkhead breakout connector style and pin count
- [ ] Decide if ARB control wires merge into H5 (recommended) or run as H6 signal pair
- [ ] Source connector + lug + heat shrink BOM totals
- [ ] Confirm braided-sleeve sizes and per-harness tracer colors for the power runs (see [Protective Sleeve & Tracers](#sleeve-convention)); decide split loom vs braided for the small-wire bundles per zone
- [ ] Define and record the signal-wire color scheme for non-vendor signal/trigger wires (power = red, ground = black are fixed; see [Wire Color Convention](#wire-color-convention))

## Related Documentation

- [Power Distribution Build Sheet][power-build] - H1, H2, H3 with tub-map diagram
- [Lighting & SwitchPros Build Sheet][lighting-build] - H4, H5 with tub-map diagram
- [Controls, Recovery & Drivetrain Build Sheet][controls-build] - H6–H9 with tub-map diagram
- [Wire Routing][wire-routing] - Zone-based routing reference and protection standards
- [Firewall Ingress][firewall-ingress] - HDP24 pinout and penetrations
- [AUX Battery Distribution][aux-battery] - H1 source
- [START Battery Distribution][start-battery] - H2 and H3 source
- [SwitchPros SP-1200][switchpros] - H4, H5 source controller
- [PMU24 Outputs][pmu-outputs] - H5 source
- [SafetyHub 150][safetyhub] - H6, H7 source
- [Recovery Systems / Winch][recovery] - H1 (winch portion) destination
- [Air Compressor][air-compressor] - H6 destination

[power-build]: 04-harness-power-distribution.md
[lighting-build]: 05-harness-lighting-switchpros.md
[controls-build]: 06-harness-controls-recovery-drivetrain.md
[lj-tub-map]: 04-harness-power-distribution.md
[wire-routing]: index.md
[firewall-ingress]: 02-firewall-ingress.md
[aux-battery]: ../03-aux-battery-distribution/index.md
[start-battery]: ../02-starter-battery-distribution/index.md
[start-fwd-bus]: ../02-starter-battery-distribution/index.md#start-forward-bus
[switchpros]: ../../05-control-interfaces/02-switchpros-sp1200.md
[pmu-outputs]: ../04-pmu/03-pmu-outputs.md
[safetyhub]: ../03-aux-battery-distribution/04-safetyhub.md
[recovery]: ../../08-exterior-systems/01-winch.md
[air-compressor]: ../../08-exterior-systems/02-air-compressor.md

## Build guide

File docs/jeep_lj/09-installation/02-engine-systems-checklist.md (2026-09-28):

---
hide:
  - toc
tags:
  - engine-systems
  - installation
---

# Section 2: Engine Systems - Installation Checklist

Organized by installation order for efficient build workflow. Each item is a
check-off confirmation — specs and part numbers live in the linked source docs;
parts to buy live in the [Purchase Tracker][purchase-tracker].

---

## Phase 1: Starter System

- [ ] Confirm factory starter (shipped mounted on the crate engine) is secure; record its P/N from the tag
- [ ] Confirm START battery+ → starter battery post
- [ ] Confirm Cole Hersee solenoid mounted on firewall (engine bay side)
- [ ] Confirm starter battery post → Cole Hersee input
- [ ] Confirm Cole Hersee output → starter switch post
- [ ] Confirm PBS-I module mounted under-dash, powered from Critical Cabin PDU
- [ ] Confirm PBS-I PURPLE START → firewall Pin 15 → Cole Hersee coil+
- [ ] Confirm Cole Hersee coil- grounded to engine bay ground bus
- [ ] Confirm PBS-I PINK IGN → cabin ignition bus bar → firewall Pin 12 → ECM 12V + PMU Pin 7
- [ ] Confirm Start Button mounted on dash, harness plugged into PBS-I
- [ ] Confirm Programming Button stashed accessibly for tag-learn / Emergency Bypass

---

## Phase 2: Brake System

### Pre-Install Fab + Bench Test

- [ ] Bench test donor iBooster: apply ignition signal, verify motor cycles and pedal rod assists
- [ ] Discard factory Honda master cylinder
- [ ] Install Back Bay Customs adapter + Wilwood MC onto iBooster
- [ ] Mock up iBooster + MC assembly against firewall — verify engine-bay clearance BEFORE drilling
- [ ] Drill firewall for iBooster mounting (factory booster holes abandoned)
- [ ] Mock up reservoir standoff location, verify hood clearance

### Brake Pedal Swap

- [ ] Remove factory manual-trans pedal assembly
- [ ] Verify donor auto pedal: stop-lamp switch + clip present, bushing OK, arm not bent
- [ ] Install 03-06 auto brake pedal assembly
- [ ] Reconnect stop-lamp switch wiring: PMU In 2, PBS-I Brake input, Turbolamik brake input (T-tap, cabin splice)
- [ ] Plug clutch master cylinder firewall hole
- [ ] Bench-measure pedal ratio vs factory pedal (confirm MC stroke + iBooster rod travel headroom)
- [ ] Re-measure iBooster pushrod length after pedal install; adjust per harness vendor instructions

### iBooster Installation

- [ ] Confirm factory vacuum brake booster removed
- [ ] Confirm custom firewall bracket installed at factory booster location
- [ ] Confirm iBooster + Wilwood MC assembly mounted to firewall bracket
- [ ] Confirm secondary front support bracket installed
- [ ] Confirm Wilwood dual bracket + reservoirs mounted on standoff
- [ ] Confirm flexlines installed: reservoir → MC
- [ ] Confirm brake hardlines routed from MC to front/rear brakes
- [ ] Confirm iBooster wiring harness connected ({{ tbd(105) }}: Tulay's or EVcreate)
- [ ] Confirm iBooster main power connected (START+ Forward Dist Bus, 50A CB)
- [ ] Confirm iBooster ignition enable connected (Ignition bus Term 5, 7.5A fuse, firewall Pin 18)
- [ ] Confirm iBooster ground connected to engine bay ground bus (dedicated/redundant ground recommended)
- [ ] Bleed brake system; verify no leaks

---

## Phase 3: Grid Heater

- [ ] Confirm ECM pins 46/21 → grid heater relay coil
- [ ] Confirm fusible link from START battery+ to grid heater relay
- [ ] Confirm grid heater relay ground → START battery- or NEGATIVE bus
- [ ] Confirm grid heater relay mounted near intake manifold
- [ ] Verify grid heater element resistance confirms design current ({{ tbd(42) }})

---

## Phase 4: HVAC

- [ ] Confirm Restomod Air kit model/configuration against order on arrival ({{ tbd(146) }})
- [ ] Install Restomod Air HVAC kit per included instructions (factory TJ HVAC assembly, vacuum lines, and cable linkage removed)
- [ ] Verify Restomod Air blower draw ≤25A on PMU OUT5
- [ ] Wire control head compressor request → trinary switch → PMU In 9 (verify wire colors against kit diagram)

---

## Phase 5: Wipers

- [ ] Confirm WS-51C wiper controller mounted in dash
- [ ] Confirm PMU OUT11 → WS-51C power input
- [ ] Confirm WS-51C ground connected
- [ ] Confirm WS-51C low/high outputs → factory wiper motor
- [ ] Confirm wiper motor park switch → WS-51C park input
- [ ] Confirm WS-51C washer output → factory washer pump

---

## Phase 6: Radiator Fan

- [ ] Confirm GM 84100128 fan mounted to radiator shroud
- [ ] Confirm START+ Forward Dist Bus (60A CB) → relay → fan power
- [ ] Confirm Lingenfelter VSFM-002 + coolant sensor installed (sensor P/N + port {{ tbd(134) }})
- [ ] Confirm fan ground connected to engine bay ground bus
- [ ] Confirm VSFM-002 commands full speed on lost sensor signal ({{ tbd(134) }})

---

## Phase 7: Horn

- [ ] Confirm CT4 kit horn mounted in engine bay (kit bracket)
- [ ] Confirm PMU OUT18 → horn
- [ ] Confirm horn grounded to engine bay ground bus
- [ ] Confirm horn button trigger routed through firewall to PMU In 1
- [ ] Confirm PMU programmed: In 1 → OUT18

---

## Phase 8: Runaway Protection

### Catch Can Installation

- [ ] Confirm catch can bracket mounted ({{ tbd(58) }} — intake side, away from exhaust)
- [ ] Confirm catch can installed vertically with petcock at bottom
- [ ] Confirm hose from valve cover breather → catch can INLET
- [ ] Confirm hose from catch can OUTLET → turbo inlet
- [ ] Verify catch can petcock closed before first engine start

### AMOT Air Shutoff Installation

- [ ] Confirm AMOT installed in pre-turbo intake tract
- [ ] Confirm NPT-to-hose adapters secure on both AMOT ports
- [ ] Confirm AMOT butterfly cocks open and latches; lever orientation matches cable pull
- [ ] Confirm intake clamps secured (no boost or vacuum leaks)
- [ ] Confirm AMOT body oriented so trip lever clears obstructions through full motion

### Cable and T-Handle Installation

- [ ] Confirm T-handle mounted at dash location ({{ tbd(56) }})
- [ ] Confirm cable conduit passes through dedicated firewall grommet ({{ tbd(57) }})
- [ ] Confirm cable secured along run; no sharp bends
- [ ] Confirm cable end attaches to AMOT trip lever; pull stroke clears trip point
- [ ] Confirm T-handle sits flush against dash bezel when AMOT is cocked open
- [ ] Confirm T-handle labeled `EMERGENCY ENGINE SHUTOFF — PULL TO STOP`

---

## Phase 9: Testing

### iBooster Testing

- [ ] Verify iBooster main power present (ignition OFF and ON)
- [ ] Verify iBooster ignition signal present (RUN only)
- [ ] Verify iBooster ground continuity to battery negative
- [ ] Verify brake pedal feel with iBooster powered
- [ ] Verify fail-safe mode (disconnect ignition signal, confirm basic assist)
- [ ] Verify iBooster standby current within spec (ignition OFF) — {{ tbd(151) }}: standby spec not yet sourced
- [ ] Road test: light braking, hard braking, engine-off coasting

### HVAC Testing

- [ ] Verify temperature control (hot/cold blend)
- [ ] Verify mode control (defrost/vent/floor)
- [ ] Verify blower speeds
- [ ] Verify A/C clutch engagement
- [ ] Verify heater output

### Wiper Testing

- [ ] Verify wiper speeds: Off / Mist / Delay / Low / High
- [ ] Verify wiper park position
- [ ] Verify washer pump activates
- [ ] Verify auto-wipe triggers after washer spray

### Starter Testing

- [ ] Verify starter does NOT crank with brake released (PBS-I brake interlock)
- [ ] Verify starter does NOT crank when Start Button not pressed
- [ ] Verify starter does NOT crank without valid iTag fob in range
- [ ] Verify starter cranks when fob + Start Button + brake all asserted (warm engine)
- [ ] Verify cold-start sequence: IGN on → WAIT lamp illuminates → extinguishes → driver cranks (no auto-gate; driver waits for the lamp)
- [ ] Verify engine shutoff: brake + button hold → engine stops
- [ ] Verify Emergency Bypass: Programming Button + PIN authorizes start with fob absent
- [ ] Verify fob auto-arm after fob leaves range

### Grid Heater Testing

- [ ] Verify grid heater activates in cold conditions
- [ ] Verify "Wait to Start" lamp illuminates during preheat

### Horn Testing

- [ ] Verify horn sounds when button pressed (ignition OFF and ON)

### Radiator Fan Testing

- [ ] Verify voltage at fan terminals under load
- [ ] Verify fan activates at temperature setpoints
- [ ] Verify inverted duty cycle behavior (high duty = low speed)
- [ ] Tune temperature setpoints for R2.8 under real-world conditions

### Runaway Protection Testing

- [ ] Static test: engine OFF, pull T-handle, verify AMOT butterfly snaps fully closed
- [ ] Reset test: re-cock AMOT, push T-handle to flush, verify butterfly returns open
- [ ] Cable freedom: pull T-handle through full stroke, verify no binding
- [ ] Functional test (engine idling, clear area): pull T-handle, verify engine stalls
- [ ] Catch can drain check after first 100 miles (confirms PCV flow)

---

## Reference Documentation

- **Starter:** [Starter System][starter]
- **iBooster:** [Brake Booster System][ibooster]
- **Grid Heater:** [Grid Heater System][grid-heater]
- **HVAC:** [HVAC System][hvac]
- **Wipers:** [Wiper System][wipers]
- **Horn:** [Horn System][horn]
- **Radiator Fan:** [Radiator Fan System][radiator-fan]
- **Runaway Protection:** [Diesel Runaway Protection][runaway-protection]
- **Parts to buy:** [Purchase Tracker][purchase-tracker]

[starter]: ../02-engine-systems/01-starter.md
[ibooster]: ../02-engine-systems/02-brake-booster.md
[grid-heater]: ../02-engine-systems/07-grid-heater.md
[hvac]: ../02-engine-systems/03-hvac.md
[wipers]: ../02-engine-systems/04-wipers.md
[horn]: ../02-engine-systems/05-horn.md
[radiator-fan]: ../02-engine-systems/06-radiator-fan.md
[runaway-protection]: ../02-engine-systems/11-runaway-protection.md
[purchase-tracker]: 03-purchase-tracker.md

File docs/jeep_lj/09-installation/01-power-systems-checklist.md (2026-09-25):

# Section 1: Power Systems - Installation Checklist

Organized by installation order for efficient build workflow. Each item is a
check-off confirmation — wire gauges, lengths, torque values, and part numbers
live in the linked source docs, not here.

---

## Phase 1: Foundations

### Battery Compartments

- [ ] Install Odyssey PC1500 (START) in driver rear wheel well with access panel
- [ ] Build enclosed AUX compartment in passenger rear wheel well with access panel
- [ ] Install Barnes 4WD battery box in passenger rear wheel well
- [ ] Install Dakota Lithium (AUX) in Barnes battery box

### Grounding System

**Ground Bus Bars:**

- [ ] Mount Engine Bay Ground Bus on firewall (engine bay side) near PMU
- [ ] Mount Firewall Stud Bus on firewall (cabin side)
- [ ] Mount SwitchPros Ground Bus near SwitchPros controller

**Frame Rail Grounds:**

- [ ] Confirm front frame rail ground point located
- [ ] Confirm rear frame rail ground point located
- [ ] Confirm START battery- → Engine Bay Ground Bus
- [ ] Confirm Engine Bay Ground Bus → engine block
- [ ] Confirm Engine Bay Ground Bus → front frame rail
- [ ] Confirm AUX battery- → rear frame rail
- [ ] Confirm Firewall Stud Bus → chassis ground
- [ ] Confirm SwitchPros Ground Bus → chassis/frame rail
- [ ] Confirm Engine Bay Ground Bus → AUX battery- (cross-battery reference)

**Ground Testing:**

- [ ] Verify ground voltage drop within spec on all battery-to-frame paths (engine @ 2000 RPM)
- [ ] Verify cross-battery ground drop within spec under BCDC charging
- [ ] Verify cross-battery ground drop within spec under winch load

---

## Phase 2: Power Distribution

### START Battery Circuit Breakers

- [ ] Mount 250A circuit breaker (PMU main power) within reach of START battery
- [ ] Mount 80A circuit breaker (BCDC input) within reach of START battery
- [ ] Mount 100A circuit breaker (Forward Distribution Bus master) within reach of START battery
- [ ] Confirm START battery+ → 250A CB → PMU main power
- [ ] Confirm START battery+ → 80A CB → BCDC input
- [ ] Confirm START battery+ → 100A CB → 2 AWG forward feed → START+ Forward Distribution Bus
- [ ] Confirm PMU ground reference (Pin 25) → Engine Bay Ground Bus

**START+ Forward Distribution Bus (engine bay):**

- [ ] Mount START+ Forward Distribution Bus (Blue Sea 2105, {{ tbd(135) }}) in engine bay with insulated cover
- [ ] Mount 60A / 50A / 25A load breakers on a bracket beside the bus
- [ ] Confirm Forward Bus → 60A CB → radiator fan power (via relay)
- [ ] Confirm Forward Bus → 50A CB → iBooster main
- [ ] Confirm Forward Bus → 25A CB → Turbolamik TCU power
- [ ] Confirm iBooster enable → Ignition bus Term 5 (7.5A fuse) → firewall Pin 18
- [ ] Install Lingenfelter VSFM-002 radiator-fan controller + coolant sensor (sensor P/N {{ tbd(134) }}); verify fail-to-full-speed on lost sensor

**Direct Battery Connections (No Circuit Breaker):**

- [ ] Confirm ECM power/ground connected directly to START battery (per Cummins harness)
- [ ] Confirm grid heater relay powered from START battery+ (via integrated fusible link)
- [ ] Confirm grid heater ground connected directly to START battery-

**Radio Grounds (RF Noise Isolation):**

- [ ] Confirm GMRS Radio ground → START battery- (direct run for RF isolation)
- [ ] Confirm STX Intercom ground → START battery- (direct run for RF isolation)

**Testing:**

- [ ] Verify PMU main power always on
- [ ] Verify main power cable voltage drop within spec under load

### AUX Battery Inline CBs & Firewall CONSTANT Bus

- [ ] Mount 250A circuit breaker (forward feed to firewall bus) within reach of AUX battery
- [ ] Mount 150A circuit breaker (SafetyHub local feed) within reach of AUX battery
- [ ] Confirm AUX battery+ ring lugs landed: Winch, BCDC output, 250A CB, 150A CB, 80A CB (amp)
- [ ] Confirm AUX battery+ → 250A CB → Firewall CONSTANT Bus
- [ ] Confirm AUX battery+ → 150A CB → SafetyHub 150

**Firewall CONSTANT Bus:**

- [ ] Mount Firewall CONSTANT Bus on firewall (cabin side, near BODY PDU)
- [ ] Confirm forward feed terminates at bus input stud
- [ ] Mount 150A circuit breaker (SwitchPros) at Firewall CONSTANT Bus
- [ ] Mount 100A circuit breaker (BODY PDU) at Firewall CONSTANT Bus
- [ ] Mount 80A circuit breaker (JL Audio amp) at AUX battery bracket
- [ ] Confirm Firewall CONSTANT Bus → 150A CB → SwitchPros power module
- [ ] Confirm Firewall CONSTANT Bus → 100A CB → BODY PDU power studs
- [ ] Confirm AUX battery+ → 80A CB → JL Audio amp (direct AUX feed, not via firewall bus)

**Direct AUX Battery Connections (No Circuit Breaker):**

- [ ] Confirm AUX battery+ → Winch positive (direct connection per WARN spec)
- [ ] Confirm AUX battery- → Winch negative
- [ ] Confirm AUX battery- → JL Audio amp ground

### BCDC Alpha 50 Installation

- [ ] Mount BCDC in passenger rear wheel well (water-protected, LED visible)
- [ ] Confirm START battery+ → 80A CB → BCDC input
- [ ] Confirm BCDC output → AUX battery+
- [ ] Confirm BCDC negative → AUX battery-
- [ ] Confirm ignition signal → PMU ignition sense tap

**Battery Temperature Sensor (REQUIRED for LiFePO4):**

- [ ] Install BCDC temp sensor on AUX battery positive terminal
- [ ] Plug temp sensor into BCDC sensor port

**BCDC Configuration & Testing:**

- [ ] Configure Green Power Priority via RedArc app
- [ ] Test jump start assist function
- [ ] Verify BCDC LED indicates proper charging mode

### Alternator

- [ ] Install 270A alternator (Premier Power Welder HO-C28)
- [ ] Confirm alternator output → START battery+
- [ ] Confirm alternator case grounded through engine block mounting

---

## Phase 3: Controllers - Physical Installation & Main Power

### PMU24

- [ ] Mount PMU on firewall or inner fender (accessible for LED/USB diagnostics)
- [ ] Confirm PMU ground reference (Pin 25) → Engine Bay Ground Bus

### SafetyHub 150

- [ ] Mount SafetyHub 150 in passenger rear wheel well (co-located with AUX battery)
- [ ] Confirm AUX battery+ → 150A CB → SafetyHub input
- [ ] Confirm SafetyHub ground bus → chassis ground

### BODY PDU

- [ ] Verify all circuit breakers and relays functional in LR-2 unit
- [ ] Replace 24V relays (K40, K42, K53) with 12V relays ({{ tbd(70) }})
- [ ] Mount LR-2 on firewall (body side, near Firewall CONSTANT Bus)
- [ ] Confirm Firewall CONSTANT Bus → 100A CB → BODY PDU power studs
- [ ] Confirm BODY PDU ground → Firewall Stud Bus
- [ ] Build harnesses to adapt J301-J306 connectors to civilian loads ({{ tbd(69) }})
- [ ] Route heated seat dash switches to LR-2 relay control inputs (K21, K22)
- [ ] Label repurposed circuits on LR-2 enclosure

### SwitchPros RCR-Force 12

- [ ] Mount SwitchPros power module on firewall (cabin side, next to BODY PDU)
- [ ] Mount SwitchPros Ground Bus at firewall near power module
- [ ] Confirm Firewall CONSTANT Bus → 150A CB → SwitchPros power input
- [ ] Confirm SwitchPros logic ground → chassis ground at firewall
- [ ] Mount SwitchPros control panel on the center console behind the Kilduff shifter; measure the cable route and order the control cable
- [ ] Build custom 2-pin Delphi harnesses for each output (plug-and-play lighting)

---

## Phase 4: Integration & Wiring

### Firewall Bulkhead Connector

- [ ] Drill firewall hole for bulkhead connector
- [ ] Mount Deutsch HDP24-24-29 receptacle (engine side)
- [ ] Assemble Deutsch plug (cabin side)
- [ ] Crimp contacts for all 19 wires
- [ ] Install sealing plugs in unused cavities
- [ ] Verify bulkhead connector seal engagement
- [ ] Confirm Engine→Cabin pins (1, 3–6, 12, 19, 20): radio power, PMU lighting outputs, PINK IGN, 4x4/4LO indicators
- [ ] Confirm Cabin→Engine pins (7–11, 13–18): CT4 outputs, switch signals, winch control, iBooster enable
- [ ] Install ferrite chokes on radio power leads (RF mitigation)

### Ignition Signal Distribution

- [ ] Confirm PBS-I PINK IGN (cabin) → ignition signal bus bar
- [ ] Confirm ignition signal bus bar → Deutsch connector (outbound to engine bay)
- [ ] Install inline fuse on ECM ignition feed (Cummins-mandated ECM Pin 41 protection per 5504137)
- [ ] Confirm engine-bay junction → ECM 12V supply + PMU Pin 7
- [ ] Confirm bus bar taps split to: CT4, SwitchPros, Fusion Radio, BCDC
- [ ] Verify total ignition signal current within spec

### PMU Input Wiring

- [ ] Confirm ignition RUN → PMU Pin 7
- [ ] Confirm horn button → PMU In 1
- [ ] Confirm brake pedal switch → PMU In 2
- [ ] Confirm reverse signal → PMU In 3 (Turbolamik aux output)
- [ ] Confirm A/C request → PMU In 9
- [ ] Confirm CT4 SW3 (headlight status) → PMU In 7
- [ ] Confirm CT4 SW4 (high-beam status) → PMU In 5 (engine-bay tap after HDP24 pin 10)
- [ ] PMU In 4, 6, 8 — reserved for future expansion (no wiring)

### PMU Output Wiring

- [ ] Confirm HVAC blower → OUT5
- [ ] Confirm GMRS Radio → OUT6
- [ ] Confirm oil cooler fan → OUT7
- [ ] Confirm PS cooler fan → OUT8
- [ ] Confirm Dakota Digital system → OUT9
- [ ] Confirm wipers (WS-51C) → OUT11
- [ ] Confirm CT4 → OUT13
- [ ] Confirm A/C clutch → OUT17
- [ ] Confirm horn → OUT18
- [ ] Confirm STX Intercom → OUT20
- [ ] Confirm brake lights → OUT21
- [ ] Confirm reverse lights → OUT22
- [ ] Confirm LP6 DRL → OUT23
- [ ] Confirm parking/tail markers → OUT12 (via HDP24 pin 6; SwitchPros LIGHTS input tapped at firewall)
- [ ] OUT1–4, 10, 14, 15, 16 — free (no wiring); OUT19/OUT24 are the 4x4/4LO indicators; radiator fan, iBooster, and TCU relocated to the START+ Forward Distribution Bus (see below)

### PMU CAN Bus Integration

- [ ] Confirm J1939 CAN High T-tap → PMU Pin 23/24
- [ ] Confirm J1939 CAN Low T-tap → PMU Pin 36/37
- [ ] Disable PMU internal CAN termination in software
- [ ] Verify CAN bus termination resistance at ECM connector
- [ ] Configure PMU to read J1939 SPNs: 100, 110, 175, 190

### BODY PDU Circuit Wiring

- [ ] Confirm Fusion Radio memory → CB30 (CONSTANT)
- [ ] Confirm USB ports → CB48 (CONSTANT)
- [ ] Confirm WolfBox camera → CB39 (CONSTANT)
- [ ] Confirm driver heated seat → CB45 via relay K21
- [ ] Confirm passenger heated seat → CB42 via relay K22
- [ ] Confirm cargo lights → CB20
- [ ] Confirm winch control → CB43

### SafetyHub Circuit Wiring

- [ ] Confirm ARB compressor motor 1 → MIDI-1
- [ ] Confirm ARB compressor motor 2 → MIDI-2

### Solar Panel Installation

- [ ] Install Cascadia 4x4 80W panel on hood per manufacturer instructions
- [ ] Route solar wiring: hood → firewall → BCDC
- [ ] Confirm solar positive → BCDC solar input
- [ ] Confirm solar negative → chassis ground (NOT BCDC negative)
- [ ] **CRITICAL:** Verify polarity before connection — reverse polarity damages BCDC

**Optional Overvoltage Protection (cold weather):**

- [ ] Mount overvoltage relay module near BCDC
- [ ] Configure overvoltage thresholds and trip delay
- [ ] Test threshold settings before final installation

**Solar Testing:**

- [ ] Verify solar charging via BCDC LED in daylight
- [ ] Verify solar input voltage within range at operating temperature

---

## Phase 5: Testing & Programming

### PMU Programming

- [ ] Program DRL auto-off when headlights active
- [ ] Program parking/tail markers (OUT12): on with low OR high beams (In 7 OR In 5), no ignition term
- [ ] Program A/C clutch engagement logic
- [ ] Program horn activation
- [ ] Program brake light activation
- [ ] Program reverse light activation
- [ ] Program oil cooler fan from SPN 175
- [ ] Program PS cooler fan from SPN 110
- [ ] Configure sequential load startup delays
- [ ] Export/backup configuration to git repository

### PMU Testing

- [ ] Verify J1939 communication and data accuracy
- [ ] Test DRL auto-off logic
- [ ] Test parking/tail markers: on with low beams, stay on with high beams, work with the ignition off
- [ ] Test A/C clutch engagement
- [ ] Test CAN-based fan controls at threshold temps
- [ ] Test sequential load startup timing
- [ ] Verify LED diagnostics show correct states
- [ ] Verify iBooster power always on

### System Integration Testing

- [ ] Verify all PMU outputs operate correctly
- [ ] Test all BODY PDU circuits
- [ ] Test SafetyHub circuits
- [ ] Verify SwitchPros Delphi connectors and outputs
- [ ] Verify Deutsch bulkhead connector seal integrity
- [ ] Final voltage drop measurements under load (within spec)
- [ ] Final ground resistance verification (within spec)

---

## Reference Documentation

**Power Systems:**

- [Batteries][batteries] - START (Odyssey PC1500) and AUX (Dakota Lithium 135Ah) specifications
- [BCDC Alpha 50][bcdc] - DC-DC charger installation and configuration
- [Solar Charging][solar] - Cascadia 80W panel and overvoltage protection
- [START Battery Distribution][start-dist] - Driver rear wheel well connections
- [AUX Battery Distribution][aux-dist] - Passenger rear wheel well connections

**Ground Bus Bars:**

- [Engine Bay Ground Bus][engine-ground] - Blue Sea 2107 PowerBar stud assignments
- [Firewall Stud Bus][firewall-ground] - Blue Sea 2105 MaxiBus terminal assignments
- [SwitchPros Ground Bus][switchpros-ground] - Blue Sea 2105 MaxiBus terminal assignments

**PMU:**

- [PMU Overview][pmu-overview] - Product specifications
- [PMU Inputs][pmu-inputs] - Input configuration and CAN bus
- [PMU Outputs][pmu-outputs] - Output assignments and ground locations
- [PMU Programming][pmu-programming] - Logic configuration

**Distribution:**

- [BODY PDU][body-pdu] - LR-2 circuit breaker and relay assignments
- [SafetyHub 150][safetyhub] - ARB and winch fuse assignments
- [Firewall Ingress][firewall-ingress] - Deutsch HDP24-24-29 connector pinout

**External Manuals:**

- [PMU24 User Manual v101.1.5][pmu-manual]
- [BCDC Alpha 50 Installation Manual][bcdc-install]
- [Blue Sea BusBar Installation Guide][bluesea-busbar-guide]

[batteries]: ../01-power-systems/01-power-generation/01-batteries.md
[bcdc]: ../01-power-systems/01-power-generation/03-bcdc.md
[solar]: ../01-power-systems/01-power-generation/04-solar.md
[start-dist]: ../01-power-systems/02-starter-battery-distribution/index.md
[aux-dist]: ../01-power-systems/03-aux-battery-distribution/index.md
[engine-ground]: ../01-power-systems/05-grounding/01-engine-bay-ground-bus.md
[firewall-ground]: ../01-power-systems/05-grounding/02-firewall-stud-bus.md
[switchpros-ground]: ../01-power-systems/05-grounding/03-switchpros-ground-bus.md
[pmu-overview]: ../01-power-systems/04-pmu/01-pmu-overview.md
[pmu-inputs]: ../01-power-systems/04-pmu/02-pmu-inputs.md
[pmu-outputs]: ../01-power-systems/04-pmu/03-pmu-outputs.md
[pmu-programming]: ../01-power-systems/04-pmu/04-pmu-programming.md
[body-pdu]: ../01-power-systems/03-aux-battery-distribution/03-body-pdu.md
[safetyhub]: ../01-power-systems/03-aux-battery-distribution/04-safetyhub.md
[firewall-ingress]: ../01-power-systems/07-wire-routing/02-firewall-ingress.md
[pmu-manual]: https://www.ecumaster.com/files/PMU/PMU_Manual.pdf
[bcdc-install]: https://cdn.intelligencebank.com/au/share/yE9N/zJpl/NNRlJ/original/Install+Guide+BCDC+Alpha+50R+EN
[bluesea-busbar-guide]: https://www.bluesea.com/resources/108

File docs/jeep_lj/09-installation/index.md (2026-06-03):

---
hide:
  - toc
---

# Section 9: Installation & Project Management {#installation-project-management}

Physical installation planning, tracking, and validation procedures.

## Contents

- **[9.0 - TBD Tracker][tbd-tracker]** - Outstanding items and completion tracking
- **[9.1 - Power Systems Checklist][power-checklist]** - Section 1 installation tasks
- **[9.2 - Engine Systems Checklist][engine-checklist]** - Section 2 installation tasks
- **[9.3 - Purchase Tracker][purchase-tracker]** - Components to buy, sorted by cost

## Installation Resources

**Wire Routing:**

- [Section 1.7 - Wire Routing][wire-routing] - Primary power cables, firewall penetrations, routing paths, ground points

**Firewall Planning:**

- [Section 1.7.2 - Firewall Ingress][firewall-ingress] - Deutsch HDP24-24-29 connector pinout and specifications

## System Overview

Installation planning and tracking includes:

- Outstanding items tracking (TBD Tracker)
- Installation checklists organized by section
- Wire routing and bundling specifications
- Firewall penetration planning
- Testing and validation procedures

[tbd-tracker]: ../tbd-tracker.md
[power-checklist]: 01-power-systems-checklist.md
[engine-checklist]: 02-engine-systems-checklist.md
[purchase-tracker]: 03-purchase-tracker.md
[wire-routing]: ../01-power-systems/07-wire-routing/index.md
[firewall-ingress]: ../01-power-systems/07-wire-routing/02-firewall-ingress.md

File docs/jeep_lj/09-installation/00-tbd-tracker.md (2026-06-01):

---
hide:
  - toc
---

# 8.1 TBD Tracker - Outstanding Items {#tbd-tracker}

**Purpose:** Central tracking for all To-Be-Determined items across the Jeep LJ electrical system documentation.

**Last Updated:** 2026-06-01

**Total Open Items:** 50

> Count reflects the priority sections below. The Critical-Spec Verification Audit is a separate validation log (its open on-arrival/on-vehicle checks are tracked via GitHub issue [#29][i29]); items already marked ✅ Resolved are not counted.

---

## 🔴 CRITICAL (Installation Blockers)

Items that prevent build completion or system operation.

| Item | Description | File | Priority |
| :--- | :--- | :--- | :--- |
| _(None - all critical items resolved)_ | | | |

---

## HIGH PRIORITY (Needed for Final Design)

Items needed before installation begins but not system-critical.

| Item | Description | File | Priority |
| :--- | :--- | :--- | :--- |
| Dakota Digital Panel Mounting | HDPE sheet dimensions and location | [Wire Routing][wire-routing] | High |
| Turbolamik Aux: Reverse | Confirm aux output channel + pinout configured for Reverse signal → PMU In 3 | [Transmission][transmission] | High |
| Turbolamik Aux: P/N | Confirm aux output channel + pinout configured for P/N (start interlock) | [Transmission][transmission] | High |
| PBS-I Kit Order | Order Digital Guard Dawg PBS-I kit (ICM, 2 iTag fobs, Start Button + 36" harness, Programming Button, Bypass Card) | [Keyless Ignition][keyless] | High |
| WAIT-Gate Relay Part | Select SPST 30A automotive relay, NC contacts in start path (e.g. Bosch 0332019150 or Hella 4RA 003 510-04) | [Keyless Ignition][keyless] | High |
| ECM Pin 41 Inline Fuse | Add 5A inline fuse on the ignition (keyswitch) feed to ECM Pin 41 — pink wire, per Cummins Repower R2.8 Installation Guide 5504137 (Fig 2, item 3) | [Keyless Ignition][keyless] | High |
| PBS-I Module Mounting Location | Cabin under-dash position; module ~5.5"×3"×1.25"; away from heat and water (do NOT engine-bay mount) | [Keyless Ignition][keyless] | High |
| Start Button Mounting Location | Dash position within easy reach of driver (button + 36" harness included in PBS-I kit) | [Keyless Ignition][keyless] | High |
| R2.8 Turbo Inlet OD | Measure turbo inlet tube outside diameter to confirm AMOT 4261M-02 (2.8" body) fitment and select intake-side adapter | [Runaway Protection][runaway-protection] | High |
| AMOT-to-Intake Adapters | Source NPT-to-hose fittings sized to match measured turbo inlet OD | [Runaway Protection][runaway-protection] | High |
| AMOT T-Handle Mounting Location | Select dash mounting position for Midwest Control 30-144-TTL-BH-3 (reachable belted, away from accidental contact) | [Runaway Protection][runaway-protection] | High |
| AMOT Cable Firewall Grommet | Assign dedicated firewall grommet for AMOT push-pull cable pass-through (must not share with other cables) | [Runaway Protection][runaway-protection] | High |
| Catch Can Mounting Bracket Point  | Select engine bracketry attachment point for Mishimoto MMOCC-UB universal bracket | [Runaway Protection][runaway-protection] | High |
| Brake Line (caliper side) | Hybrid spec'd: 3/16" copper-nickel hardline (armored, routed inside frame rail) + DOT braided flex at axles. Order hardline + inverted-flare fittings (1/2-20 IF at MC) + spring gravel-guard armor | [Brake Booster][brake-booster] | High |
| Brake Proportioning Valve | Select adjustable proportioning valve for the rear disc circuit (iBooster has no integral proportioning); size on assembly | [Brake Booster][brake-booster] | High |

---

## 📋 MEDIUM PRIORITY (Design Optimization)

Items that improve the design but don't block installation.

| Item | Description | File | Priority |
| :--- | :--- | :--- | :--- |
| Firewall Grommet Circuits | Complete wire bundle lists | [Wire Routing][wire-routing] | Medium |
| Dash to Console Routing | Switch panels, USB, radio | [Wire Routing][wire-routing] | Medium |
| Cab to Cargo Routing | Rear lights, compressor, lockers | [Wire Routing][wire-routing] | Medium |
| Roof/Roll Bar Routing | Light bars, dome lights | [Wire Routing][wire-routing] | Medium |
| Speaker Mounting Locations | Dash end caps or kick panels | [Audio Systems][audio-systems] | Medium |
| RF Power Grommet Location | Grommet 6 location near battery for radio power | [Wire Routing][wire-routing] | Medium |
| Alternator Output Terminal Size | Terminal size for 1/0 AWG lug selection | [Alternator][alternator] | Medium |
| Alternator Voltage Regulator Set Point | Verify 14.2-14.4V for AGM batteries | [Alternator][alternator] | Medium |
| BODY PDU Metri-Pack Pinout | J301-J306 connector pinout (military TM or reverse engineering) | [BODY PDU][body-rtmr] | Medium |
| BODY PDU 12V Relay Part Numbers | Replacement part numbers for K40, K42, K53 (currently 24V coils) | [BODY PDU][body-rtmr] | Medium |
| Winch Control Wire Routing | Routing path from dash to bumper via HDP24 (~3 ft BODY PDU→dash + ~13 ft dash→contactor) | [Dashboard Controls][dash-controls]  | Medium |
| Drive Mode Switch (transmission) | Source 3-position Toyota-style switch (1.54"×0.83" cutout) once TCU selected. Verify TCU input requirements (ground-switched vs +12V switched, # of modes). | [Dashboard Controls][dash-controls]  | Medium |
| Heated Seat Switches | Source 2× Toyota-style ON/OFF switches (1.54"×0.83" cutout) for driver + passenger heated seats. Wire to BODY PDU CB45/CB42 via K21/K22 relays. | [Dashboard Controls][dash-controls]  | Medium |
| Driver-side Firewall Heavy Power Grommet | Source rubber grommet sized for ~1.5" OD bundle (3× 2/0 AWG H2 cables). New firewall penetration on driver side. | [Firewall Ingress][firewall-ingress] | High |
| Passenger-side Firewall Grommet (H1) | Source **single sealed 2-piece rubber grommet** (Steele Rubber or equivalent) sized for ~1.5" OD H1 cable bundle (~1.75" firewall hole). Cables run continuously through — no service break. Standard winch firewall pass-through per WARN install guidance. Bulkhead studs (Blue Sea 2203/2204) and Anderson SB175 were both underrated for the winch peak current. | [Firewall Ingress][firewall-ingress] | High |
| Dash Switch Cutout Layout | Mark and machine 1.54"×0.83" cutouts directly into Genright dash for winch + future switches. Decide cluster location and spacing (e.g., row of 4 beside HDX cluster). | [Dashboard Controls][dash-controls]  | Medium |
| Rear Seat Switch Mounting Location | Physical mounting location for Blue Sea 4160 push button (rear roll bar lights)  | [Dashboard Controls][dash-controls]  | Medium |
| Subwoofer Mount Locations | Mark and cut quarter panel openings for 2× JL M6-8IB (8" cutout, 4.25" depth) above wheel wells. Verify clearance from cage tubes and rear seatbelts. May need backing plate. | [Subwoofer][subwoofer] | Medium |
| MV800/8i Amp Under-Seat Mounting Plate | Fab mounting plate under driver-side rear seat with airflow gap (no fan — convection-cooled Class-D). Chassis 13.96" × 6.93", but allow **14" × 8-3/8" footprint** including connector clearance (Crutchfield figure). Verify clearance from seat slider rails. | [Amplifier][amplifier] | Medium |
| Winch Trigger Control Routing | Path for 14 AWG control wire (~13 ft) from SafetyHub ATC-1 (passenger rear wheel well) to winch contactor (front bumper) | [Recovery Systems][recovery-systems] | Medium |
| Front Air Locker Solenoid Routing | Path for 18 AWG (~12 ft) from SwitchPros OUTPUT-17 (passenger rear wheel well) to front axle solenoid - cross-cab + forward | [Air Lockers][air-lockers] | Medium |
| Radio Ground Routing | Path for 14 AWG ground wires from GMRS / Intercom (dashboard) to START battery negative (driver rear wheel well) - direct grounds required for RF noise isolation | [Firewall Ingress][firewall-ingress] | Medium |
| Programming Button Storage | Hidden but accessible location (under dash or in trunk) for PBS-I fob-learn and 4-digit-PIN emergency bypass | [Keyless Ignition][keyless] | Medium |
| PBS-I Quiescent Current | Measure or vendor-confirm standby draw to add to START battery parasitic budget  | [Keyless Ignition][keyless] | Medium |
| PBS-I Feature Programming Defaults | Confirm shipped Feature Programming defaults are acceptable before install (no DIP/jumper menu on PBS-I) | [Keyless Ignition][keyless] | Medium |
| Axle Brake Flex Hose Length | DOT (FMVSS 106) braided-stainless extended-length flex at each axle — length blocked on axle + suspension selection (Section 10); size to full droop, do not cut until ride height fixed | [Brake Booster][brake-booster] | Medium |

---

## 📝 LOW PRIORITY (Optional/Aesthetic)

Items that can be determined during build.

| Item | Description | File | Priority |
| :--- | :--- | :--- | :--- |
| BIM Module Current Draw | Current draw for BIM-01-2-J1939, GPS-50-2, BIM-22-3, BIM-17-2 (powered via BIM cable) | [Gauge Cluster][gauge-cluster] | Low |
| LED4Life Wire Colors | Confirm pod wire colors match MLC-RW pinout before install | [Footwell Lights][footwell-lights] | Low |

---

## 🔍 VERIFICATION NEEDED

Items that are estimated and need actual product specs to confirm.

| Item | Description | File | Action Needed |
| :--- | :--- | :--- | :--- |
| Grid Heater Current | Design value 80A - verify via element resistance measurement during installation (~0.15Ω @ 12V) | [Grid Heater][grid-heater] | Measure resistance |
| ECM Lamp-Driver Sink Margin | WAIT-gate relay coil (~150 mA) sits in parallel with the dash WAIT lamp on ECM Pin 35's sink driver. Confirm total sink (lamp ~500 mA + coil) is within the ECM lamp-driver rating; if marginal, drive relay from the lamp keyswitch side or use a higher-impedance relay. (Pin 35 active-low polarity itself is confirmed — see Recently Resolved.) | [Keyless Ignition][keyless] | Verify at install |

---

## 🚙 DRIVETRAIN (Section 10)

Mechanical drivetrain specifications, tracked separately from the electrical build. Most items need component selection before parts ordering.

| Item | Description | File | Priority |
| :--- | :--- | :--- | :--- |
| TCU Brake Switch Routing | Brake pedal switch already feeds PMU In 2 via HDP24 pin 13. Decide: shared signal tap or dedicated wire to TCU? | [Harness Inventory][harness-inventory] | Medium |
| Transmission Pilot Bearing | If required by flywheel/crank combination | [Transmission][transmission] | Medium |
| Transfer Case Specs | JK NVG241 (2.72:1) — input spline (per 8HP70 adapter), output type, fluid type & capacity | [Transfer Case][transfer-case] | Medium |
| Front Driveshaft Specs | Custom (Tom Woods) decided — measure length at final ride height & order | [Driveshafts][driveshafts] | Medium |
| Rear Driveshaft Specs | Custom (Tom Woods) decided — measure length at final ride height & order | [Driveshafts][driveshafts] | Medium |
| Front Axle Gearing & Manufacturer | Ratio and axle housing manufacturer | [Front Axle][front-axle] | Medium |
| Rear Axle Gearing & Locker | Ratio, manufacturer, and locker type | [Rear Axle][rear-axle] | Medium |
| Front Suspension Components | Coil rate, bypass valving, control arms, track bar, sway bar | [Suspension][suspension] | Medium |
| Rear Suspension Components | Coil rate, bypass valving, control arms, track bar, sway bar | [Suspension][suspension] | Medium |
| Steering Pump Specs | Kit pump PK40JP2-FH is Jeep 4.0L-only — source Cummins R2.8 PSC pump/bracket; flow/pressure/drive TBD | [Steering][steering] | Medium |
| Steering Ram Specs | PSC SC2227K1 (2.75×8 double-ended, FHK400TJ, 40"+ confirmed) on Artec D60 mount cut to D44 + Busted Knuckle stops; mount P/N + D44 stroke length TBD | [Steering][steering] | Medium |
| Steering Cooler Fan (electrical)  | On PMU Out 8 (~15A, 180°F inline thermostat); confirm actual Mishimoto fan draw fits budget | [Steering][steering] | Medium |
| Suspension Geometry | Departure and breakover angles (calculated from chosen suspension) | [Suspension][suspension] | Low |
| Steering Reservoir & Fluid | Fluid = PSC/SWEPCO 715; remote reservoir (in pump kit) model/location + system fill qty TBD  | [Steering][steering] | Low |

---

## RECENTLY RESOLVED

Items completed since last update.

| Item | Resolution | Date |
| :--- | :--- | :--- |
| ECM Pin 35 WAIT Polarity & Cummins Wiring Doc # | **Confirmed via Cummins Repower R2.8 CM2220 R101B Installation Guide (Bulletin 5504137, Jan 2018), §2 pp. 2-19→2-24.** Circuit Wiring table: Wait-To-Start = Yellow, ECM pin 35; Keyswitch = Pink, pin 41 with 5A inline fuse. Guide states lamps are fed +12V from the keyswitch with the ECM "providing a path to ground via a sink circuit" → Pin 35 is **active-low**, validating the WAIT-gate relay logic (relay taps Pin 35 directly, independent of HDX cluster-input polarity). Full schematic = separate Wiring Diagram Bulletin 5467560 (QSOL). The unverified "document 0042728" reference was removed from the keyless doc. Residual ECM lamp-driver sink-margin check moved to Verification. | 2026-06-01 |
| Amplifier Selection (MV800/8i) | **Architecture change:** Swapped Fusion Apollo MS-AP61800 (6-ch, 1800W) → **JL Audio MV800/8i** (8-ch, 800W, integrated DSP, part 010-03339-00). 8 channels allow Sub A on Ch 1+2 bridged @ 4Ω (200W RMS, exact match to M6-8IB rating) and Sub B on Ch 3+4 bridged @ 4Ω (200W RMS), with Ch 5-8 driving the 4 cabin speakers @ 75W RMS each. Eliminates series-wired sub compromise. Onboard DSP (TüN software) replaces external crossover/EQ tuning. 80A internal fuse (vs 125A on Fusion). Power feed unchanged: 4 AWG, direct from AUX battery+ via Blue Sea 187-100A CB. | 2026-06-01 |
| MV800/8i Idle Current & Min Bridged Impedance | Manual (MV800/8i_MAN_071519) confirms: standby current **2.4 mA** (negligible parasitic — no impact on AUX battery budget); minimum impedance **4Ω bridged / 2Ω unbridged**; required cooling clearance **1" (2.5 cm) above shell** when enclosed; manual recommends fuse value of 80A, matching internal fuse. | 2026-06-01 |
| Amp Tuning Interface (VXi-BTC vs M-DRC-50) | Selected **VXi-BTC** (010-13543-00) only — Bluetooth LE 4.2, 33 ft range, JLid-powered (50 mA from amp's bus, no separate wiring). MV800/8i has single JLid-COMM port — only one accessory at a time; MVi-HUB doesn't add ports (it's for multi-amp networking). M-DRC-50 dash preset selector deferred: head unit already handles volume/source, multi-DSP-preset switching isn't a daily-use need yet, and Bluetooth tuning is lower-friction than crawling under the rear seat for the amp's USB port. | 2026-06-01 |
| Subwoofer Wiring (per-sub bridged) | **Architecture change:** Each M6-8IB now runs on its own bridged channel pair on the MV800/8i @ 4Ω (200W RMS exact match), instead of series-wired pair on bridged Ch1+2 @ 8Ω (~145W per sub). Independent per-sub gain/EQ/delay via amp DSP. Total sub output goes from ~290W → 400W. Wiring simplified: no inter-sub series jumper, each sub returns directly to its own bridged pair. | 2026-06-01 |
| Solar Panel Wire Gauge | 10 AWG minimum (for 2.23A Isc with safety margin) - already specified in solar generation doc | 2026-05-30 |
| SwitchPros Power Module Location | **Architecture change:** Moved from passenger rear wheel well to firewall (cabin side, passenger area). Output fan-out is ~58% forward — placing module near loads minimizes total output wire. SwitchPros Ground Bus moves with controller. Input is 2 AWG, ~2 ft from Firewall CONSTANT Bus. Control cable shortens from 10.5 ft to ~5 ft. | 2026-05-30 |
| AUX Battery CONSTANT Bus #1 (rear) | **Architecture change:** Removed. With SwitchPros, BODY PDU, and Fusion Amp moved to firewall distribution, only 2 CB-protected feeds + 2 direct connections leave the AUX battery. Replaced rear CONSTANT bus with 4 stacked ring lugs on battery + 2 inline CBs (300A master + 150A SafetyHub) on a wheel well bracket. | 2026-05-30 |
| Firewall CONSTANT Bus (new) | **Architecture change:** Added Blue Sea 2105 MaxiBus (250A) on firewall (passenger cabin side). Fed by 2/0 AWG forward feed from AUX battery via 300A master CB. Feeds SwitchPros (150A CB), BODY PDU (100A CB), Fusion Amp (100A CB). Places distribution near loads; collapses 3 forward feeds into 1 heavy cable through cabin trunk. | 2026-05-30 |
| HDP24 Connector Upsize | Upsized main firewall connector from HDP24-24-21 to HDP24-24-29 (29 size-16 contacts, 18 used after non-SP additions + 11 future headroom). Same shell size, same firewall hole. | 2026-05-30 |
| Dedicated SwitchPros Firewall Bulkhead | Added second firewall connector (HDP24-18-14, 14 size-16 contacts, 1.25" hole) for SwitchPros forward-going outputs only. Keeps SP harness fully Delphi-native + modular, isolates PWM-capable lighting from signal wires, and reserves 8 spare pins for future SP additions (e.g., ditch/roof if A-pillar gets crowded). | 2026-05-30 |
| SwitchPros Forward-Load Ground Strategy | Each forward SP output uses 2 pins on the dedicated SP bulkhead (power out + ground return). Load grounds return to SwitchPros Ground Bus at firewall cabin side via dedicated bulkhead pins. Clean SP-native architecture; no reliance on chassis ground at forward loads. | 2026-05-30 |
| Winch Trigger Power Source | Reallocated from SafetyHub ATC-1 (15A, ~13 ft from rear) to BODY PDU CB43 (10A, ~3 ft to dash). Properly sized for 3A trigger current. Saves ~10 ft of 14 AWG wire and frees SafetyHub ATC-1 slot for future use. | 2026-05-30 |
| Winch Dash Switch Part | Selected **CH4X4-TOY-D-WINIO** ($24): dual-momentary push switch, Toyota OEM cutout (1.54"×0.83"), dual-color LED. Two independent 3A circuits feed contactor IN/OUT triggers directly — matches WARN ZEON 10-S contactor architecture (contactor handles polarity internally). Safer than single rocker (can't activate both directions simultaneously). | 2026-05-30 |
| Dash Switch Cutout Standard | All custom dash switches use **Toyota OEM cutout: 1.54"×0.83" (39mm×21mm)**. Wide vendor selection (CH4X4, STEDI, sPOD), pre-cut multi-position fascias available. Replaces ad-hoc Carling Contura cutouts. | 2026-05-30 |
| Dash Switch Mounting Approach | Cutouts machined directly into existing **Genright aftermarket dash** — no separate fascia panel. Switches snap-lock into their own cutouts. | 2026-05-30 |
| H1 Passenger Rear Power Trunk Routing | **Path: inside floor board / side wall (passenger side).** Passenger rear wheel well → up rear quarter sill → forward along inside floor/wall → A-pillar → firewall (CONSTANT bus). Fully inside body. Includes forward feed (2/0 AWG) and winch power/ground (2× 1/0 AWG); winch cables continue past firewall to front bumper. (Originally tracked as separate H1 forward feed + H4 winch feed routings.) | 2026-05-30 |
| H2 START → Engine Bay Routing | **Path: inside floor board / side wall (driver side).** Driver rear wheel well → up rear quarter sill → forward along inside floor/wall → driver A-pillar → driver-side firewall grommet → engine bay. 3× 2/0 AWG bundled (~1.5" OD). New driver-side firewall grommet required. | 2026-05-30 |
| H3 BCDC Cross-Cab Routing | **Path: under the rear bench seat cushion.** Driver rear wheel well → straight cross-cab under bench → passenger rear wheel well. Short, dry, physically protected by bench above and floor pan below. Independent of cabin trunk runs. | 2026-05-30 |
| Transmission Shifter Type | Kilduff 8HP70 / 8 Speed ZF Shifter for Swaps — factory 8HP70 connector mates to Turbolamik TCU on mechatronic. Center console mount. Documented as H8 in harness inventory. | 2026-05-30 |
| H8 Kilduff Shifter → TCU Harness | Documented: shifter (center console) → trans tunnel down → TCU on 8HP70 mechatronic. Kilduff-supplied harness, factory 8HP70 connector, ~3-5 ft. No firewall penetration. (Was H10 prior to 2026-05-31 renumber.) | 2026-05-30 |
| H9 TCU → Engine Bay Harness | Documented: TCU power (PMU OUT16 14 AWG), J1939 CAN tap, Aux Reverse (PMU In 3), Aux P/N (starter relay coil), TCU ground (engine bay ground bus). All endpoints in engine bay. (Was H11 prior to 2026-05-31 renumber.) | 2026-05-30 |
| H1 Power Trunk Merge (old H1 + old H4)  | Merged old H1 (AUX forward feed) + old H4 (winch feed) into single **H1 Passenger Rear Power Trunk** — share entire passenger-side path. Fabricated as 3-cable bundle (1× 2/0 + 2× 1/0 AWG), ~1.5" OD. | 2026-05-30 |
| Subwoofer Configuration | **Architecture change:** Swapped single JL M7-12IB (12", 600W, 14" diameter, 7.94" mounting depth) → 2× JL M6-8IB (8", 200W each, ~9.5" diameter, 4.25" depth), wired **in series (8Ω) bridged to Fusion Ch1+2**. Symmetric L/R mounting in rear quarter panels above wheel wells. Tradeoff: total sub power drops from 580W → ~290W, but 12" depth made LJ panel mounting impractical. Series wiring keeps amp safe (8Ω is above 4Ω bridged minimum; parallel @ 2Ω would damage amp). | 2026-05-31 |
| Fusion Amp Mounting Relocation | **Architecture change:** Moved Fusion Apollo MS-AP61800 from behind-dash firewall → **under driver-side rear seat**. Power feed now 4 AWG ~3-4 ft direct from AUX battery+ via 100A inline CB (was ~3 ft from Firewall CONSTANT Bus via 100A CB). Ground also ~3-4 ft (was ~8-10 ft). RCAs + remote turn-on grow to ~10-12 ft through trans tunnel — requires high-quality shielded RCA. Removes 100A→Fusion CB from firewall bank (now 2 CBs there: SP + BODY only). Adds 5th stacked lug + 3rd inline CB at AUX battery+ bracket. | 2026-05-31 |
| H5 Rear Cabin Trunk Merge (old H6 + old H7) | Merged old H6 (SwitchPros rear) + old H7 (PMU rear lighting) into single **H5 Rear Cabin Trunk Bundle** — share cabin trunk path. ~10 conductors with multi-pin breakout (Deutsch DT15 or AMP CPC ~15-pin) at rear cargo bulkhead. | 2026-05-30 |
| H1 Firewall Pass-Through Hardware | **Single sealed 2-piece rubber grommet** (Steele Rubber or equivalent), ~1.75" hole, ~1.5" cable bundle OD. Cables continuous through firewall — no service break. WARN's documented standard for winch firewall pass-through. Bulkhead studs (Blue Sea 2203/2204, Cole Hersee 46211) max at 250A continuous and are underrated for winch peaks (400A). Anderson SB175 also undersized. ~$5-15. | 2026-05-30 |
| Harness Catalog Renumber | Renumbered the catalog to a single H1–H9 sequence and dropped compound names ("H1/4", "H6/7"). New mapping: H1 (was H1/4), H2 unchanged, H3 unchanged, H4 (was H5 SwitchPros front), H5 (was H6/7 rear cabin trunk), H6 (was H8 ARB compressor), H7 (was H9 winch trigger), H8 (was H10 Kilduff shifter), H9 (was H11 TCU→engine bay). Added bundle interference assessment confirming H1 (power-only) and H5 (switched DC only, no PWM/CAN/audio/analog) are safe to bundle. | 2026-05-31 |
| Horn Relay Specs | None required - PMU OUT 18 switches PIAA horns directly, no external relay | 2026-05-25 |
| Horn Load | 5.4A (PIAA 2.7A × 2) | 2026-05-25 |
| Horn Circuit Protection | None required - PMU OUT 18 has integrated electronic overcurrent/thermal protection | 2026-05-25 |
| Horn Button Type | Momentary (steering wheel button → PMU In 1) | 2026-05-25 |
| WolfBox License Plate | Resolved - rear camera mounts above license plate; integration with plate lights not required | 2026-05-25 |
| 3-Position Selector Switch | Obsolete entry - no such switch in current design (SwitchPros outputs used directly) | 2026-05-25 |
| Winch 3-Position Switch | Obsolete entry - winch uses BODY PDU-fed center-off momentary rocker, not SwitchPros | 2026-05-25 |
| Cummins Harness Wire Count | Use factory bulkhead connector as-is; no per-wire enumeration needed | 2026-05-25 |
| R2.8 ECM A/C Pin (source sync)| Source file `02-engine-systems/03-hvac.md` updated to remove stale TBD; matches 2025-11-28 tracker resolution | 2026-05-25 |
| ADU7 Supplemental Display | Removed from build - PMU OUT14 freed, An 5-8 returned to Available, boost/EGT/AUX-voltage sensors no longer required | 2026-05-25 |
| Ham Radio | Removed from build - PMU OUT12 freed, firewall pin 2 freed, radio ground run eliminated | 2026-05-25 |
| R2.8 ECM A/C Request Input | CM2220 has no A/C request input - not applicable | 2025-11-28 |
| Fusion Amp Mounting | Back firewall in cab | 2025-11-28 |
| STX Intercom Mounting | Dash/behind dash | 2025-11-28 |
| WolfBox Rear Camera Mount | Above license plate | 2025-11-28 |
| WolfBox Cable Length | ~11 ft (windshield → A-pillar → rear center) | 2025-11-28 |
| GMRS Antenna Location | Driver A-pillar (~6 ft from dash) | 2025-11-28 |
| Ham Antenna Location | Passenger A-pillar (~4 ft to dash) | 2025-11-28 |
| Turn Signal Mounting | Front fenders | 2025-11-28 |
| Radiator Fan Wire Length | 6 ft (PMU to fan) | 2025-11-28 |
| Speaker IPX Rating | IP67 | 2025-11-28 |
| Hi-Lift Jack Mount | Not needed | 2025-11-28 |
| Recovery Board Storage | Not needed | 2025-11-28 |
| SwitchPros Control Cable | 10.5 ft standard cable (passenger rear wheel well to dash) | 2025-11-28 |
| CT4 Power Source | PMU Out 13 (15A CONSTANT) - ~9A actual load, allows hazards when ignition off | 2025-11-26 |
| Rear Seat Switch | Blue Sea 4160 (10A latching), 16 AWG, parallel with SwitchPros OUTPUT-4 | 2025-11-26 |
| Door Switch Routing | Factory plunger switches retained, 18 AWG to SwitchPros TRIGGER-1 | 2025-11-26 |
| Turn Signal Distribution | CT4 splice to front turn, Maxbilt rear, RTL-S amber (~0.9A per side) | 2025-11-26 |
| Brake Light Distribution | PMU Out 21 splice to Maxbilt, RTL-S brake (~4.5A total) | 2025-11-26 |
| Running Light Distribution | PMU Out 23 splice to LP6 DRL, Maxbilt marker, RTL-S running (~2.6A total) | 2025-11-26 |
| RTL-S Wiring Configuration | 4-wire: black ground, red running (PMU Out 23), yellow brake (OEM), blue work (PMU Out 23); 2-wire: yellow/blue turn (SwitchPros OUTPUT-7) | 2025-11-25 |
| Cargo Light Power Source | BODY PDU CB20 (10A) with SPST switch on rear wheel well top; lights flush mounted in rear wheel well | 2025-11-26 |
| Rear Work Lights Position | Above license plate, verified clear of WolfBox rear camera | 2025-11-26 |
| Reverse Lights Mount | Rear armor brackets | 2025-11-26 |
| Cargo Light Switch | Blue Sea 4160 (10A latching, 3/4" mount) on rear wheel well top | 2025-11-26 |
| Roof Lights OUTPUT-1 Overload | Corrected XL Sport specs (2.2A/pod, not 6A); 8 pods = 18A on single OUTPUT-1 (51% utilization) | 2025-11-25 |
| Fusion Amp Current Draw | 6-ch MS-AP61800: 1.32A idle, 78A max, 125A electronic fuse | 2025-11-24 |
| Fusion Amp CB Selection | Blue Sea 187-100A breaker, 4 AWG power/ground wiring, mount at CONSTANT bus | 2025-11-24 |
| WolfBox Model | G900 TriPro selected | 2025-11-24 |
| WolfBox Power Source | BODY PDU F5 (10A, CONSTANT) | 2025-11-24 |
| WolfBox Mounting | Windshield mount (replaces factory rearview mirror) | 2025-11-24 |
| WolfBox Ground | Dash ground point | 2025-11-24 |
| S8 10" Amber Part Number | 701014 - Baja Designs S8 10" Wide Cornering Amber | 2025-11-23 |
| Cargo Area Lighting Type | BD Squadron Sport Flood (2 pods, 3,000 lumens total) | 2025-11-23 |
| Cargo Area Light Quantity | 2 BD Squadron Sport pods | 2025-11-23 |
| RGB Controller | BD RGB Whip has integrated controller | 2025-11-23 |
| iBooster Mounting Bolt Torque | 16.5 Nm (12 ft-lb) - 2x nyloc nuts, 13mm per Tesla Model Y service manual | 2025-11-23 |
| Grommet Locations | Determined during installation (general areas documented) | 2025-11-22 |
| Firewall Ground Stud Location | Determined during installation | 2025-11-22 |
| Wiper Controller Mounting | Dash-mounted (WS-51C is integrated switch/controller) | 2025-11-22 |
| Radiator Fan Mounting | Radiator shroud (documented in fan motor specs) | 2025-11-22 |
| Heated Seat Load | Verified with vendor: 5A peak, 2A sustained per seat (not 15A) | 2025-11-22 |
| SafetyHub Location | Consolidated to single SafetyHub 150 on AUX battery (ARB compressor, winch trigger); communications moved to PMU | 2025-11-21 |
| AUX Battery CONSTANT Bus CB | Resolved by connecting SafetyHub to CONSTANT bus - each load (SwitchPros, SafetyHub, BODY PDU) has individual CB protection | 2025-11-22 |
| Wire Routing Protection | Added comprehensive wire protection standards section covering split loom, heat sleeve, p-clamps, grommets by location | 2025-11-22 |
| BCDC Temperature Sensor | Documented installation location (side of AUX battery case), sensor specs, and installation procedure | 2025-11-22 |
| BCDC Wire Lengths | Updated to 4 AWG @ 5-6 ft for 50A BCDC (0.94% voltage drop) | 2025-11-22 |
| PMU PWM Frequency | PMU24 supports 4-400 Hz on 25A outputs; GM brushless fan requires 100 Hz - compatible. Note: GM fans use inverted duty cycle. | 2025-11-22 |
| Radiator Fan Distance | 6 ft estimated (firewall to radiator), 4 AWG wire sizing confirmed (3.2% drop @ 53A full speed) | 2025-11-21 |
| Radiator Fan Load | GM Camaro fan 53A @ 100% PWM (variable speed: 16A @ 30%, 32A @ 60%, 53A @ 100%) | 2025-11-21 |
| Radiator Fan Protection | PMU OUT2+3+4 has integrated overcurrent/thermal protection, no external CB needed | 2025-11-21 |
| PMU iBooster Thermal | Resolved via non-adjacent combining: OUT1+10 (46A @ 40°C) vs OUT5+6 adjacent (32A @ 40°C) | 2025-11-21 |
| Grid Heater Current | Design value 80A (moved to Verification for field measurement) | 2025-11-21 |
| BCDC Temperature Sensor | Included with BCDC unit (2-pin reversible, moved to High Priority for install documentation) | 2025-11-21 |
| BODY PDU Model | Bussmann LR-2 (301-1C-C-R1) | 2025-11-18 |
| BODY PDU Ground | Firewall Stud Bus Terminal 3 (14 AWG) - relay coil/logic reference only (~3A); high-side switching means loads ground separately | 2025-11-28 |
| Alternator Part Number | Premier Power Welder HO-C28 | 2025-11-18 |

---

## Summary by Priority

| Priority | Count  |
| :--- | :----- |
| 🔴 Critical | 0 |
| High | 15 |
| 📋 Medium | 19 |
| 📝 Low | 2 |
| 🔍 Verify | 2 |
| 🚙 Drivetrain | 12 |
| **TOTAL** | **50** |

## Related Documentation

- [Section 1 Installation Checklist][section-1-install] - Power systems installation guide
- [Section 1.7 Wire Routing][wire-routing] - Wire routing organized by location

[gauge-cluster]: ../02-engine-systems/09-gauge-cluster/index.md
[radiator-fan]: ../02-engine-systems/06-radiator-fan.md
[wire-routing]: ../01-power-systems/07-wire-routing/index.md
[switchpros]: ../05-control-interfaces/02-switchpros-sp1200.md
[dash-controls]: ../05-control-interfaces/05-dashboard-controls.md
[audio-systems]: ../06-audio-systems/index.md
[communication]: ../07-communication-systems/index.md
[turn-signals]: ../03-lighting-systems/03-turn-signals.md
[offroad-lighting]: ../04-offroad-lighting/index.md
[cargo-lights]: ../04-offroad-lighting/07-cargo-lights.md
[chase-light]: ../04-offroad-lighting/04-chase-lights.md
[recovery-systems]: ../08-exterior-systems/01-winch.md
[body-rtmr]: ../01-power-systems/03-aux-battery-distribution/03-body-pdu.md
[section-1-install]: 01-power-systems-checklist.md
[grid-heater]: ../02-engine-systems/07-grid-heater.md
[alternator]: ../01-power-systems/01-power-generation/02-alternator.md
[hvac]: ../02-engine-systems/03-hvac.md
[ct4]: ../05-control-interfaces/03-command-touch-ct4.md
[roof-lights]: ../04-offroad-lighting/03-roof-lights.md
[rear-lights]: ../04-offroad-lighting/08-rear-lights.md
[footwell-lights]: ../04-offroad-lighting/09-footwell-lights.md
[transmission]: ../10-drivetrain/01-transmission.md
[transfer-case]: ../10-drivetrain/02-transfer-case.md
[driveshafts]: ../10-drivetrain/03-driveshafts.md
[front-axle]: ../10-drivetrain/04-front-axle.md
[rear-axle]: ../10-drivetrain/05-rear-axle.md
[suspension]: ../10-drivetrain/06-suspension.md
[steering]: ../10-drivetrain/07-steering.md
[i29]: https://github.com/sob/drawings/issues/29
[constant-bus]: ../01-power-systems/03-aux-battery-distribution/02-constant-bus.md
[starter-doc]: ../02-engine-systems/01-starter.md
[keyless]: ../05-control-interfaces/06-keyless-ignition.md
[pmu-programming]: ../01-power-systems/04-pmu/04-pmu-programming.md
[firewall-ingress]: ../01-power-systems/07-wire-routing/02-firewall-ingress.md
[runaway-protection]: ../02-engine-systems/11-runaway-protection.md
[brake-booster]: ../02-engine-systems/02-brake-booster.md
[air-lockers]: ../08-exterior-systems/03-air-lockers.md
[firewall-bus]: ../01-power-systems/03-aux-battery-distribution/02-constant-bus.md
[harness-inventory]: ../01-power-systems/07-wire-routing/03-harness-inventory.md
[subwoofer]: ../06-audio-systems/04-subwoofer.md
[amplifier]: ../06-audio-systems/02-amplifier.md

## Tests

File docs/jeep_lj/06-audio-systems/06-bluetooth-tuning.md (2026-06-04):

---
hide:
  - toc
tags:
  - product-details
  - audio-systems
  - jl-audio
---

# 6.6 Bluetooth Tuning (VXi-BTC) {#bluetooth-tuning}

JLid Bluetooth communicator for wireless TüN configuration of the MV800/8i — lets DSP tuning be done from a phone or tablet without crawling under the rear seat to plug a laptop into the amp's USB port.

/// html | div.product-info
**Type:** JLid Bluetooth Communicator (control only — no audio streaming)

**Model:** VXi-BTC

**Part Number:** 010-13543-00

**Manufacturer:** JL Audio (Garmin)

**Product Page:** [JL Audio VXi-BTC][product-link]

**Manual:** [JLid Bluetooth Communicator Connection Guide][manual-link]

**Mounting:** Clip-mounted in cabin near amplifier (under rear seat area), non-metallic surface preferred

**Power Source:** JLid bus from MV800/8i (no separate power wiring)

///

## Specifications

All figures from the VXi-BTC Connection Guide.[^vxi-btc-manual]

| Spec | Value |
| :--- | ---: |
| Bluetooth Topology | LE (Low Energy) |
| Bluetooth Core Version | 4.2 |
| Connection Range | Up to 33 ft / 10 m |
| Host Interface | Proprietary JLid protocol |
| Input Operating Voltage | 5 VDC |
| Current Draw | 50 mA max (~0.25 W from JLid bus) |
| Streaming Audio | **No** — control interface only |
| Included Cable | CAT5e, 6.5 ft / 2 m |
| Included Mount | Snap-fit clip + 2 mounting screws |
| Pairing Capacity |  Multiple devices may be paired; 1 active at a time |

[^vxi-btc-manual]: JL Audio JLid Bluetooth Communicator Connection Guide (`VXi-BTC_MAN_050718`), pp. 1–2. Manual mirror used: customsounds.com.

## Function

The VXi-BTC is a **tuning interface only** — it does not stream music. Use cases on this build:

- Adjust DSP crossover/EQ/delay on the [MV800/8i amp][amplifier] while seated at the driver's seat, with the engine running and music playing
- Save/load TüN project files from a phone or tablet
- Switch between saved DSP presets without a physical preset selector (no [M-DRC-50][m-drc-50-skipped] in this build — see Design Decisions below)

The amp's USB-A/B port remains the fallback for laptop tuning sessions.

## Compatible Apps

| App | Platforms | Use Case |
| :--- | :--- | :--- |
| TüN Mobile | iPad, Android tablet | Full-featured tuning UI (preferred) |
| TüN Express | iPhone, iPad, Android phone/tablet | Streamlined — quick adjustments + preset switching |

Both apps are free on the App Store and Google Play.

## Wiring

| Connection | Wire | Source | Notes |
| :--- | :----- | :--- | :--- |
| JLid (data + 5V) | CAT5e  | MV800/8i JLid-COMM (RJ45) | Included 6.5 ft cable; ~3-4 ft used (BTC near amp) |

The VXi-BTC draws its power from the JLid bus — no separate +12 V or ground wiring needed.

!!! warning "Single JLid Port Constraint"
    The MV800/8i has **one JLid-COMM port**. The VXi-BTC occupies it. An M-DRC-50 preset-selector knob cannot coexist on the same amp without manual cable swapping (the MVi-HUB does not add additional accessory ports — it only adds amp-network ports). If a dash preset switch becomes a daily-use need, plan a swap procedure or revisit the architecture.

## Mounting Location

**Clip-mounted under the rear seat near the [MV800/8i amplifier][amplifier]:**

- Cable run: ~3-4 ft from amp's JLid-COMM port to BTC location (included 6.5 ft CAT5e has slack)
- Surface: prefer non-metallic mounting surface — the manual flags **"avoid mounting directly to large metal surfaces or to wire harnesses"** for RF performance. Mount to the trans tunnel cover, a fiberglass surface, or a fabricated standoff bracket above the amp.
- Status LED must remain visible for pairing/troubleshooting
- BT LE 33 ft range covers the driver's seat from a rear-seat mount with margin

## Pairing Procedure (initial setup)

1. Power the amp (key on); BTC LED ring initializes, then flashes blue (Open Visibility)
2. On phone/tablet: launch TüN Mobile or TüN Express, open **Select/Rename Device**
3. Pick `VXi (BT)` from the list, accept Bluetooth Pairing Request
4. BTC LED ring goes solid blue → solid green = active connection
5. Continue through TüN amp configuration prompts

The amp + BTC pair stays remembered; subsequent connects only need step 1-3.

## LED Status Reference

| LED State | Meaning |
| :--- | :--- |
| Flashing blue  | Open Visibility (pairable by any device) |
| Solid blue | Paired but not actively connected |
| Solid green | Active TüN connection in progress |
| Flashing green | Restricted Visibility (only previously paired devices can connect) |

Press-and-hold the LED button 10 sec → Factory Reset (wipes paired-device list).

## Design Decisions

**M-DRC-50 deferred.** The build started with only the VXi-BTC because:

- The MV800/8i exposes a single JLid port — only one accessory at a time without manual swapping
- The Fusion MS-RA670 head unit already provides volume, source switching, and zone fader/balance from the dash
- DSP tuning sessions are occasional (post-install, after speaker break-in, after seasonal soft-top vs hard-top changes); a Bluetooth link from a phone is the lower-friction tool for that frequency
- DSP preset switching from the dash is not yet a daily-use need. If multi-preset switching (e.g., "Top Up / Top Down / Quiet") becomes valuable, revisit by either (a) swapping in an M-DRC-50 with a swap-cable procedure, or (b) using TüN Express's preset switcher on a phone-as-remote (mounted to the dash via vent clip).

## Outstanding Items

{{ tbds() }}

## Build Tasks

- [ ] Decide BTC mounting surface — trans-tunnel cover vs near-amp standoff vs A-pillar/under-dash (whatever balances RF clearance with status-LED visibility)
- [ ] Source VXi-BTC product image (`docs/jeep_lj/images/jl-audio-vxi-btc.jpg`)

## Related Documentation

- [Audio Systems Overview][audio-overview]
- [Amplifier (MV800/8i)][amplifier] — the JLid host
- [Head Unit (MS-RA670)][head-unit] — primary daily control surface (volume, source, fader)

[audio-overview]: index.md
[amplifier]: 02-amplifier.md
[head-unit]: 01-head-unit.md
[m-drc-50-skipped]: #design-decisions
[product-link]: https://www.garmin.com/en-US/p/1706181/
[manual-link]: https://www.customsounds.com/uploads/docs/05d842e4d5097179b506cbd8024db62dbbca16ab.pdf

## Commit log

2026-06-01 docs(lj): renumber harness catalog to single H1-H9 sequence
    Drops compound names ("H1/4", "H6/7") in favor of a clean H1-H9
    sequence after the May 2026 H1+H4 and H6+H7 merges. Adds a Bundle
    Interference Assessment confirming the merged bundles carry no
    PWM/CAN/audio/analog signals, so power-only H1 and switched-DC H5
    are safe to bundle. Updates the wire-routing index prose and the
    TBD tracker (active grommet entry + Recently Resolved log) to the
    new numbering.
2026-06-01 docs(lj): renumber harness catalog to single H1-H9 sequence (#32)
    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
2026-06-01 docs(lj): swap to JL Audio MV800/8i amp + per-sub bridged subs + VXi-BTC (#33)
    Replace Fusion Apollo MS-AP61800 (6-ch, 1800W) with JL Audio MV800/8i
    (8-ch, 800W, integrated DSP, part 010-03339-00). Each M6-8IB now runs
    on its own dedicated bridged channel pair @ 4Ω (200W RMS exact match
    to sub rating) instead of series-wired pair @ 8Ω. Add VXi-BTC JLid
    Bluetooth communicator (010-13543-00) as primary tuning interface;
    M-DRC-50 preset selector deferred — only one accessory fits the amp's
    single JLid-COMM port, and the MVi-HUB doesn't add accessory ports.
    All specs cited from the MV800/8i (MV800/8i_MAN_071519) and VXi-BTC
    (VXi-BTC_MAN_050718) connection guides. Changes propagate through A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
2026-06-01 docs(lj): clean up tub map - constant bus loads + H1 rename (#34)
    Removes Dakota HDX, CT4 panel, gauges, etc. from the firewall dashboard
    label since they're PMU-fed, not on the AUX CONSTANT bus. Renames H1/4
    harness label to H1 to match the renumbered single H1-H9 catalog, and
    tightens layout of the CONSTANT bus, CBs, and firewall penetration legend.
2026-06-01 docs(lj): spec caliper-side brake plumbing as hybrid hardline + axle flex (#38)
    * docs(lj): spec caliper-side brake plumbing as hybrid hardline + axle flex
    Adds the high-pressure MC-to-caliper plumbing spec (previously a
    placeholder) to the brake booster doc:
    - Chassis runs: 3/16" copper-nickel hardline (45 deg double flare,
    1/2-20 IF at MC), armored with stainless gravel-guard, routed inside
    the frame rail
    - Axle ends: DOT/FMVSS 106 braided-stainless extended flex, length
    blocked on axle + suspension selection
    - Bulkhead fittings at axles; adjustable proportioning valve on the
    rear circuit (iBooster has no integral proportioning)
    - Documents full-PTFE-throughout as an alternative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
2026-06-01 docs(lj): audit keyless ignition section — consistency + citations (#36)
    * docs(lj): audit keyless ignition section for post-merge consistency + citations
    Reconcile drift left by the keyless-go merge conflicts and bring the
    section up to the repo's Rule 7 citation standard.
    Consistency fixes:
    - Cole Hersee 24213 coil current: 1.6A -> 0.69A (cited Littelfuse value)
    in keyless firewall-crossing table and starter wiring table
    - starter.md: "Firewall pin TBD" -> "Firewall Pin 15" (matches firewall
    ingress pin map, engine-systems checklist, wire-distance reference)
    - starter.md: control solenoid rating 85A -> 200A (matches its own cited
    [^ch-24213] datasheet footnote)
    - runaway-protecti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
2026-06-01 Harness build sheets with LJ tub-map visuals (#37)
    * Refactor harness inventory into per-diagram build sheets with tub-map visuals
    Restructures the Wire Routing harness docs around the three Jeep LJ Tub Map
    diagram pages so a harness builder has a single, visual reference per system:
    - 1.7.3 Harness Inventory becomes the overview: build-sheet index, H1-H9
    summary table, wire-color convention key, harness map, bundle interference
    assessment, cabin trunk summary, and optimization notes.
    - New 1.7.4/1.7.5/1.7.6 build sheets (Power Distribution; Lighting & SwitchPros;
    Controls, Recovery & Drivetrain) each embed their tub-map diagram and carry
    the per-harness build cards. Adds a Color c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
2026-06-02 docs: nightly tidiness — trim verbosity (2026-06-01) (#43)
    Remove prose that restates adjacent tables or product-info blocks, cut
    post-decision advocacy that serves no reader persona, and condense an
    over-justified engineering-justification section to its core facts.
    https://claude.ai/code/session_01TKw73P8Eic84uUYizRvNWQ
2026-06-03 docs: nightly tidiness — trim verbosity (2026-06-02) (#46)
    Remove 43 lines of prose that restated tables, repeated adjacent content,
    or consisted of generic practice not specific to this build.
    https://claude.ai/code/session_017A6gjetTJndLNMDsGq64fz
2026-06-03 Generate TBD tracker from GitHub Issues (Zensical native macro) (#45)
    * feat(docs): generate TBD tracker from GitHub issues (Zensical macro)
    Move TBD tracking from hand-edited markdown tables to GitHub Issues as the
    source of truth, rendered into pages at build time. This eliminates the merge
    conflicts caused by many PRs editing rows in the same shared tables.
    How it works:
    - tbd_macros.py defines a `tbds()` macro that fetches open issues labeled `tbd`
    once per build and renders them as Material admonitions grouped by priority.
    - Filtering by project (vehicle) and area (doc section) auto-derives from the
    page path; override via tbds(project=..., area=..., scope=..., priority=...).
    - La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
2026-06-03 Resolve nightly health digest #44 + reconcile DRL load analysis (#109)
    * Resolve nightly health digest #44
    Build & link integrity:
    - Migrate deprecated tags_file -> material/tags directive (fixes strict build)
    - Fix 5 image links with wrong ../../images/ depth
    - Drop broken subwoofer image ref; track as Outstanding Item
    - Add nissan_nv + jeep_jku index stubs (phantom nav / empty page)
    - Remove orphaned, unreferenced [^tc-ratio] footnote
    Spec contradictions (conform to authoritative PMU outputs):
    - DRL output Out 9 / Out 14 -> Out 23 (7A channel, ~2.6A load) repo-wide
    - DRL ignition sense In 6 -> Pin 7 in drl-parking and CT4
    - Firewall connector Deutsch HDP20 -> HDP24-24-29
    - Nav BCDC Alpha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
2026-06-03 docs(lj): nav refresh, landing page refresh, tub-map deploy fix (#112)
    * docs(lj): nav refresh, refreshed landing page, tub-map deploy fix
    Promote TBD Tracker and Standards Exceptions to section headers in the
    left nav (single-child index sections), drop "Build Sheet:" prefixes
    from harness wiring page titles, and refresh the LJ landing page to
    match current architecture (iBooster brakes, keyless ignition, drivetrain
    and installation sections). Default harness sleeve flipped to black
    braided + per-harness tracer; prose drift across the build sheets
    updated to match.
    Replace the MkDocs `copy_export_assets.py` hook (no-op under Zensical on
    Cloudflare Pages, causing 404s for the LJ tub-map PN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
2026-06-03 docs(lj): number Standards Exceptions as 1.9 (end of Power Systems) (#116)
    * docs(lj): number Standards Exceptions as 1.9 (end of Power Systems)
    Give the Standards Exceptions doc a section number consistent with its
    numbered siblings (1.1-1.8). Move it from the top of Power Systems to the
    end as 1.9, and prefix the page H1 to match. File path unchanged, so
    inbound links (path-only) are unaffected.
    * fix(build): stop Zensical crash on tbd(N) macro example in CLAUDE.md
    Zensical (Cloudflare Pages) does not honor mkdocs.yml `exclude_docs`, so it
    renders CLAUDE.md files that mkdocs skips. Its macro step is a line
    preprocesso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
2026-06-04 docs(lj): amp under-seat mount via vibration isolators on floor rivnuts (no fab plate) (#121)
2026-06-04 Add START battery key-off parasitic budget; resolve PBS-I quiescent (#84) (#122)
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2026-06-06 docs: nightly tidiness — trim verbosity (2026-06-04) (#126)
    Cut prose that restated adjacent tables or pseudocode, and generic
    operational-advice sections that served no reader persona.
    - pmu-arb-load-shedding: remove "Purpose" section (word-for-word
    restatement of the intro + Dual Battery Architecture section);
    remove "Solution Overview" opening sentence (same restatement);
    remove "Long-Term Monitoring" section (generic tracking advice —
    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
2026-06-06 docs: nightly tidiness — trim verbosity (2026-06-05) (#128)
    Cut filler prose and restated content from 6 pages. No specs, numbers,
    tables, TBD items, link definitions, or product-info blocks changed.
    - index.md: Remove boilerplate Documentation Notes admonitions; collapse
    Print/Download to link + one-line description (cut generic how-to-print steps)
    - winch.md: Remove Winch Mounting and Control Switch Location subsections
    (restated product-info and Control System section); remove duplicate
    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
2026-06-06 docs(runaway): record measured turbo inlet OD; correct AMOT intake adapter (#54) (#131)
    Measured R2.8 turbo inlet tube at 2.125" OD / 1.63" ID (first-party, in
    hand), well below the 2.5" estimate. The 4261M02 is a wafer butterfly that
    sleeves into the 2.8" intake duct with no NPT air-path port, so the prior
    "NPT-to-hose adapter" was wrong; connection is via 2.8" -> 2 1/8" reducer
    couplers. Closes #54; exact reducer sizing tracked in #129.
2026-06-06 Remove WAIT-gate relay (watch the lamp) + lockout design note; BODY PDU relay spec (#130)
    * Remove WAIT-gate relay; resolve BODY PDU 12V relay spec
    Cold-start grid-heater wait is now driver-managed via the Cummins
    WAIT-to-Start lamp (Digital Guard Dawg's documented diesel start
    procedure), eliminating the external SPST WAIT-gate relay and its ECM
    Pin 35 coil tap. PBS-I PURPLE START drives the Cole Hersee 24213 coil
    directly via firewall Pin 15. Resolves the Pin 35 sink-rating question
    (closes #117) and drops the orphaned Bosch changeover-relay and
    Pin 35-polarity footnotes.
    BODY PDU: the K40/K42/K53 24V->12V replacement is the panel's own
    Song Chuan 301-1C-C-R1 relay in U01 (12V) trim (clo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
2026-06-06 docs: nightly tidiness — trim verbosity (2026-06-06) (#133)
    Remove generic boilerplate and prose that merely restates adjacent tables
    or product-info blocks across three pages.
    https://claude.ai/code/session_01Y5YBzUWkBR7di88k9Z77c8
2026-06-07 Move radiator fan, iBooster, and TCU off the PMU to a START+ forward distribution bus (#137)
    Relocates three critical loads off the ECUMaster PMU24 onto START-battery-direct
    power, decoupling braking assist, engine cooling, and transmission control from a
    single active module (and from the PMU's shared 250A feed). Forward-distribution
    architecture mirrors the AUX side: one 150A master breaker at the battery feeds a
    single 2 AWG cable to an engine-bay START+ busbar that fans out to per-load breakers
    (fan 60A, iBooster 50A, TCU 25A) on short local feeds.
    - Radiator fan: START-direct power + a dedicated brushless-fan controller with its
    own coolant sensor (independent of PMU/J1939), commandi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
2026-06-07 docs(radiator-fan): identify the fan controller as the Lingenfelter VSFM-002 (#138)
    #137 (merged) already moved the radiator fan, iBooster, and TCU off the PMU
    onto the START+ forward distribution bus, leaving the fan controller part
    number open as issue #134. This pins that down: the GM 84100128 brushless
    fan is driven by the kit's Lingenfelter VSFM-002 PWM controller on its own
    coolant sensor.
    - Name the VSFM-002 (with a cited footnote) in the radiator-fan page,
    START forward-bus note, PMU programming note, load analysis, both install
    checklists, and the purchase tracker (price ~$190).
    - Keep #134 open and narrowed to what's still unverifiable from the
    datasheet: the coolant-sensor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
2026-06-07 Restructure repo for shopmanual.io: extract non-vehicle drawings (#142)
    Extract the Backyard WIring and bbq drawings (moved to a separate private sob/drawings repo); keep vehicle drawings and the published docs. Make TBD repo resolution follow $GITHUB_REPOSITORY, and poi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
2026-06-07 Redesign front page as a shopmanual.io landing page (#143)
    * Redesign front page as a shopmanual.io landing page
    Replace the generic docs index with a real landing page: a hero, an
    opinionated mission line, clickable project cards (Jeep LJ featured; NV
    3500 and JKU marked "coming soon"), and a "How it's built" section
    covering the stack (Markdown/MkDocs, draw.io export, CI, issue-based TBD
    tracking, print/PDF, public repo). Drops the noisy cross-project TBD dump
    from the home page.
    The hero, bands, and cards are self-contained HTML + CSS (no dependence
    on Material grid-card or icon sets) so they render identically under the
    production Zensical build.
    Also rebrand the site as shopmanual.io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
2026-06-11 Resolve build design-review findings: doc fixes + TBD issue tracking (#157)
    * Fix cross-section doc defects from build design review (non-power sections)
    Resolved from the four-agent design review, excluding open TBD topics:
    - Brake booster: remove brake-switch tap into the crank chain (Firewall
    Pin 15 is the PBS-I PURPLE START output); brake switch feeds the PBS-I
    Brake input, T-tapped with PMU In 2 and the Turbolamik TCU. Same fix
    applied to the engine-systems checklist step.
    - CT4: ignition input rewired in docs from the deleted keyswitch RUN
    Y-split to the cabin ignition bus Terminal 1 (PBS-I PINK IGN).
    - SwitchPros SP-1200: OUTPUT-5/OUTPUT-8 harness rows now match the
    contro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
2026-09-16 docs(lj): 1-ton axle swap — Super Duty Dana 60 front, Sterling 10.5 rear, brakes page (#296)
    * docs(lj): rear axle moves to Ford Sterling 10.5 with ARB RD140
    Replace the TJ Rubicon Dana 44 rear axle page with the 1-ton Sterling
    10.5 build (2005-2010 F-350 SRW donor, 5.13 Revolution F10.25-513L in
    the 10.5 housing, ARB RD140 air locker, factory 35-spline full-float
    shafts, Motobilt truss and cover, 1350 strap yoke) and propagate the
    change to every page that referenced the old rear axle.
    Review findings folded into the page:
    - Revolution's own listing says install kit 35-2046 covers 1999-2007
    10.5 housings only; 2008-2010 housings also need the SK F10.5-Conv
    pinion spacer. Added as a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
2026-09-17 docs(lj): CT4 and iBooster purchases, axle breather, no-ABS decision (#306)
    * docs(lj): record Command Touch CT4 and iBooster as purchased
    Move the Command Touch CT4 from the High Value to-purchase table into
    Purchased Items and add a Status line on its page. The Bosch iBooster
    donor was already recorded as purchased (2026-05-30) but still sat in
    the Medium Value to-purchase table; move it into Purchased Items and
    add a Status line on the brake booster page.
    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
2026-09-17 docs: nightly tidiness — trim verbosity (2026-07-04) (#158)
    Cut prose that restated adjacent tables/diagrams or repeated the same
    conclusion within a file, and one unsourced appeal-to-authority list, per
    the BE SUCCINCT rule in docs/jeep_lj/CLAUDE.md. No specs, numbers, part
    numbers, table rows, or TBD/checklist items were changed.
    Claude-Session: https://claude.ai/code/session_01SNGx2g9BzrFBeekSzbb85U
2026-09-17 docs: nightly tidiness — trim verbosity (2026-07-04) (#160)
    Cut prose that restated an adjacent table or duplicated content
    already documented on the authoritative page: repeated numbers in
    04-solar.md and 05-pmu-arb-load-shedding.md, CT4's copy of the
    DRL/headlight wiring and PMU auto-off logic, dash-camera's
    Components section, and installation-notes bullets in gmrs-radio.md
    and intercom.md that just repeated their own wiring tables.
    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
2026-09-17 docs: nightly tidiness — trim verbosity (2026-07-08) (#167)
    Cut same-file/cross-file restatements of already-documented rationale:
    the XL Sport lighting-spec correction narrated twice per file in the
    load-analysis pages, the START+ forward-bus tradeoff explained twice in
    one page, and the SwitchPros TRIGGER-3 pressure-control logic re-derived
    in the air-compressor page instead of linked to its authoritative source.
    Claude-Session: https://claude.ai/code/session_01C5ZQMKaMuzvRC1JaVKe11U
2026-09-17 docs: nightly tidiness — trim verbosity (2026-07-13) (#177)
    Cut prose that restated adjacent tables/diagrams and collapsed grid-heater's
    duplicated no-CB rationale into a cross-link to STANDARDS-EXCEPTIONS.md (the
    authoritative source), matching the winch.md pattern. No specs, numbers, or
    links changed.
    Claude-Session: https://claude.ai/code/session_01FUxVMABzC9H3QEN1V7oPMq
2026-09-17 docs: nightly tidiness — trim verbosity (2026-08-08) (#226)
    Nightly tidiness pass per docs/jeep_lj/CLAUDE.md's BE SUCCINCT rule. Cuts
    prose that restated an adjacent table, generic shop-practice advice, and
    a cross-file duplicate of pressure-switch logic already documented
    authoritatively elsewhere. No specs, values, identifiers, TBD items,
    checkbox items, table rows, frontmatter, or div.product-info blocks were
    touched — prose and structure only.
    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
2026-09-18 4WD/4LO indicators via NP241OR position switch; transfer case → TJ Rubicon Rock-Trac (#314)
    * Add 4WD/4LO indicators; switch transfer case to TJ Rubicon NP241OR
    Transfer case changed from the JK NV241 GenII Command-Trac (2.72:1) to
    the TJ/LJ Rubicon NP241OR Rock-Trac (4:1) per owner decision — deeper
    low range, ≈96.7:1 geared crawl, and native to the TJ/LJ chassis.
    Selection Notes reversed accordingly; specs, ratios, and footnotes
    re-sourced to Novak's NP241OR guide. The adapter research was done
    against the JK case and does NOT carry over — the whole adapter path,
    parts list, and fluid spec are flagged pending re-confirmation (#313),
    and the DomiWorks vendor email draft is rewritte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
2026-09-19 docs: nightly tidiness — trim verbosity (2026-09-19) (#316)
    * docs: nightly tidiness — trim verbosity (2026-09-19)
    Trim restated/generic content that fails the reader-persona test:
    BCDC temperature sensor install steps duplicated the wiring table and
    manufacturer-manual generalities; STANDARDS-EXCEPTIONS Standards
    Comparison / Review Guidance sections restated conclusions already
    given in the preceding Manufacturer Spec / Engineering Analysis
    sections for each component.
    Claude-Session: https://claude.ai/code/session_01S3qbJoUjERT4hFnUBFQzjw
    * docs: nightly tidiness — trim verbosity (2026-09-19), part 2
    Cut cosmetic/marketing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
2026-09-19 docs(nv): Starlink on the Advanced Power Supply, 12V DC direct (#4) (#317)
    * docs(nv): Starlink on the Advanced Power Supply, 12V DC direct (#4)
    Starlink now runs off a Starlink Advanced Power Supply fed straight from the
    van's 12V bank, so the 1000W inverter and the third-party Yaosheng PoE injector
    both come out of the Starlink path.
    Drawing (Van Electrical.drawio):
    - New "Starlink v3" page: Rear Powerswitch (B) -> Advanced Power Supply ->
    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
2026-09-21 docs(lj): resolve front ABS opening plugs to Riffraff RDPABS x2; narrow #310 to the rear (#318)
    Front wheel-end ABS openings on the Super Duty Dana 60 take Riffraff Diesel
    RDPABS grease-able block-off fittings, two required — one per knuckle, sold
    individually. The vendor supports permanent installation, which is the case
    here since the build runs no ABS at all and the tone rings are omitted. The
    zerk doubles as a grease port into the unit bearing, so the grease-able
    version earns its place over a plain plug.
    The front openings are into the wheel end rather than the gear oil, so unlike
    the rear housing window they are a grit-ingress path, not a leak path. Noted
    inline so the two ends are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
2026-09-24 docs(jku): swapped Rubicon e-lockers on the SP-9100; light bar not on the high-beam trigger (#322)
    * docs(jku): factory Rubicon electric lockers; light bar not on the high-beam trigger
    - Lockers are the factory Rubicon electric front/rear lockers (Stellantis
    2012 release), not air or vacuum. The 2012 owner's manual limits them to
    key in, 4L, <=10 mph via the factory AXLE LOCK switch, and unlocks them
    out of 4L or at ignition off. Wiring SP-9100 switches 4-5 to them would
    bypass those interlocks; keeping the factory switch is left as an open
    decision.
    - Light bar is manual only (owner, 2026-09-24); Trigger 2 (high beam) now
    has no output, so the page flags reclaiming backlight di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
2026-09-28 docs(lj): integrate the CT4 Turn Signal & Accessory Kit (#330)
    The CT4 was bought as SwitchPros' Turn Signal & Accessory Kit (GPS),
    plus an Axia Alloys 1.125" column clamp. Document what the kit
    supplies and where each part lands, checked against the CT4 manual
    (Rev. 1.0091524).
    - CT4: output allocation (kit ships SW3=horn, SW4=aux; this build uses
    both for headlights), kit contents table, clamp, GPS mounting rules,
    and the per-switch Ignition/Battery default (Ignition) that must be
    changed to Battery for the ignition-independent headlights
    - Horn: kit horn replaces the planned PIAA 85115, still on PMU Out 18;
    PIAA dropped from the purchase tracker
    - Front turn signals: the kit's 40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
2026-09-28 docs(nv): Vehicle page - tires, Viper SmartStart, service parts (#325)
    * docs(nv): Viper SmartStart fault, body electrical and service sections
    Document the 2026-09-25 headlight failure traced to an intermittent
    connection in the Viper/T-harness wiring behind the driver-side dash,
    with symptoms, scan results, fix, and follow-up items.
    Add Section 3 (Body Electrical: Viper SmartStart, exterior lighting
    control path, IPDM E/R auto active test, fault history) and Section 4
    (Service & Maintenance: vehicle details, known concerns, service log,
    throttle/idle relearn, oil change spec). Update the NV overview and nav.
    Claude-Session: https:/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
2026-10-17 docs(lj): harness gauge review — MRBF post fuses, 1 AWG PMU feed, PMU output map fix, CT4/PBS-I to START+ bus, TCU back on PMU (#333)
    Resolves the 2026-10-13/17 harness gauge review:
    - PMU24: main feed 1 AWG + 150A MRBF (stud limit 150A per pinout v1.1);
    ground is 12 AWG on pin 25; output ratings corrected (O1-5/O12-16 25A,
    O6-11 15A); aux fans to OUT1/OUT16, Dakota HDX to OUT3, TCU to OUT15
    with Delayed turn off; terminal wire-range table and 16 AWG pigtail rule;
    no PMU output is CONSTANT at key-off
    - CT4 and PBS-I powered from the START+ Forward Distribution Bus via inline
    fuses through HDP24 pins 2/22; planned Critical Cabin PDU cancelled (#144)
    - Battery-side circuit breaker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
